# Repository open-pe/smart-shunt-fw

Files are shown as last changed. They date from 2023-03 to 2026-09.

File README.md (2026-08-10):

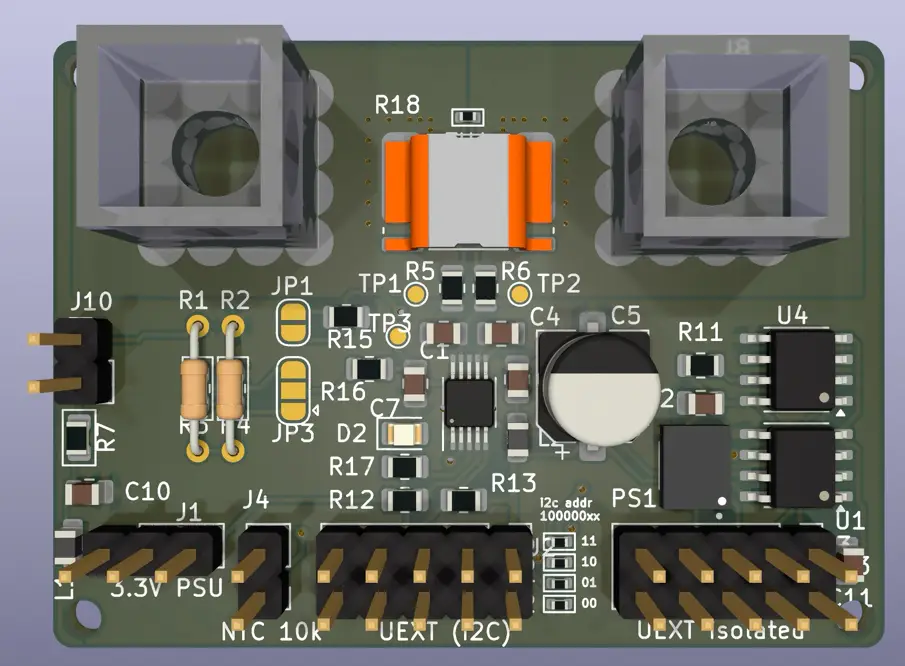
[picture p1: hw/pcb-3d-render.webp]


A versatile isolated power monitor based on INA228.
I made this for precision power metering and testing DCDC converters.

* Digital Signal isolators for i2c and alert
* Isolated power supply
* battery connector
* optional Vbus voltage divider for dc bus voltages above 85V
* programmable i2c address
* NTC for shunt temperature measurement (in addition to the INA228 internal temperature sensor)

# Building

## Platformio Setup

* [install script](https://docs.platformio.org/en/latest/core/installation/methods/installer-script.html)
* [setup shell commands](https://docs.platformio.org/en/latest/core/installation/shell-commands.html)
* [clion](https://docs.platformio.org/en/latest/integration/ide/clion.html)

select the board:

`pio run -e esp32s3`
or
`pio run -e stm32h5`

# TODO

- add ssa-100 plug?
- add ntc
- add pin header for chassis mount resistor
- jumper to disconnect on-board shunt?
- add RSN-50-50 footprint (no available)
- add external alert (for OC shutdown)
- add external IO pins?

Supported ADC:

* ADS1115 / ADS 1015 (for example with SSA-100)
* INA226 (16-bit)
* INA228 (20-bit, 85V)
* ADS1262 (32-bit)
* ADS131M0x (24-bit sim. sampling)
* TODO ADS127L11

On startup it detects the ADCs on the I2C bus using there default addresses.

I tested it on these MCUs:

* ESP8266
* ESP32
* ESP32-S3

The program reads voltage and current and computes power.
It integrates power for energy measurement using the trapezoidal rule.

# Output

* Serial (human friendly logs)
* UDP messages using InfluxDB line protocol

# Voltage Divider Resistors

Resistors with low temperature drift are favourable. Tolerance is not so important because we can simply calibrate.
Consider the ADC input impedance when designing the voltage divider.
Thin film or metal film resistors. Cheap ($.5) SMD chip resistors with 10ppm/°C.
Resistors with 5ppm/°C drift cost $2.
Choose resistors with equal drift, so drift get eliminated.

# Current Sense Resistors

https://www.researchgate.net/profile/Gunnar-Fernqvist/publication/224304168_Characteristics_of_burden_resistors_for_high-precision_DC_current_transducers/links/65ad0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
https://accelconf.web.cern.ch/p07/papers/MOPAN071.pdf
"The highest precision is offered by a proprietary Zeranin wire design from Hitec,"
=> Bulk Metal Foil or “foil”.

https://accelconf.web.cern.ch/p77/PDF/PAC1977_1810.PDF




10A <1ppm reference https://cds.cern.ch/record/643293/files/cer-002399330.pdf

https://www.datatec.eu/caenels-ct-100-c
https://www.datatec.eu/stromwandler-dcct
https://www.datatec.eu/caenels-ct-100v-p

A CT100-P with Y007810R0000B9L (10ohm, 0ppm/K) or 4-terminal Y169025R0000T9L (25ohm, 0.2ppm/K)
with 25ohms: 25mV/A (equiv burden 25mΩ, and almost no self-heat)

Low drift is important. Drift can be compensated with temperature measurement.
Consider max current and power dissipation. For resistances <=1mΩ it is hard to find low drift SMD chip resistors.
A chassis mount resistor might be a better choice for current measurement >40 A.

Riedon https://riedon.com/resistors/current-sense/
VPG

RUG-Z isabellenhuette

# Current Reference

https://doc.xdevs.com/doc/_Metrology/wang2014.pdf

# Resistor References

Tinsley 1682 https://www.ebay.com.au/itm/385633870779
J.L. William Scientific Instruments 0.1 Ohm Cal Standard DC Resistor (SN: 3127) (10 amp)
3928 (14amp)

## SMD Resistors

| MFR | MPN | mΩ  | P | Imax | tol | TCR | padW/mm | padH/mm | 4wire | px100 | |
|---|---|-----|-----|---|-----|---|---|---|---|---|---|
| isabellenhütte | BVR-Z-R0003-1.0 | .3  | 11W | | 1%  | 20ppm | 5.5 | 1.6 | y | $1.9  | |
| bourns | CSS2H-2512R-L300F | .3  | 6W  | | | 150ppm(50ppm) | 3.4 | 1.8 | n | $ | |
| Milliohm (CN)  | HoLRS5930-0.3mR-1% | .3  | 7W  | | 1%  | 50ppm | 7.6 | 4.2 | n | $.24  | |
| vishay | WSLP5931L3000FEA | .3  | 10W | | 1%  | 175ppm | 7.75 | 5.2 | n | $1.7  | |
| RESI (CN) | SEWF3951DL300P9 | .3  | 15W | | .5% | 25ppm | 13 | 2 | n | $2.2  | |
| isabellenhütte | BVR-Z-R0005-1.0 | .5  | | | 1%  | 20ppm | | | | | |
| | BVR-M-R0007-1.0 | .7  | 8W  | | 1%  | 20ppm | | | | | |
| | BVR-M-R001 | 1 | 7W  | | | 50ppm | | | | | |
| vishay | Y14880R00100D0R | 1 | 3W  | | .5% | 15ppm | | | y | | |
| | WSK12161L000FEA/B | 1 | 3W  | | .1% | 20ppm | | | | | |
| | Y14880R00200B9R | 2 | 3W  | | .1% | 15ppm | | | y | | |
| | Y14730R00300B0R | 3 | 3W  | 31A  | .1% | 5ppm | | | | | |
| | Y14750R10000B9R | 100 | | | .1% | 10ppm | | | | | |
| vpg | PCS301 | | | 15A  | | 15ppm | | | | | [pdf](https://vpgfoilresistors.com/products/current-sense-resistors/pcs301/datasheet) |
| | SHR 4-2321 0R005 S 1% M | 5 | 40W | | | 5ppm | | | | | |
| | SHR 4-2321 0R005 S 1% L | 5 | | | | 2ppm | | | | | |
| | PCS 301 0R100 S 1% | 100 | 30W | | 1%  | 3ppm | | | | | |

[Digikey Chip Mount Resistors 40ppm 1mΩ ](https://www.digikey.de/short/8dbrqrp4)

TODO TCR curve
https://docs.rs-online.com/2d4e/0900766b81142cbf.pdf

Choose Chassis Mount resistor, suchs as the 1mOhm RSN-100-100B with 15ppm/k

## THT Resistors



Riedon PCS (10ppm, 40W)
PCS-0R001D1

| MPN | mΩ | tol | P | Imax | TCR | px  |
|---|----|-----|-----|---|---|-----|
| VPG Y07340R05000G9L | 50 | 2%  | 10W | 14A  | 2ppm  | $82 |
| Riedon PCS-0R001D1  | 1  | | 40W | 200A | 10ppm | $40 |
| Riedon PCS-0R002D1  | 2  | .5% | 40W | 141A | 10ppm | $40 |
| Riedon PCS-0R005D1  | 5  | .5% | 40W | 89A  | 10ppm | $40 |
| PCS-0R01D1 | 10 | | 40W | 63A  | 10ppm | |
| | | | | | | |

Riedon USR 4- 3425 (3ppm, 30W, 0.01%)

## Chassis Mount Resistors

These commonly have lower tolerance and lower temp drift as compared to chip mount.
The larger surface of the resistive material and larger terminals decreases thermal resistance to ambient, which
reduces temperature rise.

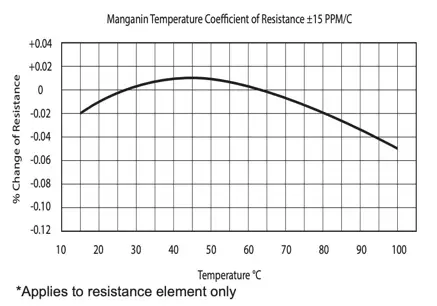
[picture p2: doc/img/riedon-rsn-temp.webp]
|  |
|:-----------------------------------:|
|  Manganin (Riedon RSN, RSW and RS)  |

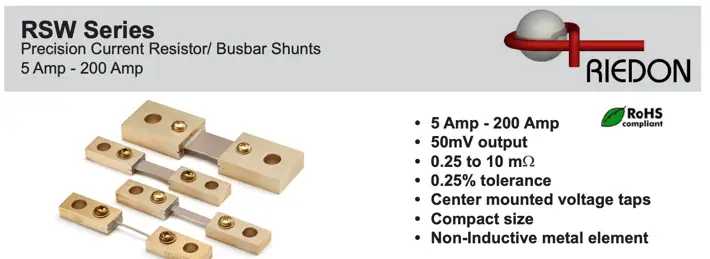
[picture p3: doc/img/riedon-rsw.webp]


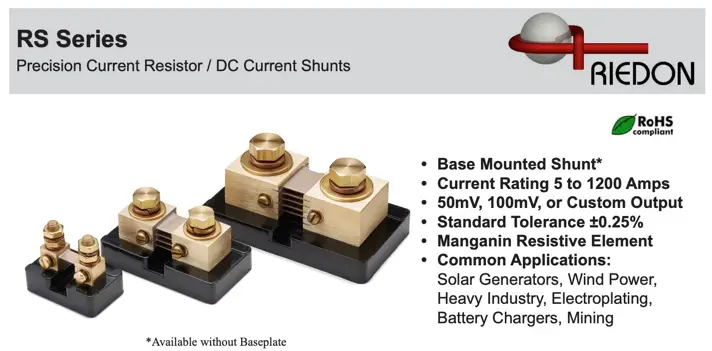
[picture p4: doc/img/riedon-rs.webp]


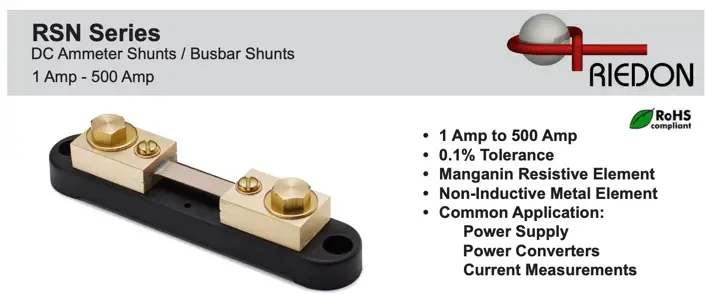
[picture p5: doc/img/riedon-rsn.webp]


| | mΩ | P | Tol | TCR/K  | px |
|---|----|---|---|---|---|
| Riedon RSW-50-50 | 1  | | 0.25% | 15ppm  | |
| Alpha FNPZR0040F | 4  | 500w | 1% | 1ppm | $1060 |
| Alpha FNPZR0010B | 1  | 500W | 0.1%  | 1ppm | $1040 |
| FNPYR0020A | 2  | | 0.05% | 2.5ppm | $540  |
| Riedon RSN-100-100B | 1  | 10W  | 0.1%  | 15ppm  | $60 |
| RSA-50-100 | 1  | 5W | 0.25% | 15ppm  | $30 |

## for battery monitoring

* SMD chip resistors are way cheaper (such as HoLRS5930-7W-0.25mR-1% )

| | mΩ | I(A) | tol | | | px |
|---|----|---|-----|---|---|----|
| Milliohm HoFL2-75A-75mV-0.5% | 1  | 75 | .5% | | | $5 |
| RESI ARCS8518JL100A9 | .1 | | .5% | | | |
| Milliohm HoFL3-8518-A-100uΩ-1% | .1 | | | | | |
| HoFL2-200A-60mV-0.5%-HS | .3 | 200  | | | | |

# 30A

ina228 has a shunt voltage range of 40.96 and 163.84 mV.
at a voltage drop of 40mV and 30A, we have 1.2 W of heat dissipation.

# applications

* bms/battery current sennsor
* smart shunt / lab shunt
* solar crowbar
* efuse
* mppt sensor

# set conversion time and averaging

* consder aliasing
* the ina22x ADC samples AND we sample the ina22x
* use conversion time to avoid aliasing during ADC
* use averaging to avoid aliasing during sampling the ina22x (i2c)
* when working with 50hz inverters, need a conversion time <=1ms.

# precision

* note that resistors change there resistance with temperature (see datasheet)
* use precision resistors
* keep temperature stable
* when measurement DCDC converter efficiency use 2x identical hardware. same chips and same resistors
* INA228 temp coefficient is 20ppm/°C, so choose resistor in that class
    * Ina228 features a temperature sensor

# AC Metrology

* Ti Design TIDU455A (MSP430AFE253, 24 Bit DeltaSigma ADC), class 0.2% accuracy
* Ti Eval Board EVM430-I2040S (MSP430I2040, 24bit, 8Khz or 80th harmonic of 50 Hz), <0.2% accuracy
    * AC, DC, 380V, 15 Amps
* Gossen Metrawatt Metrahit Energy (Starline Series) and
  Open-Source [IrDA USB](http://lemmini.de/IrDA%20USB/IrDA%20USB.html) (the Gossen USB X-Tra needs proprietary drivers,
  for windows only)
    * ESP32 has `UART_MODE_IRDA`, you only need the TFDU4101 [forum1](https://esp32.com/viewtopic.php?t=2766)

https://www.ti.com/lit/ug/tidua01/tidua01.pdf
https://www.analog.com/media/en/technical-documentation/data-sheets/ad637.pdf

* synchrounus subsampling (needs fast ADC)

* log-antilog

Thermal RMS Converters for ultimate


# EVM430

- the software "calibrator-20121120.exe" referenced in the datasheet is out-dated. I could not find a downlo
- use [MSP-EM-DESIGN-CENTER](https://www.ti.com/tool/MSP-EM-DESIGN-CENTER)
  , [intro](https://software-dl.ti.com/msp430/msp430_public_sw/mcu/msp430/EnergyMeasurementDesignCenter/1_40_00_03/release/EnergyMeasurementDesignCenter_1_40_00_03/docs/users_gu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)
  . works on Windows, Mac, Linux
- voltage sense (C14)  pin 1 and 2, A0.0+ and A0.0-
- Current Sense (C10) pin 3 and 4, A1.0+ and A1.0-
- there is a project "EVM430-i2040S_SH_1V_1C_50Hz"
- Double click the MCU and "Generate Code"
- Open generated src code project with CCSTUDIO
    - Could not get the online version to open the project (https://dev.ti.com/ide/)
    - the download IDE based on eclipse succeeded to build the generated project, but need MSP-FET programmer. not sure
      if an ordinary USB2UART addapter works?

# Isolated Current Sensor

DC-DC: MIE1W0505BGLVH-3R-Z (monolithic)
i2c: TPT72616-SO1R (3peak)

# Calibration

```

ina22x-resistor-range 0.000333333333333333 120
calibrate ESP32_INA228 U 1.00
calibrate ESP32_INA228 I 1.00

ina22x-resistor-range 0.0025 16
ina22x-resistor-range2 0.002 20  
ina22x-resistor-range3 0.002 20  

ina22x-resistor-range 0.001 40 
ina22x-resistor-range2 0.002 20 
ina22x-resistor-range3 0.002 20 

calibrate ESP32_INA228 U *1.000041
calibrate ESP32_INA228_2 U *1.000041
calibrate ESP32_INA228_3 U *1.0000233720530345

calibrate ESP32_INA228 I *1.0001119027192362
calibrate ESP32_INA228_2 I *0.9999067668612132

calibrate ESP32_INA228_3 I *1.0056727470362443

calibrate ESP32_INA228_2 U *1.00005
calibrate ESP32_INA228_3 I 1.0

calibrate ESP32_ADS1220 U *0.9985899493319389

calibrate ESP32_INA228 U *1.000032503295473
calibrate ESP32_INA228_2 U *1.000032503295473

calibrate ESP32_ADS1262 U 1.011406869687194   # an1->gnd
calibrate ESP32_ADS1262 U 1.0   # an1->gnd

calibrate ESP32_ADS1262 U 0.99882990

calibrate ESP32_ADS1262 U 1.01045

```

# Reference Designs

### LP-XDS110ET

[Design Files](https://www.ti.com/tool/LP-XDS110ET#design-files)

* ADC: ADS127L01IPBS
* Ref: REF6025IDGK (drift: 5ppm/K, noise: 5 µVRMS)
* Clock: SN74LVC2G74DCU
* Diff. Amp: THS4551IRUN
* Current Sense Amp: INA118UB

### ADS131B23



# Going Further

| error type | mitigation | effort |
|---|---|---|
| gain error | single point calibration | low |
| gain temp drift | temperature measurement | medium |
| non-linearity | multi-point calibration (LUT) | medium |
| noise | averaging | low |

Simulatnous 2ch sampling instead of multiplexing.
Alternative: use 2 ADC chips

* ADS127L01 + THS4551 + INA169? ( see LP-XDS110ET circuit )

ADS131B23:

* 2x 24bit for redundant current measurement
* 1x 16bit for voltage measurement

# Selection Criteria

* Simultaneous sampling
    * more precise AC power sampling
    * easier to program
* PGA gain of >= 64
    * enable FSR of 40mV to directly measure voltage across current sense resistor without additional
      amplifier
* Linearity
    * Linearity can be improved with a look-up-table. Creating these tables require multi-point calibration.
    * Compare linearity error from the ADC data sheet to the temp drift of current sense resistor

# Voltage References

| MPN | drift/K | noise | initial accuracy | |
|---|---|---|---|---|
| REF6025IDGK  | 5ppm | 5 µVRMS  | ±0.05% | |
| REF6225IDGKT | 3ppm | 5 µVRMS  | ±0.05% | [pdf](https://www.ti.com/lit/ds/symlink/ref6225.pdf) |
| LTC6655 | 2ppm | | ±0.025% | for use with  LTC2508-32 |
| LTC6652 | 5ppm | | 0.05% | |
| LTZ1000 | 0.05ppm/°C | 1.2µVP-P | | for calibrators |



https://youtu.be/upTgM_S5rAQ?si=JQq38q3_NsaYmSlv&t=2213

Fluke732A

https://github.com/marcoreps/ADRmu

Reference of all References
https://hackaday.com/2015/12/03/nuts-about-volts/
https://www.ptb.de/cms/service-seiten/news/forschungsnachricht.html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




# Voltage Divider

VHD200 (digikey 15 weeks )
100mW. for measuring 80V at 2V ADC min 64k r_total


# Amps

THS4521 (ref6225)

# ADC Break-outs

https://protocentral.com/product/ads1115-16-bit-adc-4-channel-with-programmable-gain-amplifier/

https://protocentral.com/product/ads1220-24-bit-4-channel-low-noise-adc-breakout-board/

https://protocentral.com/product/protocentral-ads1262-32-bit-precision-adc-breakout-board/

https://www.mikroe.com/adc-15-click

https://www.waveshare.com/18983.htm (ADS1263)

MIKROE-4743 (ADS1262) 

# Misc

# Resolution and Noise

from https://www.ti.com/lit/ds/symlink/ads1231.pdf :
The RMS and Peak-to-Peak noise are referred to the input. The effective number of bits (ENOB) is defined as:
ENOB = ln (FSR/RMS noise)/ln(2)
Noise-Free Bits = ln (FSR/Peak-to-Peak Noise)/ln(2)
FSR (Full-Scale Range) = VREF/Gain.

https://electronics.stackexchange.com/questions/274606/whats-the-highest-precision-achieved-for-an-adc

Let's consider the application of measuring conversion efficency of a DC/DC converter.

According to the data sheet, INA228 measures power with total meusurement
error of 0.5% at full scale. We need two power monitors, one at the input and one at the output, total worst case error
of two devices is around 1%.

This error is too high, considering the DC/DC has an efficiency of > 95 %.
So let's have a look at more precise alternatives.

First

| | | |
|---|---|---|
| Gain Err (max) | ±0.05 % | |
| Gain Temp Drift (max) | 20 ppm/°C | |
| ADC Resolution | 20 bit | |
| Integral Non-Linearity | 20 ppm | |
| Differential Non-Linearity | 0.2 LSB | |

For noise analysis, we need to define ADC measurement range and AC component frequency.
What is the ripple current, voltage and frequency?
Is the ripple periodic?
Is the ripple neglictable?
Can we smooth is out with a LP filter so we can assume DC only?
What digital filter does the ADC have?
Do we need an analog filter? Do we need to filter Aliasing?

TODO

* zero cross detection?
* AC metering?
* simulatnous filtering AC?

To work with some numbers, we define a working point:

- max current 40A
- current sense resistor 1mΩ
- max heat: 1.6 W (i2r)
- max voltage 40mV

* define a sampling rate
    * do we need to capture AC component or can we filter them?
    * if reactive power matters, we need simultanous ( https://www.ti.com/lit/an/slaa638a/slaa638a.pdf )

"The sample frequency is [...] 8 kHz that give us Nyquist
bandwidth of 4 kHz. This bandwidth is sufficient to cover the 66th harmonic for 60Hz AC, 80th harmonic for
50Hz AC frequency as wider bandwidth is usually needed for server power monitoring due to the nature of the
switching power supplies being monitored." -https://www.ti.com/lit/an/slaa638a/slaa638a.pdf

* :
* (max):
*

Note 7: Integral nonlinearity is defined as the deviation of a code from a
straight line passing through the actual endpoints of the transfer curve.
The deviation is measured from the center of the quantization band.

- https://www.ftcelectronics.sg/datasheets-58/LTC2508CDKD-32-TRPBF.pdf

# SPI Isolators

https://www.analog.com/media/en/technical-documentation/data-sheets/LTC6820.pdf
(needs 2 chips and 2 transformers)

https://www.mikroe.com/spi-isolator-5-click
using DCL541A01 (150Mbps, 3f/1r channels, default Low out)

https://www.electronics-lab.com/project/4-channel-spi-interface-isolator-with-three-forward-and-one-reverse-direction-channels/
based on ISO77418 (100Mbps, 5000V iso, 3f/1r ch, default High out)


# Tools

https://www.vishay.com/en/resistors/change-resistance-due-to-rtc-calculator/

# Heaters

https://www.amazon.de/Fyearfly-Temperatur-Heizplatte-Silikonkautschuk-elektrische/dp/B09MJ96BHK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
https://www.digikey.de/en/products/detail/dfrobot/FIT0845/15848056
https://www.amazon.de/sourcing-map-selbstklebende-Heizelemente-Heizstreifen/dp/B0CTT8DCNG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
https://electronics.stackexchange.com/questions/631263/using-mosfet-as-a-voltage-controlled-current-source


https://www.digikey.de/en/products/detail/innovative-sensor-technology-usa-division/HST-P11R0-1010-63A-2L-020/21407273


https://www.digikey.de/en/products/detail/riedon-products-by-bourns/PTCA-40/10271325

# Peltier

https://www.farnell.com/datasheets/4020641.pdf

# Heating Circuit

We want a precise temperature control loop to stabilize temperature of the resistive element.
The heater should be somehow coupled to the resistor for good heat transfer and it also needs
a heat-sink. We decide against PWM, since efficiency is not an issue, as we want to generate
heat anyway and it might cause unnecessary switching noise.

A linear control loop appear to make most sense. There are circuits like



the NTC is a LC471F3K, nominal 470 X at 25 °C, which acts as a sensor and heating element.

Despite the simplicity of this circuit, it not suitable in our application.
Measuring the temperature at the resistive element is important, since the resistor itself will produce heat.
Also finding an NTC with suitable power will likely be difficult.

We will measure

https://www.wellesu.com/10.1016/j.compag.2016.06.011
https://dr.lib.iastate.edu/server/api/core/bitstreams/d64d1b18-f1b3-41cd-be34-bc21360b506e/content
https://electronics.stackexchange.com/questions/690961/i-dont-understand-this-temperature-controller-circuits-behaviour
https://electronics.stackexchange.com/questions/498065/anemometer-with-opamp

https://www.circuitlab.com/circuit/63742k8e26j4/ntc-heater-control/

# Increasing Precision

The INA228 data sheet mentions a power monitoring accuracy of 0.5%. For monitoring DC/DC converters
with efficiencies of 95% or higher, INA228 accuracy is not sufficient. The integrated 0.5% precision oscillator adds
even more error for energy measurement.

# ADS1262 Journal

* ordered from protocentral
* are these genuine chips?
* review passive component circuitry of break-out board
* ads1262 needs at least 4.75V analog supply voltage !
* prefer MIKROE-4743 from digikey
* with PGA need at least 0.3V margin to rails (see Datasheet)
* linearity issue
    * sth appears to be wrong
    * absolute error seems quite high
    * maybe there is something wrong with the code?
* ads1220 appears to perform quite well
    * todo need spi isolator

# Measuring Single-Ended Signals with Diff-ADC

https://www.ti.com/lit/an/sbaa133a/sbaa133a.pdf?ts=1738999464967


THS4551







LTC2057 + LTC2508-32

# Current sense ampplifiers

MCP6C02

# Instrumentation AMps

- focus on precision (low noise, low offset, linearity)
- differential gain
- high CMRR
- high input impedance, low output impedance




https://www.ti.com/lit/ds/symlink/ina118.pdf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,0,96
https://www.ti.com/solution/battery-cell-formation-test-equipment?variantid=34913&subsystemid=292016

| | | max gain | noise | offset voltage (max) | offset drift (max) | gain drift ppm/K  G=1/G>1 | gain nonlinearity | common mode rej | |
|---|-----|---|---|---|---|---|---|---|---|
| **INA190** | | | 75 nV/√Hz | ±15 μV | 0.08 uV/°C | 7 ppm/°C | 100ppm | | |
| INA848 | | 2000 (fix)  | 1.5 nV/√Hz | 35µV | 0.45 μV/°C | 5 | 10ppm | 132dB (min) | |
| **INA851** | | 1000 | 3.2 nV/√Hz | 35 µV | 0.3 µV/°C | 5/35 | 5ppm  (typ) | 120db (min) | with fully diff outp. |
| INA849 | | 10000 | 1-nV/√Hz | 35 µV | 0.4 μV/°C | 5 | 10ppm | | for bat test |
| INA826 | | | 18 nV/√Hz (G>=100) | 150 µV | | 1/35 | 5ppm | | bat test |
| ina828 | | | 7 nV/√Hz | 50 µV | 0.5 µV/°C | 5/50 | 15ppm | | |
| INA2128 | | | 8 nV/√Hz at 1 kHz | 50µV | 0.5 µV/°C | ±10ppm | | 120db (min) | |
| INA103 | | | 1nV/√Hz | | | ? | 100ppm | | |
| **INA818** | | | 8 nV/√Hz | 35µV | | 5/35 | 15ppm (max) | | |
| INA118 | | | 10nV/√Hz | 50µV | 0.5 µV/°C | | 20ppm | | |
| INA333 | | | 50 nV/√Hz | 25 μV | 0.1 μV/°C | | 10ppm | | |
| AD624C | | | | | | | | | |
| LTC6915 | $9  | 4096 (prog) | 2.5µVP-P (0.01Hz to 10Hz) | 10µV | 0.05µV/°C | | 15ppm  (max) | | |
| INA241A | $3  | | 28nV/Hz | 10µV | | 1ppm | 10ppm | | |
| LTC1100 | $18 | 10 or 100 | ■ 0.1Hz to 10Hz Noise: 1.9µVP-P | 10uV (typ 1µV) | 0.1µV/°C | 4ppm | 8ppm (max) | | |
| **LTC2053** | $10 | 1000 | 2.5µVP-P (0.01Hz to 10Hz) | 10µV | 0.05uV/°C | 0 | 3(typ) 12 (max) | 116db (typ) | |
| LT1167 | | | 0.1Hz to 10Hz Noise: 0.28μVP-P  | G = 10, 60μV Max | 0.3μV/°C | 50ppm ? | G = 10, 10ppm Max | | |
| LTC6363 | | | 0.2µVpp, DC to 10Hz (Typ) | | 0.015μV/°C | | | 150db (typ) | |
| MCP6C02(G=20) | | | <=1Hz:0.48μVpp, 1.54 | G=20: 16µV | 0.09 µV/°C | 5ppm | 50ppm/100ppm | | current sense amp |





LNA10 (OPA4727) see https://www.youtube.com/watch?v=NoCp6cz32yo
Stanford Research SR560

https://www.thorlabs.com/thorproduct.cfm?partnumber=AMP100
https://github.com/marcoreps/low_noise_amplifier


LTC2057HV + LT1991A

# Op Amps

OPA4727
offset: 15µV (typ), 150µV (max)
drift: 0.3µV/°C (typ), 1.5µV/°C (max)
BANDWIDTH: 20MHz
LOW NOISE: 6nV/√Hz at 100kHz
AOL > 110dB

OPAx209
(higher drift, lower noise)
: 2.2 nV/√Hz at 1 kHz
Low Offset Voltage: 150 µV (Maximum)
drift: 3 µV/°C (max)

OPAx189
– Zero-drift: 0.005 μV/°C

- Ultra-low offset voltage: 3 μV maximum
  – CMRR: 168 dB
- en at 1 kHz: 5.2 nV/√Hz
- 0.1-Hz to 10-Hz noise: 0.1 µVPP

OPAx388

- offset voltage: ±0.25 µV
- drift ±0.005 µV/°C
- 140-dB CMRR
- Low noise: 7.0 nV√Hz at 1 kHz
- No 1/f noise: 0.14 uVPP (0.1 Hz to 10 Hz)
- https://www.ti.com/solution/analytical-lab-instrumentation#block-diagram
-

# Youtube

https://www.youtube.com/watch?v=upTgM_S5rAQ
https://www.youtube.com/watch?v=NoCp6cz32yo

# Literature

https://docs.ampnuts.ru/eevblog.docs/HP_Agilent_Keysight/HP%203458A%20Component-Level%20Information%20Packet.pdf
https://vtda.org/pubs/HP_Journal/HP_Journal_1989-04.pdf
https://doc.xdevs.com/doc/HP_Agilent_Keysight/3458A/ac_algo/Swerleins_Algorithm.pdf

* highest accuracy for lowest freq

# DataLogging

https://github.com/marcoreps/multiinstrumentalist

* HP3458A
* HP34420A
* W4950
* F8508A
* K2182A
* D1281

# Temp Sensors

TMP117 (i2c)

# ADC

important for dc metrology: stability and linearity (DC to 103- 104 Hz )
https://www.researchgate.net/publication/325285614_Analog-to-digital_conversion_beyond_20_bits_Applications_architectures_state_of_the_art_limitations_and_future_pro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

https://www.ti.com/lit/ug/tiduco9b/tiduco9b.pdf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

https://indico.cern.ch/event/814368/contributions/3397918/attachments/1832255/3000935/Class_0_ADC_-_Beev.pdf

https://www.welectron.com/Digilent-MCC-172-IEPE-Sensor-DAQ-HAT-for-Raspberry-Pi-2-CH-24-bit

# Thermal EMF

https://www.ab-precision.de/products/cables-accessories/

https://www.ni.com/docs/de-DE/bundle/ni-switch/page/thermal-emf-and-offset-voltage.html

https://www.youtube.com/watch?v=EW58sm8ciWk


https://www.youtube.com/watch?v=KiYhEP6m7Pc


https://dam-assets.fluke.com/s3fs-public/p18-21.pdf

https://www.eevblog.com/forum/metrology/binding-postsbanana-sockets-cleaning-on-dmmsmetrology-lab-gear/

https://www.eevblog.com/forum/chat/help-wanted-low-and-high-ohm-measuremet/?action=dlattach;attach=35289

Pomona 2305

diy Fluke 5440A-7003
https://www.eevblog.com/forum/metrology/diy-low-emf-cable-and-connectors/msg545213/#msg545213

Riedon RSN Brass Terminals:
Thermal EMF to copper wire ~2µV, at 50mV FSR this is 40ppm.

# Gold Plated Banana Plugs

CT3099


[Pomona 4897-2](https://www.digikey.de/en/products/detail/pomona-electronics/4897-2/737024)

https://mm.digikey.com/Volume0/opasdata/d220001/medias/docus/4846/DS_1768_Catalog.pdf

Multicomp 1699021

Farnell has more than digikey

# Kelvin Clips Gold Plated

CTM-78K
CTM-75K

# Linearity, INL

https://xdevs.com/article/inlperf/



# CERN HPM7177 (open soruce) DMM

https://ohwr.org/project/opt-adc-10k-32b-1cha/-/wikis/home
base on AD7177-2
effective resolution >23 bits for BW < 10 Hz
temperature drift (offset and gain) <0.1 ppm/°C from 20°C to 40°C
INL <0.6 ppm (0 to +10 V)



# Notes on Precision

High-Precision (ppm range) current sensing can be tricky due to thermal effects.
Most resistors have a positive temperature coefficient when they heat up, so current is measured too high.
A closed-loop temperature control of the current sense resistor can improve stability.
There are Vishay VPG resistors with 0ppm/K or <1ppm/K, but only in the sub-1W range, so not suitable for higher
currents.
Low burden voltage decreases resistor heating but Thermoelectric noise (thermal EMF) becomes more dominant.
Use as few material boundaries, not connectors, no gold, just copper. Use un-finished copper trace to contact resistors
with screw terminals, which are usually some sort of brass.

Offset drifts can be compensated with a chopper circuit, that frequently bypasses the load current and measures the
offset current
which is then compensated in following measurement.

If you want to measure ratio of currents, use the same sense resistors and chop both currents over it to eliminate
drift.
This way any error produced by the resistor is eliminated, offset by thermal EMF is still relevant and the ADC
performance
(offset and linearity).

For best linearity, highest thermal imunity and lowest drift, consider using DC-current transformers (DCCT).

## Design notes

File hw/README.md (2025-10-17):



This is a energy monitor based on the INA228.
It comes with a Würth PowerPlus M5 terminals and a 4026 shunt resistor slot for resistors from e.g.
Bourns, Vishay, Isabellenhütte.
Alternately you can use chassis mount resistors such as the Riedon RSN series with very low temperature drift.

The board comes with an isolated dc-dc and i2c isolator (and another isolator for the alert signal).

## Measuring voltage >85V

Although the INA228 only supports Vbus up to 85V you can measure much higher voltages (I tested up to 400V DC).
Put the shunt on the ground sound and populate the voltage divider with THT precision resistors or SMD chip resistors.

For high voltages higher than 85V the `IN-` pin must be pulled to ground. There will be a lot of noise otherwise.

# isolators

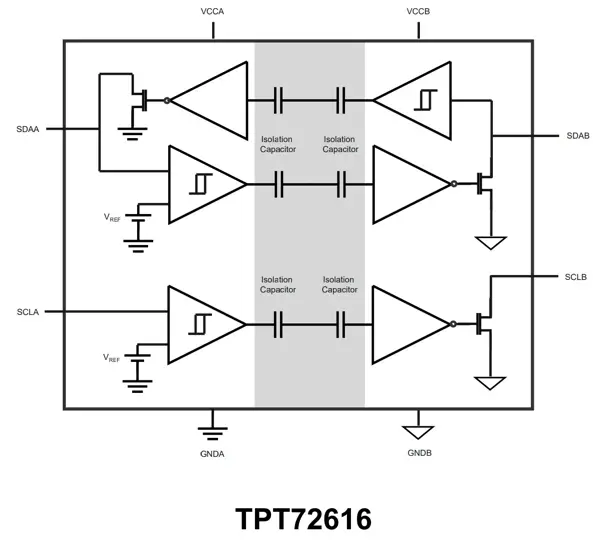
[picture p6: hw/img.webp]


TPT774x:

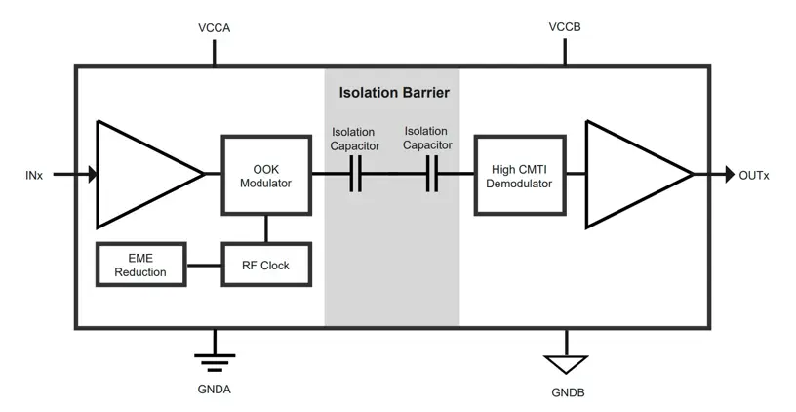
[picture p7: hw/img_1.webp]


TPT7721-SO1R:
2 ch

FXMAR2102UMX:
2ch bidirectional! $.32

INA241

* motor drives
  https://www.ti.com/de-de/video/6314459715112

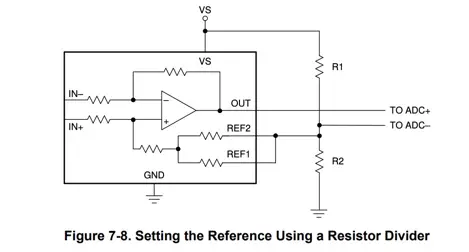
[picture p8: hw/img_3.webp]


INA296A

* Version A: ±0.01%, ±1ppm/°C drift
* app: Test & Meausrement
* https://github.com/CrabLabsLLC/OpenMD/blob/develop/docs/Schematic.pdf
*

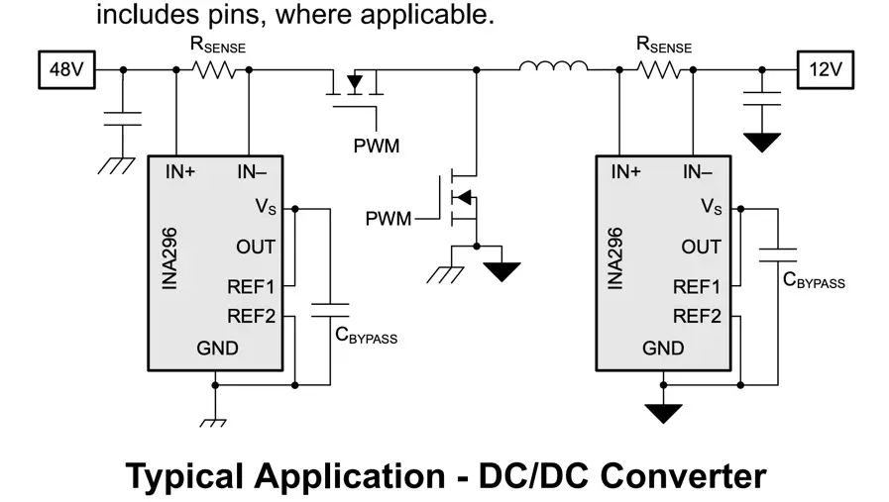
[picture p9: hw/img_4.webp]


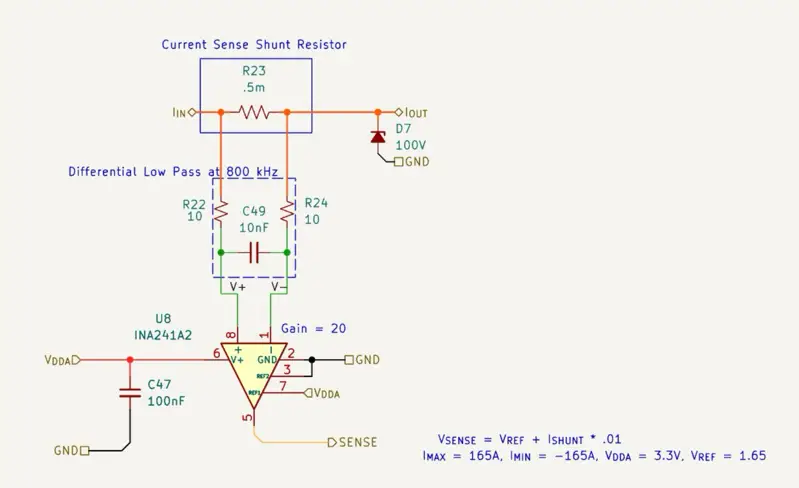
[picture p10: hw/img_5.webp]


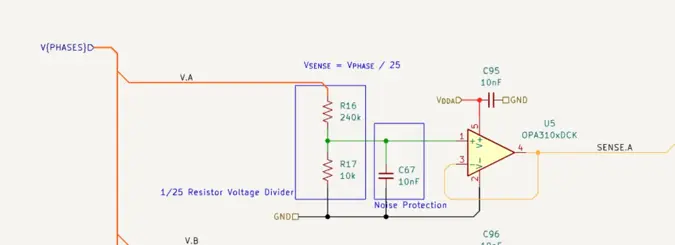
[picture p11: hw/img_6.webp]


TPA6271:
110V 16bit power monitor

| | Vbus | CMRR(min) | BW | OffsetErr | Gain Err(max) | NonLinErr | TempDrift  | BiDir? | ShuntVRange | Outp | |
|---|---|---|---|---|---|---|---|---|---|---|---|
| 3peak TPA6271  | 102.4V | 120 dB | 140µs | ±10µV | 0.15% | | 10ppm/C | y | 81.92mV | i2c, 16bit | [pdf](https://static.3peak.com/res/doc/ds/Datasheet_TPA6271.pdf) |
| TI INA226 | | | | | | | | | | | |
| TI INA228 | | 154 dB | | | ±0.05% | ±0.002% | ±20 ppm/C  | y | | | |
| TI INA229 | | | | | | | | | | | |
| TI INA241 | | | | | | | | | | | enhanced PWM-suppr. |
| TI **INA296A** | 110V | 150 dB | 1.1MHz  | ±10µV | ±0.01% | ±0.001% | ±1ppm/°C | y | | | |
| TI INA310A | 110V | 140 dB | 1.3 MHz | ±20 µV | ±0.15% | ±0.01% | 10ppm/C | | | | |
| LMV93x-N | n/a | 60 dB | 1.4 MHz | 4 mV | | | | | | | |
| THS4551 | | | 150 MHz | ±175 µV | | | | | | | |
| AMC1300 | | | | | ±0.3% | 0.03% | ±30 ppm/°C | | | | isolated amp |

We can calibrate Gain Err/ Gain Offset with 2 point calibration.
Non-linearity can be reduced by multi-point calibration (LUT).
TempDrift can be compensated with a temperature sensor and the drift curve from the datasheet.

Non linearity and temp drift are crucial since harder to compensate.

ADC

| MPN | eff resolution | gain | sps | ch | tempDrift | NonLinear | offset  | OffsetDrift | GainErr | GainDrift |
|---|---|---|-----|----|---|---|---|---|---|---|
| ADS1220 | 20bit | 1..128 | 2k  | 4  | 5 ppm/C | | | | | |
| ADS127L21B | | | | | | 0.5ppm | +-250µV | 200 nV/C | | 1ppm/C |
| ADS127L11  | | | | | | | | | | |
| ADS124S06  | | | | | | | | | | |

## Analog Version

- INA296A + ADS1220 (or ADS127L21B)
- SPI need 3 up, and 2 down ch. (or only 1 down?)
- analog level translation for oscilloscope connection. using high-side current sense circuit?
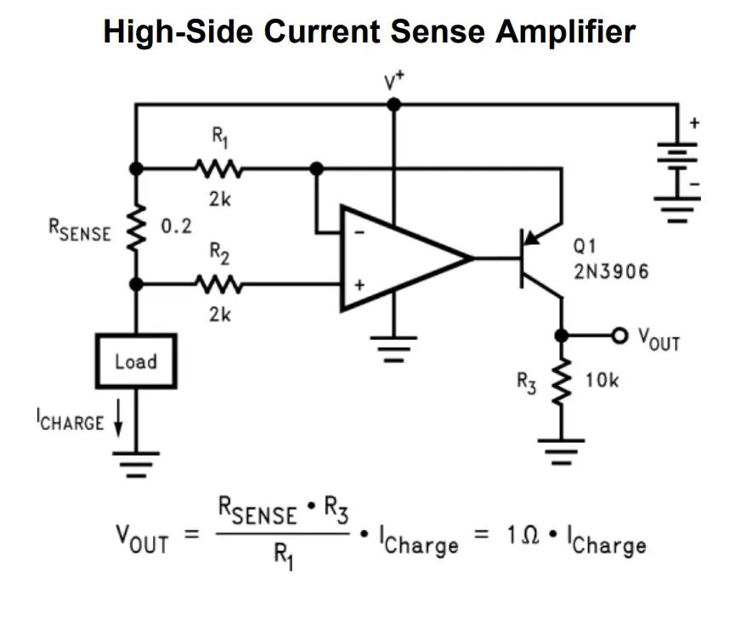
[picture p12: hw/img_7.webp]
   ( LMV93x-N datasheet)
    - unfortunately the INA296 does not give access to (-) inp of

- THS4551 (amp) +

https://www.ti.com/solution/power-analyzer?variantid=34826&subsystemid=23445

PwrTool 500

# Thermal
20A with Y14880R00200B9R 2mΩ temp-rise 18 => 38°C  ∆20°C (ina229 package: 25°C)

# 24bit
REF6225IDGKT
ads127 (
ADS131M02 (apps: power, battery) https://www.ti.com/lit/ds/symlink/ads131m02.pdf

# 32bit
ADS1288

SPI:
CS (->)
SCLK ->
MOSI ->
MISO <-
DRDY <-

ISO6721BDR, 3kv, 50mbps, 2/0ch
ISO6731DWR, 5kv, 50mbps, 2/1ch

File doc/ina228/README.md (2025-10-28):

* datasheet says INL(typ) = 20ppm
* Linearity can be improved with a second order polynom (~2ppm INL)
* polynom is the same for the three tested chips
* non-linearity does not appear to drift
* gain drifts, need to calibrate gain before each measurement
* offset didnt drift across measurements

# INL
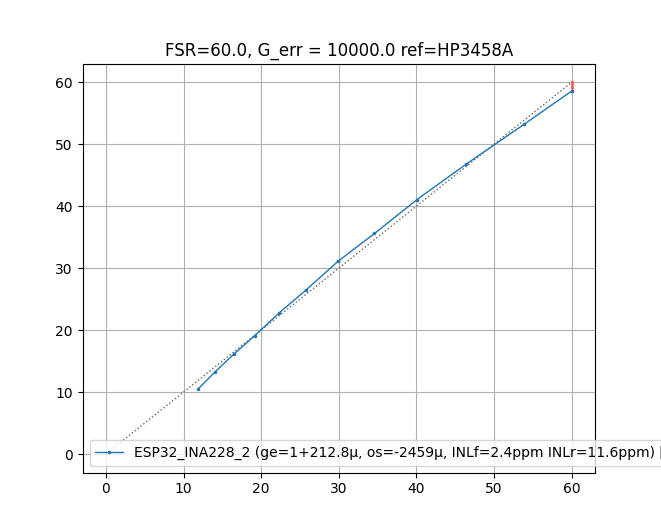
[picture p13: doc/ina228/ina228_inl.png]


- reference HP3458A (nplc=10)
- good INL
- suitable for polyfit
- only Vbus+dietemp measured (conversion time ~4000us)

across devices the curve looks pretty much the same:
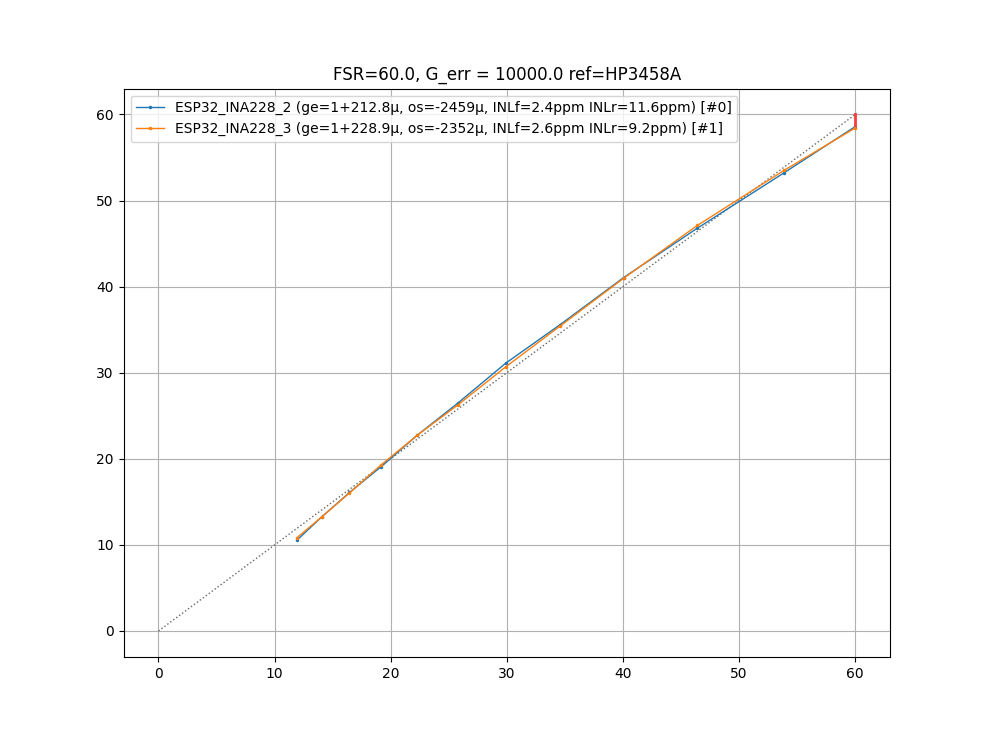
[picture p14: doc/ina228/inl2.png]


going up to 82V reveals more linear error (the DMM6500 continues to do its job very well):
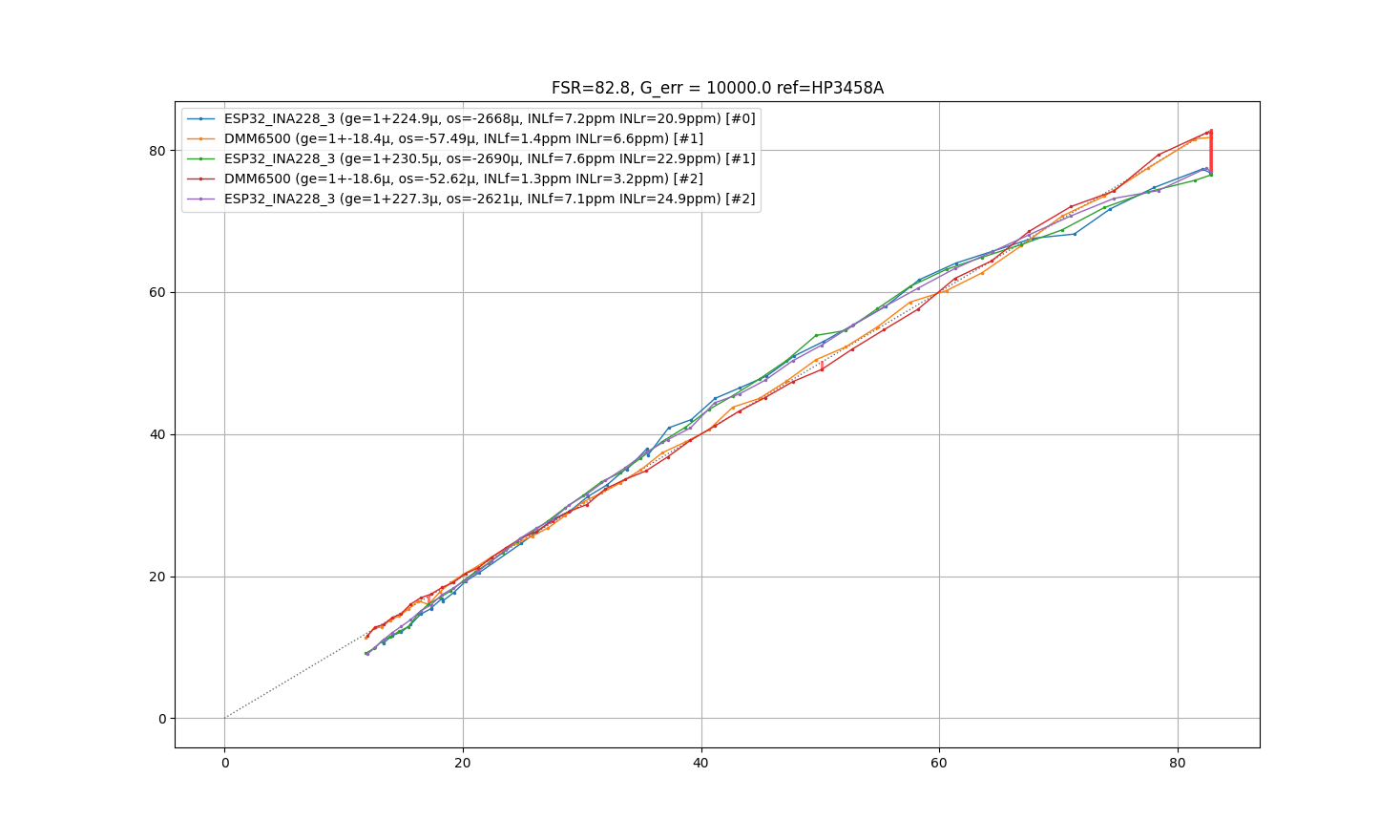
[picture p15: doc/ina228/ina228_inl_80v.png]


notice these measurements where only taken for 90s each with some noise on the power supply.

here is a measurement with another less noisy power supply and 900s (15min) measurements:
TODO 

this looks like we can do a polyfit, and indeed it helps.

# Noise




# etc

current measurements seem to suffer from crosstalk from bus voltage. it changes the offset voltage.
for better precision, use one ina228 for current only and the other for voltage only.
Vbus INL is quite good.
TODO need to measure INL for current

Ina228 with ESP32-S3, WiFi connected



The Esp32 produces significant heat.

Current sense input:
10 ohm series resistors and 100nF cap

6h drift, temperature droping at night: (Vbus open clamps)



suddenly, there was an unexplainable drop for 45 minutes:



shortings Vbus to GND:



- offset voltage of current amp falls near zero.
- ADC temperature rises (due to more conversion iterations?)
- after opening Vbus again it returns to the same offset as before
- connecting a 3.2V battery doesnt change a lot



# Offset Voltage

- best to connect shunt to circuit GND
- change Vbus from 0 to 60V -> current offset voltage changes by 1.4µV
-

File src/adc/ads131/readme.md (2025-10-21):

modes
- high-resolution (HR) mode, low-power (LP) mode, and very-lowpower (VLP) mode
- VLP: low input bias, high impedance (page 10)

https://download.mikroe.com/documents/add-on-boards/click/adc_15_click/ADC_15_click_v100_Schematic.PDF
https://github.com/MikroElektronika/mikrosdk_click_v2/tree/master/clicks

buffer:LTC2057

problem:
not Vref externally accisble!

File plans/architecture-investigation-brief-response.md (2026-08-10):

# Architecture investigation response

Scope: branch `port/stm32h5`, all `.h`/`.cpp` files under `src/` and `ble-bridge/src/`, plus the PlatformIO, board, and partition configuration. This is a findings-only review; no firmware source was changed.

Validation snapshot:

- `pio run -e stm32h5` succeeds: 74,664 bytes flash, 11,360 bytes RAM.
- `pio run -e esp32s3 -t buildprog` succeeds: 1,384,550 bytes flash, 60,772 bytes RAM.
- `pio run -e esp32 -t buildprog` fails. The non-S3 settings branch declares `settings_t_01` but instantiates `settings_t`, NimBLE is not a dependency of this environment, and both target mains are selected.
- `pio run -d ble-bridge -e esp32_ble_bridge -t buildprog` fails because `ble_protocol.h` is outside that project's include path. If the path is fixed as-is, `ble_crc16_update` is then defined both by the header and by `ble-bridge/src/main.cpp`.
- More importantly, the successful STM32 build constructs `StubBleTransport`; `BleBridge` is not included or instantiated anywhere. The current STM32 image therefore has no UART telemetry/aux link despite the intended architecture.

## 1. File inventory

There are 44 `.h`/`.cpp` files totaling 10,005 physical lines (`wc -l`). “Active” means reachable from a successful current build, not merely selected by a source filter.

### Application, services, and support

| File | Lines | Status | Responsibility |
|---|---:|---|---|
| `src/atomicops.h` | 777 | Both, vendored | Moodycamel low-level atomics/semaphore support used by `ReaderWriterQueue`. |
| `src/aux_switch.h` | 123 | Both | Aux GPIO state, EEPROM persistence, command parsing, logging, and ESP deep-sleep pad hold. |
| `src/ble.h` | 695 | ESP32-S3 | NimBLE GATT server, telemetry indication buffering/ack handling, OTA transport, connection tuning, aux characteristic, and callbacks. Also contains a dead alternate BLE implementation. |
| `src/ble_bridge.h` | 171 | Intended STM32; currently unused | `BleTransport` over framed UART, inbound aux/link-status dispatch, and frame parser/writer. |
| `src/ble_protocol.h` | 53 | Intended shared; currently unused by successful builds | UART message IDs, an unused frame header, and Modbus CRC helpers. |
| `src/ble_transport.h` | 25 | Both | Telemetry transport interface and no-op stub. |
| `src/console.h` | 104 | Both | Parses reset, calibration, INA range, aux, and help commands; directly reaches driver globals. |
| `src/energy_counter.h` | 377 | Both | Sample queue, calibration, power/charge integration, stall recovery, windows, logging, wire summary, Influx conversion, and CRC. |
| `src/esp_compat.h` | 85 | STM32 | ESP-style errors/logging/time shims over Arduino STM32, FreeRTOS, and STM32 HAL. |
| `src/i2c.h` | 113 | Both | Global recursive bus lock and register read/write/probe helpers over `Wire`. |
| `src/lcd.h` | 45 | Dormant ESP32 | SSD1306 wrapper; the `WITH_LCD` path is not configured and no code calls `init()` or `updateValues()`. |
| `src/main_esp32.cpp` | 238 | ESP32-S3 | Object graph, setup/tasks, OTA boot validation/watchdog, Wi-Fi/Influx setup, deep sleep, and raw UART setup. |
| `src/main_stm32.cpp` | 86 | STM32 | Object graph, setup, and two tasks; currently selects the stub transport. |
| `src/mean_window.h` | 36 | Both | Running mean/max accumulator. |
| `src/platform.h` | 111 | Both | Time, restart, GPIO hold, sleep, EEPROM, and task-creation wrappers; only time and task creation are used. |
| `src/readerwriterqueue.h` | 982 | Both, vendored | Moodycamel single-producer/single-consumer queue; includes a large commented-out blocking queue. |
| `src/sampler_registry.h` | 68 | Both | Registers samplers, creates counters, and fans out lifecycle/update/reset operations. |
| `src/secrets.h` | 1 | Local ESP32 input | Generated/ignored Wi-Fi AP-list macro. |
| `src/settings.h` | 167 | Both | Board pins, calibration validation, and target-specific EEPROM storage. |
| `src/sui.h` | 2 | Unused | Empty “Serial User Interface” placeholder. |
| `src/telemetry.h` | 115 | Both | Periodic summary publication, console polling, aux publication, activity voting, and idle-sleep dispatch. |
| `src/util.cpp` | 227 | Both | Time formatting, timestamping, I2C scan, logging, Wi-Fi, UDP Influx batching, and dead Point helpers. |
| `src/util.h` | 78 | Both | Declarations for those utilities plus the unrelated `TaskNotification` synchronization class. |
| `ble-bridge/src/main.cpp` | 238 | Relay, build broken | Standalone ESP32 NimBLE relay, UART frame parser/writer, GATT setup, and aux/link callbacks. |

### ADC and sampler code

| File | Lines | Status | Responsibility |
|---|---:|---|---|
| `src/adc/sampling.h` | 80 | Both | Packed `Sample`, `PowerSampler` interface, timestamp declaration, and an obsolete commented timestamp implementation. |
| `src/adc/ina228.h` | 656 | Both | Direct INA228 register I/O, configuration/calibration, ISR routing, polling, conversion, diagnostics, and `PowerSampler` adapter. |
| `src/adc/ina228_mux.h` | 393 | Both | A second INA228 implementation specialized for mux sequencing, zero calibration, diagnostics, plus per-channel sampler adapters. |
| `src/adc/tmp117.h` | 154 | Both | TMP117 sampler interface and the unrelated dummy sampler. |
| `src/adc/tmp117.cpp` | 131 | Both | TMP117 initialization, DRDY polling, checked reads, and error throttling. |
| `src/adc/adc_ads.h` | 199 | Dormant but linked on ESP32-S3 | ADS1115 voltage/current sampler. A global instance exists but is never registered. |
| `src/adc/adc_esp.h` | 55 | Dormant | Legacy ESP ADC one-shot sampler; included by the ESP main but never instantiated. |
| `src/adc/adc_esp_dma.h` | 70 | Unused | Incomplete continuous/DMA experiment that still performs one-shot reads. |
| `src/adc/ads1220.h` | 100 | Dormant | ADS1220 sampler experiment; included but never instantiated. |
| `src/adc/ads1262.h` | 119 | Dormant | ADS1262 `PowerSampler` wrapper; included but never instantiated. |
| `src/adc/ads1262/ads1262.h` | 98 | Dormant third-party-derived code | ProtoCentral-style ADS1262 register driver declaration. |
| `src/adc/ads1262/ads1262.cpp` | 207 | Compiled on ESP32-S3, linker-GC candidate | ProtoCentral-style ADS1262 SPI register implementation. |
| `src/adc/ads131.h` | 188 | Dormant but linked on ESP32-S3 | ADS131 sampler and external clock programming. A global instance exists but is never registered. |
| `src/adc/ads131/ADS131M02.h` | 270 | Unused legacy variant | Two-channel ADS131 register map and driver declaration. |
| `src/adc/ads131/ADS131M02.cpp` | 414 | Compiled on ESP32-S3, linker-GC candidate | Two-channel ADS131 implementation. |
| `src/adc/ads131/ADS131M04.h` | 270 | Unused legacy variant | Four-channel ADS131 register map and driver declaration. |
| `src/adc/ads131/ADS131M04.cpp` | 507 | Compiled on ESP32-S3, linker-GC candidate | Four-channel ADS131 implementation. |
| `src/adc/ads131/ADS131M0x.h` | 302 | Dormant but linked on ESP32-S3 | Combined ADS131M02/M04 register map and driver declaration. |
| `src/adc/ads131/ADS131M0x.cpp` | 721 | Dormant but linked on ESP32-S3 | Combined ADS131 implementation used by the unregistered global ADS131 sampler. |
| `src/adc/ina226.h` | 154 | Dormant but linked on ESP32-S3 | INA226 sampler. A global instance exists but is never registered. |

### Build configuration

| File | Lines | Responsibility and finding |
|---|---:|---|
| `platformio.ini` | 138 | Defines legacy ESP32, ESP32-S3, and STM32H5 environments. Filters are long, header-oriented, and contain stale entries such as absent `main.cpp`; the legacy ESP32 environment is broken. |
| `ble-bridge/platformio.ini` | 24 | Relay environment. It has no `lib_extra_dirs`/include path for the shared protocol and emits repeated core-macro redefinition warnings. |
| `boards/nucleo_h503rb.json` | 38 | Local STM32H503 board definition. |
| `parts.csv` | 17 | ESP32-S3 OTA/NVS/SPIFFS/coredump partition map; SPIFFS is intentionally reserve space and is not mounted. |

### Files over 200 lines

| File(s) | Why large | Recommendation |
|---|---|---|
| `src/ble.h` (695) | GATT server, reliable telemetry stream, OTA, aux, link tuning, and callbacks | Split by service/characteristic and transport concern. |
| `src/energy_counter.h` (377) | Integration, recovery, queues, windows, serialization, CRC, persistence, and printing | Split domain state from transport encoding and presentation. |
| `src/adc/ina228.h` (656), `ina228_mux.h` (393) | Duplicate register codec/device logic plus two scheduling strategies | Extract an INA228 device/codec, then keep direct and mux sampler policies small. |
| `src/main_esp32.cpp` (238) | Shared boot plus ESP-only OTA/Wi-Fi/UART/deep-sleep concerns | Introduce a common `FirmwareApp`; retain thin platform composition roots. |
| `src/util.cpp` (227) | Five unrelated utility families | Split clock, log, I2C diagnostics, Wi-Fi, and Influx modules. |
| `ble-bridge/src/main.cpp` (238) | Protocol, UART, BLE service, and Arduino entry points | Reuse shared protocol classes and extract a relay GATT object. |
| `src/adc/ads1262/ads1262.cpp` (207) | Legacy third-party-derived driver | Archive/delete if unsupported; otherwise place in its own library, not production `src`. |
| Six `src/adc/ads131/*` files (270–721) | Three overlapping driver variants with copied register maps/implementations | Keep one supported variant or archive the family; consolidation matters more than mechanically splitting it. |
| `src/atomicops.h` (777), `readerwriterqueue.h` (982) | Vendored library, including unused platform support/commented code | Do not refactor locally; move to `lib/` or a pinned dependency with license/version metadata. |

## 2. Abstraction opportunities

### High impact

| Rank | Opportunity | Evidence | Concrete direction |
|---:|---|---|---|
| 1 | Make the UART protocol a real shared module | The two 8-state parsers and frame writers are nearly line-for-line copies. The relay cannot include the current header, and the STM image uses a stub. | Create a small platform-free library containing `MessageType`, `Crc16Modbus`, `FrameWriter`, and incremental `FrameParser`. Give it callbacks/spans, explicit big-endian length encoding, and tests for resync, zero-length, oversize, CRC failure, and fragmented input. Reference it from both PlatformIO projects. |
| 2 | Introduce a common firmware composition root | Both mains instantiate the same INA228, mux channels, TMP117s, registry, telemetry, and task loops. Most differences are boot services and platform policies. | Add `FirmwareApp`/`AppContext` that owns the registry, sensors, transport, and telemetry and implements common setup/task bodies. Inject `Board`, `Transport`, `IdlePolicy`, and optional OTA hooks; leave each `main_*.cpp` as wiring. |
| 3 | Separate measurement domain state from wire/presentation code | `EnergyCounter` owns integration, calibration, queueing, stall recovery, windows, printing, `Point`, packed wire layout, and CRC. `summary()` currently forgets to put `Energy` into `ws.data.e`. | Split into `SampleProcessor`/`EnergyIntegrator`, `SamplerMonitor`, `SummaryWindow`, and a versioned `TelemetryEncoder`. Put Influx conversion in an ESP-only adapter. This also gives reset and summary semantics one owner each. |
| 4 | Extract an INA228 device abstraction on top of a portable I2C bus | Direct and mux drivers duplicate registers, reset/ID checks, shunt calibration, temperature/voltage conversion, diagnostics, and alert handling. `ina228_mux.h` explicitly duplicates constants to avoid ODR problems in `ina228.h`. | Build `I2cBus` plus `Ina228Device` (`probe`, `reset`, `configure`, `readStatus`, `readVbus`, `readTemp`, `setShunt`). Keep `ContinuousIna228Sampler` and `MuxedIna228Sampler` as scheduling policies. |
| 5 | Replace address arithmetic with a persistence schema | Pins, EEPROM access, validation, energy calibration, resistor/range data, and aux state share raw offsets. Comments already document slot collisions and reserved bytes. | Create `BoardPins` as `inline constexpr` data and a `SettingsStore`/`CalibrationStore` with typed keys, schema version/magic, bounds checking, and target-specific backend. One backend should own `EEPROM.begin/commit/end`. |

### Medium impact

| Rank | Opportunity | Evidence | Concrete direction |
|---:|---|---|---|
| 6 | Make aux switch state cohesive | File-level `static auxState` plus free persistence, GPIO, sleep-hold, and parser functions. Header-local state can produce a separate instance per translation unit. | `AuxSwitch` should own state and receive `DigitalOutput`, `ByteStore`, and `SleepHold` collaborators. Keep a platform-free `parseAuxCommand` beside the shared protocol so the relay and firmware use identical semantics. |
| 7 | Decompose the ESP BLE server | `BleSrv` handles GATT construction, acked telemetry buffering, session state, OTA, aux requests, security, connection parameters, and all callbacks. | Compose `SmartShuntGatt`, `IndicationQueue`, `OtaGattService`, and `AuxGattService`. The direct ESP firmware and relay can share the base GATT/UUID layer while retaining different telemetry sources. |
| 8 | Replace the “utility drawer” with focused services | `util.*` mixes clocks, logs, I2C scan, task notification, Wi-Fi, UDP Influx, and Point adapters. | Move to `clock`, `log`, `i2c_scanner`, `rtos_notification`, and ESP-only `wifi`/`influx` modules. Keep platform code out of domain headers. |
| 9 | Make console commands operate on interfaces | `console.h` includes both full INA228 headers and reaches `ina228_instance[]`/`ina228_mux_instance` globals. | Register commands against `CalibrationService`, `AuxSwitch`, and a typed device-control registry. This removes concrete drivers from the console parser. |
| 10 | Treat active sensor selection as configuration | ESP constructs three unused legacy samplers while only five current devices are registered; filters try to select code by exclusion. | Declare the supported sensor set once in the composition root or generated board config. Compile experimental drivers as separate libraries/environments. |

### Low impact

- Keep `Sample::p()` as a pure derived accessor if convenient, but move `setTimeNow()` out. A packed transport-facing value should not pull `gettimeofday`, ESP compatibility, and HAL headers into every sampler.
- Replace generic `UIP<T>` with a domain-named `MeasurementWindows`/`ChannelStats`; `UIP` is used only twice, both inside `EnergyCounter`.
- Move implementation-heavy headers (`console`, `telemetry`, `energy_counter`, INA drivers) into `.cpp` files. This reduces transitive includes, ODR risk, and rebuild time without changing runtime architecture.
- Rename `BleTransport` to `TelemetryTransport` if UART remains an implementation; the current name describes one backend rather than the interface.

## 3. Duplicated logic

### ESP32-S3 versus STM32 main

| Area | Shared/duplicated | Genuinely platform-specific | Recommended home |
|---|---|---|---|
| Sensor object graph | Same INA228 at `0x40`, same mux backend at `0x41`, same two mux channels, same two TMP117s | ESP prefixes published names with `ESP32_`; pin data differs through settings | `FirmwareApp` + `BoardConfig` |
| Startup sequence | Serial, aux restore, I2C, transport begin, ABI size assertions, add/init/start samplers, create telemetry, start two tasks | ESP boot watchdog, Wi-Fi/time sync, OTA setup; different `Wire.begin` overload | Common `FirmwareApp::start`, platform hooks around it |
| Registry population | Same five `add()` calls and mux `init()` | None apart from names | Static sensor descriptor table or common method |
| Real-time task | Infinite `samplers.updateAll()` loop | STM adds `vTaskDelay(1)`; ESP honors OTA `g_samplingHalted` and pins a core | Common loop with injected yield/quiesce policy |
| App task | Infinite `telemetry->update()` plus 10-tick delay | ESP runs OTA tick/liveness confirmation | Common loop with optional app hooks |
| Idle behavior | Same activity detection in `Telemetry` | ESP deep-sleeps and holds aux; STM only logs | Injected `IdlePolicy` |
| Task creation | Same two logical tasks/priorities | ESP core affinity and larger stacks; STM generic FreeRTOS tasks | `TaskSpawner`/platform adapter |
| Transport | Both satisfy `BleTransport` in type | ESP uses NimBLE; STM currently uses no-op stub, not the intended UART bridge | Platform composition root; fix STM selection first |

### BLE and UART transport

| Concern | `BleSrv` | `BleBridge` | Factor? |
|---|---|---|---|
| Telemetry delivery | Buffered NimBLE indications with acknowledgements/backpressure | Encodes one UART frame | Keep backend-specific behind `TelemetryTransport`. |
| Flush/tick | Retires indications, handles timeout, OTA, aux, link tuning | UART flush and byte parser | Backend-specific. |
| Connection state | NimBLE server/subscription state | Link-status frame from relay | Shared interface semantic, different implementation. |
| Aux state | Creates characteristic, parses requests, defers NVS write | Parses AUX_SET and publishes AUX_STATE frames | Share pure command/value types and parser; keep I/O separate. |
| GATT identifiers/setup | Defines service/telemetry/aux UUIDs and callbacks | Relay duplicates those identifiers and much of basic server setup | Extract `GattIds` and possibly a reusable `SmartShuntGatt` component. |
| OTA | Full OTA service and link tuning | None | ESP-direct only unless the relay protocol later tunnels OTA. |

### UART frame protocol duplication

`BleBridge::tick()` and `processUartRx()` in the relay have the same state enum, fields, byte transitions, oversize handling, CRC calculation, and resynchronization. `BleBridge::sendFrame()` and `sendFrameToSTM32()` likewise duplicate framing. Both use fixed 255-byte payloads and a big-endian length/CRC, while the unused `BleFrameHeader` exposes a native-endian `uint16_t` and should not be treated as an on-wire struct.

The shared API should look conceptually like:

- `FrameParser<MaxPayload>::push(byte)` returning either “need more”, a validated frame view, or an error;
- `encodeFrame(type, payload, outputSpan)` returning encoded length/error;
- one CRC implementation shared with `WireSample` if the protocol intentionally continues using the same Modbus polynomial;
- application callbacks mapping frames to aux/link/telemetry behavior.

This is the strongest duplication removal because it also fixes two independently evolving protocol implementations.

## 4. Dead code

### Safe to remove now (no call sites in this repository)

| Item | Evidence/notes |
|---|---|
| `PowerSampler_Dummy` in `tmp117.h` | No instantiation or reference outside its declaration. Put a dummy in tests if still useful. |
| `readBuf2()` and `PowerSampler_INA228::read_voltage_current()` | The helper unconditionally returns `false`; its remaining body is unreachable. The only caller is the otherwise-unused combined read method. |
| `PointDefaultConstructor` and `pointFromSample()` in `util.cpp` | No callers. |
| `influxWritePointsUDP()` / `influxWritePointUDP()` / their buffer helpers | No production caller. The plural function also mistakenly sends `p[0]` on every iteration. |
| `BleFrameHeader` and `ble_crc16()` | Neither is referenced. Keep only the incremental CRC used by an actual codec. |
| `platform::{restart,gpioHoldEn,gpioHoldDis,deepSleep,eepromGet,eepromPut,eepromRead,eepromWrite}` | No call sites; ESP code bypasses them with direct APIs and persistence code bypasses the EEPROM wrappers. Either adopt them through focused interfaces or delete them. |
| `esp_compat.h` EEPROM macros, OTA placeholder structs, and `ESP_restart` macro | No call sites. |
| `EnergyCounter::maxDtReported`, `startTime`, and `numTimeouts` | Written but only read in commented-out code. `TotalCharge`/`LastI` are computed but never published or queried; remove them unless charge is about to become a first-class output. |
| `EnergyCounter::summary(dt_us, ..., outNewSamples)` extra plumbing | `dt_us` is unused. The caller invokes `summary` only after `newSamplesSinceLastSummary`, so the output flag is redundant. |
| Duplicate `getTimeStamp` declaration and commented implementation in `sampling.h` | One declaration in a clock header is sufficient. |
| `adc_ads.h::chooseGain`, legacy ADC `readADC_Cal` helpers, unused pin constants and buffer counters | No live call sites; several have only commented references. |
| `sui.h` | Empty, unreferenced, and explicitly filtered from STM32. |

### Remove from active builds immediately

`main_esp32.cpp` constructs `PowerSampler_ADS ads`, `PowerSampler_ADS131 ads131`, and `PowerSampler_INA226 ina226`, but never adds them to `SamplerRegistry`. This is not cost-free dead code: the final ESP32-S3 ELF contains all three objects/vtables and substantial ADS131/ADS/INA226 methods. The objects reserve 120, 148, and 92 bytes respectively, plus a 4-byte instance pointer for each, and the linked methods include multi-hundred-byte initialization paths.

Remove those globals and their includes from the production composition root. Then remove the unused Adafruit ADS1X15, INA226_WE, and ADS1220 dependencies from the active ESP32-S3 environment if nothing else needs them.

The following driver families have no registered sampler in either current image:

- `adc_esp.h`, `adc_esp_dma.h`;
- `adc_ads.h`;
- `ads1220.h`;
- `ads1262.h` and `ads1262/`;
- `ads131.h` and all three `ads131/ADS131M*` variants;
- `ina226.h`.

Deleting them is safe for the two currently registered hardware sets, but this is a product-support decision: if they are retained as bench references, move them to `experimental/` or separate PlatformIO library/environments so they do not compile/link in production. Git history is a better archive than commented production code.

### Dormant feature branches to decide explicitly

- `USE_ARDUINO_BLE` is never defined. Its old BLE branch is dead and already causes LDF trouble documented in `platformio.ini`; remove it.
- `WITH_LCD` is never defined in any environment. Even when defined, the global `LCD` is not initialized or updated. Delete the file/dependencies or create a tested LCD environment.
- The ESP8266 branch in `util.cpp` has no PlatformIO environment.
- `XIAO_ESP32S3` is hard-coded true while WaveShare/green-board branches are false; `FMETAL` is not configured. Move real board variants to build configuration or delete them.
- `APPLY_U_GAIN_CAL` is hard-coded zero, making its application branch dead. Replace the macro with one deliberate behavior or a real build option.
- Wi-Fi/Influx is runtime-disabled by globals initialized to `true`, and no current path changes `disableWifi` to false. It still adds dependencies and a global client. Decide whether it is supported; do not leave it as source-edit configuration.
- UART message IDs `CALIB_SET`, `RESET_CMD`, `RESISTOR_RANGE`, `BOOTINFO`, and `CONSOLE_LOG` are declared but have no sender/handler. Mark them reserved with protocol documentation or remove them until implemented.

`ble_bridge.h` is also unreachable, but it is not a removal candidate: it represents required STM32 functionality. The right action is to instantiate it and make the relay build, not to classify it as harmless dead code.

### Commented-out blocks to delete during cleanup

- The alternate timestamp implementation in `sampling.h`.
- The old `setVal` implementation and advertising experiments in `ble.h`; remove the entire alternate BLE branch as above.
- Disabled fields/Influx metrics and serial-print block in `energy_counter.h`.
- `readBuf2`'s unreachable body and the large unreachable old combined-read implementation in `ina228.h`; remove scattered commented individual reads and bus-power comparison too.
- Driver experiments throughout `adc_ads.h`, `ads1220.h`, `ads1262.h/.cpp`, `ads131.h`, `ADS131M02.*`, and `ADS131M04.*`. If the drivers remain supported, preserve rationale in documentation/tests rather than commented executable code.
- Commented boards, ports, obsolete platform packages, and upload fragments in `platformio.ini` once supported environments are settled.
- The commented `BlockingReaderWriterQueue` inside the vendored queue. Prefer updating/re-vendoring an unmodified upstream copy rather than editing it piecemeal.

### Build/configuration cruft

- The legacy `esp32` environment does not build for several independent reasons and selects both mains. Remove it or restore it as a tested target with an explicit source filter and dependencies.
- The relay has no route to the shared header. Add a shared library path, not a relative include copied between projects.
- `build_src_filter` excludes many headers, but filters should primarily select translation units/directories. It also excludes absent `main.cpp` and generated/example secrets files. A directory layout per target makes filters short and auditable.
- A plain `pio run -e esp32s3` attempted upload because of project target configuration; use build-only defaults for repeatable CI and explicit upload commands for hardware workflows.

## 5. Include hygiene

### Unnecessary or leaking includes

| File | Problem | Recommendation |
|---|---|---|
| `settings.h` | Includes `EEPROM.h` even for pin consumers and mixes target storage implementation into every include. It also relies on indirect math/assert declarations on ESP. | Split `board_pins.h`, `calibration.h`, and a `.cpp` persistence backend; include `<cmath>`/`<cassert>` where actually used. |
| `adc/sampling.h` | Includes `esp_compat.h` on STM, which brings Arduino, FreeRTOS, and `stm32h5xx_hal.h`, solely to timestamp a sample. | Use standard integer types in the interface and obtain time from an injected/platform clock in `.cpp`. |
| `i2c.h` | Exposes `esp_err_t` to both targets and includes ESP compatibility/RTOS details. The `port` argument is ignored. | Return a portable `I2cResult`/`bool`, own `TwoWire&` in `I2cBus`, and hide mutex implementation in `.cpp`. |
| `aux_switch.h` | Pulls Arduino, EEPROM, ESP GPIO/logging, parsing, and persistence into all consumers. | Split pure parser, `AuxSwitch` interface, persistence backend, and platform GPIO/hold implementation. |
| `util.h` | Pulls FreeRTOS and ESP-only `Point.h` into every utility consumer because it also defines `TaskNotification`. | Give notification and Influx their own headers; forward-declare where possible. |
| `energy_counter.h` | Includes Arduino, settings/EEPROM, util/FreeRTOS/Point, and the full queue implementation in a public domain header. | Move implementation to `.cpp`; depend on narrow sampler, store, clock, queue, and logger interfaces. |
| `ina228.h` | On ESP includes `SPI.h` and `INA226_WE.h` although neither is used. It also uses direct `Wire` alongside `i2c.h`. | Remove both unused includes and route all register access through `I2cBus`. |
| `ina226.h` | Includes unused `SPI.h` and all of `ina228.h` merely for register constants/I2C helpers, thereby importing globals and definitions. | Include a small INA register/constants/device header. |
| `ina228_mux.h` | Includes `settings.h` and `util.h` mainly for persistence/notification; duplicates INA constants to avoid including `ina228.h`. | The proposed device, store, and notification interfaces remove this workaround. |
| `tmp117.h/.cpp` | Header includes all Arduino for basic declarations; `.cpp` includes `esp32-hal.h` even though no ESP-only symbol requires it. | Use `<cstdint>`/sampler interface in the header and a platform logger/clock in `.cpp`. |
| `platform.h` / `esp_compat.h` | Public headers expose EEPROM, ESP logging/timer/GPIO or STM32 HAL/FreeRTOS. Most wrappers are unused. | Define narrow platform interfaces; put ESP/STM includes and implementations in target `.cpp` files. |
| `ble.h` | Includes a dead ESP BLE stack branch, direct ESP APIs, OTA, aux persistence, and all callbacks in one header. | Keep NimBLE/OTA in ESP-only `.cpp` files and expose only the transport class declaration. |
| `ble_protocol.h` | Includes `string.h` only to obtain transitive basic declarations; defines an unused native-layout header. | Use `<cstdint>`, `<cstddef>`, spans/views, and explicit encoding functions. |
| `main_esp32.cpp` | Unused `<map>`, `USB.h`, and numerous unused legacy ADC headers; dormant Influx/Wi-Fi objects retain dependencies. | Include only selected devices/services. |
| `main_stm32.cpp` | Includes console, settings, I2C, aux, util, and energy headers already reached through higher-level headers; more importantly omits `ble_bridge.h`. | Let a composition-root header expose only construction types and instantiate the real bridge. |
| `sampler_registry.h` | Includes `util.h` for scan/log side effects and exposes public vectors. | Move implementation to `.cpp` and inject diagnostics/logger. |
| `lcd.h` | Relies on transitive declarations of `Wire` and `Sample`; it is not self-contained. | If retained, include its direct dependencies and compile only in an LCD library/target. |
| `atomicops.h`, `readerwriterqueue.h` | Duplicate `<cerrno>`/`<new>` includes and carry broad upstream platform support. | Keep an unmodified, versioned upstream dependency rather than locally grooming it. |

### Missing guards and self-containment

These headers have neither `#pragma once` nor a conventional include guard:

- `adc/adc_ads.h`
- `adc/adc_esp.h`
- `adc/adc_esp_dma.h`
- `adc/ads1220.h`
- `adc/ads1262.h`
- `adc/ads131.h`
- `adc/ina226.h`
- generated `secrets.h`

This is especially risky because several define non-inline globals and free functions (`*_instance`, ISR functions) in the header. `ina228.h`, `ina228_mux.h`, and `ble_bridge.h` do have guards but still define external-linkage globals/functions in headers; including them from another translation unit would cause multiple definitions. Use `.cpp` definitions or C++17 `inline` variables only where a global is truly appropriate.

Several legacy headers also fail standalone compilation by relying on include order: `adc_esp*.h` do not include `sampling.h`; `ads1220.h`, `ads1262.h`, and `ads131.h` use `settings` without including its declaration; `lcd.h` uses `Wire` and `Sample` indirectly.

### Inclusion graph risks

No literal include cycle was found, but there are strong transitive-coupling chains that behave like one during maintenance:

- `energy_counter.h -> settings.h -> EEPROM.h` makes the core integrator depend on persistence and Arduino.
- `sampling.h -> esp_compat.h -> stm32h5xx_hal.h` makes the sampler interface depend on a concrete MCU HAL.
- `ina226.h -> ina228.h` imports a different complete driver, global ISR registry, settings, I2C, and utility layer for a few constants/helpers.
- `console.h -> sampler_registry.h -> energy_counter.h` and `console.h -> ina228*.h` make a parser rebuild/import nearly the whole firmware.
- `util.h -> Point.h` makes even task notifications and logging depend on the ESP Influx library.

The current `static settings_t settings` and `static bool auxState` in headers create translation-unit-local state. That avoids linker errors but does not create one coherent application object; mutations can be observed through a different copy depending on which inline function is emitted. Explicit instances passed by reference are safer and clearer.

## 6. Class design recommendations

| Type/decision | Recommendation | Rationale |
|---|---|---|
| `PowerSampler` lifecycle | Separate `start()` (initial activation) from `recover()` (stall action). Add `stop()`/`shutdown()` only when OTA, reconfiguration, or low-power code has a real caller; a default no-op is sufficient initially. | `startReading()` currently means “begin next conversion” for ADS, “re-arm configuration” for INA228, reset mux state, and no-op for TMP117. A symmetric pure virtual now would add boilerplate without defined semantics. |
| `PowerSampler` base | Add a virtual destructor if objects may ever be owned/deleted polymorphically; otherwise document non-owning/static lifetime and use references. Add `override` consistently. | The base is polymorphic but has no virtual destructor. Current global lifetime happens to avoid deletion. |
| `EnergyCounter::sampler` | Use `PowerSampler&` or `std::reference_wrapper<PowerSampler>`, not an owning smart pointer and not a nullable raw pointer. | Samplers have static/application lifetime, and two mux channel samplers share one backend. Ownership belongs in `FirmwareApp`/registry; the counter only borrows. |
| Counter name | Use `std::string_view` for static names, or a fixed validated device-name type used directly by the encoder. | Every current name is a string literal. Dynamic `std::string` allocation/copy is unnecessary; a fixed type also handles the 16-byte wire field and termination/truncation deliberately. |
| `EnergyCounter` state | Define and test invariants for reset, summary, and recovery. | `reset()` currently leaves charge/`LastI`, stall timers/streak/backoff, queued samples, last diagnostic, print counters, and wire index partly intact. It is unclear whether “reset” means energy only or full session reset. |
| Wire summary | Encode explicitly and set every semantic field, especially `data.e`. Do not serialize a packed native C++ object as the protocol definition. | Current summary captures `Energy` for printing but omits it from `WireSample`; native floats/endian/layout and an unaligned packed `uint64_t` bind the protocol to compiler/MCU ABI. `Sample::diag` and `WireSample::diag` are also redundant on wire. |
| `SamplerRegistry` | Do not make it a singleton. Make it an owned member of `FirmwareApp`, keep vectors private, and expose iteration/find/control methods. | Passing a reference is explicit and testable. A singleton would increase hidden coupling; the current global instance already supplies the required lifetime without making global access desirable. |
| Registry construction | Let registry/app own sampler objects or receive a static descriptor span, then construct counters once after successful initialization. | The separate public `entries` and `counters` vectors duplicate associations and allow invalid mutation. |
| `Telemetry::onIdleSleep` | Inject an `IdlePolicy&` or a small function pointer/context pair. Avoid `std::function` if heap/code size matters. | There is one platform variation, so inheritance and a vtable are more machinery than needed. A policy also makes STM “log only” and ESP deep sleep explicit. If inheritance stays, add a virtual destructor. |
| `Telemetry` ownership | Construct telemetry as an application member/static object, not `new` a never-deleted pointer after setup. | Lifetime is deterministic and dependencies already exist before tasks start. |
| `Sample` | Keep it a plain measurement value with pure helpers such as `power()`. Move clock acquisition to samplers/a `SampleFactory`. Consider separate `MeasurementSample` and `WireSampleV1` types. | Domain measurement, acquisition time source, and protocol packing are separate concerns. |
| `I2cBus` | Own `TwoWire&` and one mutex; expose `probe`, `write`, `read`, `readU16BE`, and a portable result. A nested RAII transaction can hold the lock across a repeated-start sequence. | This removes the ignored port parameter, ESP error leak, duplicated direct-Wire helpers, and ambiguity about lock ownership. |
| `AuxSwitch` | Own state and coordinate GPIO/persistence/hold through injected adapters; keep parsing pure. | Bundles the exact data and methods currently scattered around one header-local boolean. |
| `TaskNotification` | Rename to a domain-neutral RTOS primitive or `DataReadySignal` and isolate its platform implementation. | It is synchronization, not a general utility, and currently forces FreeRTOS into unrelated headers. |
| `BleTransport` | Keep backend polymorphism, but consider `TelemetryTransport`; add typed aux/link methods only if they truly belong to every backend. | Direct BLE and UART framing share an interface contract, not implementation. Factoring them into one class would blur responsibilities. |
| BLE UART parser | Prefer one reusable stateful class over free/static file state. | The relay parser currently uses many file-level globals; the STM parser embeds the same state in `BleBridge`. One tested class serves both. |

`UIP<T>` is not a generally reused abstraction: it appears only as `UIP<MeanWindow>` for `winPoint` and `winPrint`. Replace it with a named `MeasurementWindows` struct containing `voltage`, `current`, `power`, and `temperature`; that communicates the invariant and avoids template indirection with no reuse.

## 7. Suggested file reorganization

One reasonable end state is:

```text
lib/
  shunt-protocol/
    include/shunt_protocol/
      aux_command.h
      crc16.h
      frame.h
      frame_parser.h
      gatt_ids.h
      telemetry_v1.h
    src/
      frame.cpp
      frame_parser.cpp
  readerwriterqueue/             # pinned, unmodified upstream + license/version

src/
  app/
    firmware_app.h
    firmware_app.cpp
    app_context.h
  config/
    board_pins.h
    settings_store.h
    calibration_store.h
  domain/
    measurement_sample.h
    energy_integrator.h
    energy_integrator.cpp
    measurement_windows.h
    telemetry_summary.h
  sampling/
    power_sampler.h
    sampler_monitor.h
    sampler_registry.h
    sampler_registry.cpp
  drivers/
    i2c/
      i2c_bus.h
      i2c_bus.cpp
    ina228/
      ina228_device.h
      ina228_device.cpp
      continuous_sampler.h
      muxed_sampler.h
    tmp117/
      tmp117_sampler.h
      tmp117_sampler.cpp
    aux/
      aux_switch.h
      aux_switch.cpp
  services/
    console.h
    console.cpp
    telemetry.h
    telemetry.cpp
    log.h
    clock.h
  transport/
    telemetry_transport.h
    esp32_nimble/
      nimble_transport.h
      nimble_transport.cpp
      indication_queue.h
      ota_gatt_service.h
    stm32_uart/
      uart_bridge_transport.h
      uart_bridge_transport.cpp
  platform/
    esp32/
      board.cpp
      clock.cpp
      settings_backend.cpp
      wifi.cpp
      influx.cpp
    stm32h5/
      board.cpp
      clock.cpp
      settings_backend.cpp
  main_esp32.cpp
  main_stm32.cpp

ble-bridge/
  src/
    main.cpp
    relay_app.h
    relay_app.cpp
    relay_gatt.h
    relay_gatt.cpp

experimental/                    # only if legacy hardware must remain buildable
  ads1115/
  ads1220/
  ads1262/
  ads131/
  esp_adc/
  ina226/
  lcd/
```

Both root firmware and `ble-bridge` should consume `lib/shunt-protocol` through an explicit shared library path (or be environments in one PlatformIO project). Target directories make `build_src_filter` small: common sources plus one platform directory and one main, instead of a growing blacklist of headers and abandoned drivers.

Recommended implementation order:

1. Fix the functional architecture: make the relay build, share/test the frame codec/parser, and instantiate `BleBridge` in the STM32 composition root.
2. Remove unregistered legacy globals/includes and either delete or isolate legacy drivers; make all declared environments build-only by default and CI-tested.
3. Introduce `FirmwareApp` to remove duplicated setup/task code without touching driver behavior.
4. Extract `I2cBus`/`Ina228Device`, typed persistence, and `AuxSwitch`; these eliminate the most damaging platform/global coupling.
5. Split `EnergyCounter` and `BleSrv`, with explicit telemetry serialization and tests for energy, reset, queue, CRC, and reconnect behavior.

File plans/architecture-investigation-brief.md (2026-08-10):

# Architecture Investigation Brief

## Objective

Investigate the smart-shunt-fw codebase (worktree: `/Users/fab/dev/pv/smart-shunt-fw-stm32h5`, branch `port/stm32h5`) for opportunities to improve readability, reduce file sizes, and bundle semantically connected data and methods into cohesive classes. This is an organically grown project — expect accumulated cruft, duplicated logic, and missed abstraction boundaries.

## Context

The firmware measures DC power/energy via TI INA228 I2C ADCs, integrates it over time, and publishes it over BLE (ESP32) or UART-to-BLE-bridge (STM32H5). It was originally written for ESP8266, ported to ESP32, then ESP32-S3, and now STM32H5. A recent refactor introduced `platform.h`, `ble_transport.h`, `sampler_registry.h`, `console.h`, and `telemetry.h` abstractions, and split `main.cpp` into `main_esp32.cpp` + `main_stm32.cpp`.

## Scope

Investigate ALL source files under `src/`, `ble-bridge/src/`, and the build configs. Do NOT make changes — produce findings only.

## What to look for

### 1. Abstraction candidates — data/methods that belong together but are scattered

- **`settings.h`**: Pin mappings, EEPROM calibration storage, and `checkCalibrationFactorBounds` are all in one file but serve three different concerns. Should pin config, calibration storage, and validation be separate types?
- **`i2c.h`**: The `I2cLock` class and the free functions `i2c_write_buf`, `i2c_read_buf`, etc. — could these be a class with the lock as a member? The `esp_err_t` return type is an ESP-IDF concept that leaks into MCU-independent code.
- **`aux_switch.h`**: State, persistence, drive, parse, and deep-sleep hold are all free functions sharing a file-level `static bool auxState`. Should this be a class?
- **`util.h` / `util.cpp`**: Contains `timeStr()`, `scan_i2c()`, `UART_LOG()`, `getTimeStamp()`, WiFi/InfluxDB functions, and the `TaskNotification` class — five unrelated concerns in one file. What should be split out?
- **`energy_counter.h`**: The `WireSample` struct (with `getInfluxDbPoint()` and `compute_crc16`) and the `EnergyCounter` class are coupled. Should `WireSample` be its own type? The `UIP<T>` template — is it used anywhere else?
- **`sampling.h`**: `Sample` struct, `PowerSampler` ABC, `getTimeStamp()` declaration, and the dead `getTimeStamp` implementation comment. Should `Sample` have methods (e.g. `p()`, `setTimeNow()`) moved out of the struct into a class?

### 2. File size — files that are too large or do too much

- List every `.h`/`.cpp` file with its line count
- Identify files > 200 lines that could be split
- Identify headers that define multiple unrelated classes/structs

### 3. Duplicated logic across the two targets

- Compare `main_esp32.cpp` and `main_stm32.cpp` — what's genuinely platform-specific vs what was duplicated because it was easier?
- Compare `ble.h` (ESP32 NimBLE) and `ble_bridge.h` (STM32 UART) — both implement `BleTransport`, but do they share any logic that could be factored out?
- The `ble-bridge/src/main.cpp` (ESP32 relay) reimplements the UART frame parser from `ble_bridge.h` — should `ble_protocol.h` provide a shared `FrameParser` class?

### 4. Dead code and accumulated cruft

- Commented-out code blocks (there are many — `readBuf2`, old ADS131 pin configs, `PointDefaultConstructor`, etc.)
- `#ifdef` guards that are always-true or always-false on current targets
- Unused includes (e.g. `#include <SPI.h>` in `ina228.h` on ESP32)
- Files excluded by `build_src_filter` but still present (`adc_esp.h`, `adc_esp_dma.h`, `ads1220.h`, etc.) — are they kept for reference or safe to remove?
- The `PowerSampler_Dummy` class — is it used?
- The `sui.h` empty stub
- The `lcd.h` / `WITH_LCD` code path

### 5. Header inclusion hygiene

- Which headers include `<Arduino.h>` when they only need specific types?
- Which headers pull in platform-specific includes (`esp_log.h`, `driver/gpio.h`, `stm32h5xx_hal.h`) that should be behind `platform.h` instead?
- Circular include risks — `energy_counter.h` includes `settings.h` includes `EEPROM.h`; `sampling.h` includes `esp_compat.h` on STM32 but `sys/time.h` on ESP32
- Missing `#pragma once` guards (the `energy_counter.h` bug that was just fixed — are there others?)

### 6. Class design opportunities

- Should `PowerSampler` have a `stopReading()` or `deinit()` method? The `startReading()` is used for stall recovery but there's no symmetric cleanup.
- Should `EnergyCounter` own its `PowerSampler*` instead of holding a raw pointer? Should it be constructed with the sampler name as `std::string_view` instead of copying a `std::string`?
- Should `SamplerRegistry` be a stack-allocated singleton rather than passed by reference everywhere?
- `Telemetry` has a `virtual onIdleSleep()` overridden by `EspTelemetry` — is there a cleaner way to express this (strategy pattern, function pointer, callback)?

## Output format

Produce a markdown report with these sections:

1. **File inventory** — table of every source file, line count, and what it does
2. **Abstraction opportunities** — ranked by impact (high/medium/low)
3. **Duplicated logic** — table comparing the two targets, what's shared vs duplicated
4. **Dead code** — list of files, functions, and code blocks safe to remove
5. **Include hygiene** — list of files with unnecessary or platform-leaking includes
6. **Class design recommendations** — concrete proposals with rationale
7. **Suggested file reorganization** — proposed directory structure if things were cleaned up

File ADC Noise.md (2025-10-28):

```
ENOB = ln (Full-Scale Range / VRMS-Noise) / ln(2) 
Noise-Free Bits = ln (Full-Scale Range / VPP-Noise) / ln(2) 
Full-Scale Range = 2 · Vref / Gain
```

## INA228




## ADS1220

µV, normal, PGA
bits, turbo, PGA
bits, turbo, no PGA





* use AVDD = 5V
* use external 2.5V reference
* stabilize temperature with peltier?

## ADS131M
[pdf](https://www.ti.com/lit/ds/symlink/ads131m02.pdf)



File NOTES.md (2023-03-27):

* TODO:
- linearity test
- 160 mhz
- handle integer flip over
- auto-gain
- AC RMS
- Min-Max
- Peak-to-Peak
- Auto-correlation, max Frequency, DC+AC
- Linear Calibration (atomated)
- trapezoidal integration

- Telemetry https://github.com/Overdrivr/Telemetry
- MQTT ?

- do i need to pull one current sense input to V_DD/2 ?
If VOUT is connected to the ADC positive input (AINP) and VCM is connected to the ADC negative input (AINN),
VCM appears as a common-mode voltage to the ADC. This configuration allows pseudo-differential
measurements and uses the maximum dynamic range of the ADC if VCM is set at midsupply (VDD / 2). A resistor
divider from VDD to GND followed by a buffer amplifier can be used to generate VCM.

- Therefore, use a first-order RC filter with a cutoff frequency set at the output data rate or
10x higher as a generally good starting point for a system design. . Limit the filter resistor values to below 1 kΩ.
  fC = 1 / [2π · (R5 + R6) · CDIFF] 
Two common-mode filter capacitors (CCM1 and CCM2) are also added to offer attenuation of high-frequency,
common-mode noise components. Select a differential capacitor, CDIFF, that is at least an order of magnitude
(10x) larger than these common-mode capacitors because mismatches in these common-mode capacitors can
convert common-mode noise into differential noise. The best ceramic chip capacitors are C0G
(NPO), which have stable properties and low-noise characteristics.
- Analog inputs with differential connections must have a capacitor placed differentially across the inputs. Best
input combinations for differential measurements use adjacent analog input lines such as AIN0, AIN1 and
AIN2, AIN3. The differential capacitors must be of high quality. The best ceramic chip capacitors are C0G
(NPO), which have stable properties and low-noise characteristics.

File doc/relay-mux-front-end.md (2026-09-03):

# The relay-mux ratio front end: what it measures, and two defects that cost 141 µV

Bench campaign of 2026-09-02/03 on the **nest** — a XIAO ESP32-S3 driving the
three-board riser from `pwr-metering`: Coto relay mux → 51:1 divider → shunt-adc
(ADS1262), env `xiao_nest`.

Everything below is measured on that rig, through BLE into InfluxDB. The board's
USB-CDC is dead in both directions, so *no* number here came from the console.

## The headline

One 1.2 V source into the mux's left input, right input open, published as raw ADC
volts (`dividerRatio` deliberately unset).

| build | VMUX_A spread | VMUX_A sd | VMUX_B mean (should be 0) |
|---|---|---|---|
| G=1, PGA bypassed, temp read on | **141 µV** | — | **+3327 µV** |
| …averaging 2 conversions | 65 µV | — | |
| …averaging 4 conversions | 34.4 µV | 7.1 µV | |
| …averaging 4, temp read **off** | 3.9 µV | 0.9 µV | |
| **G=1, PGA enabled, temp read back on** | **4.5 µV** | **0.9 µV** | **−13.9 µV** |

207 consecutive samples in the last row landed in a single 5 µV bin.

## Defect 1 — the die-temperature read injects a settling transient

`ads1262.h`'s `TEMP_EVERY_N_SCANS = 64` drops chop, retunes gain and INPMUX, then
restores production config and toggles `START`. The comment there already said it:
*"every one of those restarts is a fresh settling transient in the middle of a
precision measurement."* Nobody had measured what it cost.

64 × 52.22 ms = **3.34 s**. Against the ~836 ms round trip in force when this was
measured, that is **one dwell in four** — the period-4 pattern that started this.
It is a fact about that measurement, not a standing property: at the ~1.15 s round
trip that 4-conversion averaging produces, the ratio is ~2.9. Affected samples also
arrived ~60 ms late, the restart's own latency.

**How it was proved.** `ADS1262_TEMP_EVERY_N_SCANS=0` disables the read outright.
The artefact vanished (141 µV → 3.9 µV), rather than merely becoming rarer. That is
causal, not correlational.

**A wrong turn worth recording.** The first fix averaged consecutive conversions,
justified as "averaging N conversions cancels any disturbance whose period divides
N". That predicted ~0 µV at N=4. The bench returned 34.4 µV, and the residual
halved with each doubling of N — 1/N dilution of *one* bad conversion, not
cancellation of a periodic term. The reasoning was wrong even though the numbers
improved, which is the trap: a change that helps is not thereby explained.

**Does `SHUNT_ADC` have it too?** Unverified, and probably not in the same form.
It runs the same driver and gets the same restart, but at **G=32 with the PGA
already enabled** — so the bias-current-through-source-impedance mechanism that
made this so large does not apply to it, and its source is Kelvin-sensed at near
zero ohms besides. Only the relay-mux path was measured. Worth checking, not worth
asserting.

## Defect 2 — PGA bypass cost 3.3 mV of offset

The relay-mux pair inherited **G=1 with the PGA bypassed** from the DCCT burden
channel. The stated reason: at G=1 the PGA's output swing leaves each input pin
roughly −2.2…+2.2 V on ±2.5 V rails, which a ground-referenced divider output could
exceed.

That worst case is not this source. Ground-referenced means AINN sits at AGND, so
V_cm = V_diff/2 and the pins land at **V_diff and 0**, not ±V_diff:

| input | divider out | PGA pins | margin to ±2.2 V |
|---|---|---|---|
| 80 V (qualified) | 1.569 V | 1.569 / 0 V | 0.586 V |
| 100 V (engineering) | 1.961 V | 1.961 / 0 V | 0.194 V |

Those margins are the **tolerated** ones. AVDD comes from an ADP7118 specified
±1.8%, so worst-case AVDD is 2.455 V and the limit is 2.155 V rather than the
nominal 2.2 V — putting the guaranteed clip point at **~109.9 V**, not ~112 V. The
board's 100 V engineering limit still sits inside it.

**That margin is the divider's, not the ADC's** — re-range the divider and this
must be re-derived.

What bypass cost was input current. Both channels carried the *same* additive
offset: A read 22.79 mV where 51:1 predicts 19.61 mV, and B (open) read 3.33 mV
where 0 is predicted. ~3.3 mV across the divider's 1 MΩ ∥ 20 kΩ = **19.6 kΩ**
implies **~165 nA** of input bias current — 17% of a 1 V reading, and the reason
`A − B` was needed to recover 1 V instead of reading A directly.

Enabling the PGA collapsed it to **−13.9 µV**, a factor of 230, and A became
directly usable: 23.431 mV against 23.529 mV nominal for 1.2 V ÷ 51, i.e. an
implied ratio of 51.21.

**It also removed defect 1's mechanism.** With the input buffered, bias current is
picoamps and the 19.6 kΩ source impedance stops converting configuration changes
into offset. The temperature read still restarts the converter — it just no longer
has a lever. Hence the last table row: temp read on, artefact absent.

The 165 nA is **inferred from the offset, not read from SBAS661C**. It has not been
checked against the bypass-mode input-current spec.

## Defect 3 — the step guard silenced a healthy channel on every input change

Raising the source 1.0 → 1.2 V made VMUX_A publish NaN forever. Raising it again,
1.2 → 1.5 V, did it a second time. Both times the channel was working perfectly.

The mechanism: the new reading matched neither `lastAccepted[A]` (the stale old
value) nor B, so the "matches neither channel" branch fired — and `take()` refreshes
`lastAccepted[]` only from *finite* samples, so the first NaN froze the baseline the
test compares against and every later sample failed identically.

**Two fixes were tried and both were wrong.**

*Withholding on the mismatch* assumes the input is static between visits. That is
false by construction for an instrument whose job is to track a changing voltage —
which is why it fired on both deliberate source changes and on nothing else.

*Adopting after N agreeing readings* rests on "a real source repeats, an open
contact floats". Also false: with the mux open the tap is tied to the Kelvin return
through the 20 kΩ low leg, so an open contact reads a **perfectly stable** value.
The agreeing readings adopt it and publish it forever — permanent silence traded for
a permanent plausible wrong number, the worse failure.

**The shipped behaviour publishes the value and flags the doubt.** One channel's
readings cannot separate "the input moved" from "the contact opened"; the
information is not there, and neither NaN nor adoption can manufacture it. So the
number goes out — it exists, and it is far more often a changed input than a failed
relay — carrying `DIAG_RELAY_UNMATCHED` in the diagnostic field, where a consumer
can see it, query it, and decide. The console reports a running count.

That does not leave the open-contact fault unguarded. An open contact reads the
network termination, and whenever the other channel is not sitting on that same
termination, `expectMove && !moved` fires on it and still publishes NaN. On this rig
that is measured, not assumed: B's input is open and reads −14 µV, exactly where an
open A would land. What is genuinely lost is the case where both the fault *and* the
other channel sit near the termination — and that case was never separable here.

`moveEpsV` came down 1 mV → **100 µV** at the same time. With the PGA enabled the
noise floor is ~1 µV sd, so 1 mV was ~1000 σ: it disarmed the guard across a band far
wider than any real ambiguity. 100 µV is still ~100 σ.

Verified after the fix, source at 1.5 V: **29190.1 µV, spread 4.4 µV, sd 1.14 µV**,
no diagnostics set. The `DIAG_RELAY_UNMATCHED` path itself has not yet been observed
on hardware — it only fires at the moment of a change, and the next source step will
exercise it.

## The settle campaign: 250 ms buys two time constants of something unidentified

Measured 2026-09-03 on the nest with A on the 26.225 V bench bus (raw 0.5147 V,
implied divider ratio 50.95) and B open. `env:xiao_nest_sweep` steps settleMs and
publishes the value in force as `P`.

**The method had to be fixed once before it measured anything.** The first sweep
walked the settle list repeatedly, on the stated grounds that repetition averaged
thermal drift out. It does not: the walk is always in the same order, so a monotonic
drift maps onto the settle axis identically on every pass, and repeating it averages
the noise while preserving the correlation exactly. Split in half, that run carried
~8 uV more apparent bias in its second half at EVERY settle value including ones
certainly long enough -- a clock, not a relay. The reported "sharp break at 50 ms"
was drift.

The fix is to alternate ref, test, ref and compare each test block against the mean
of the two references either side, which cancels drift to first order, with the
reference value left in the test list as a NULL CONTROL. That control is what makes
the rest of the table readable: it comes out at **+0.17 +- 0.62 uV**, i.e. zero.

| sample instant | A bias | B bias |
|---|---|---|
| 366 ms (null control) | **+0.17 +- 0.62 uV** | -1.30 +- 0.50 |
| 313 ms | -1.48 +- 0.61 | +1.65 +- 0.39 |
| 261 ms | -3.60 +- 0.25 | +4.25 +- 3.56 |
| 209 ms | -6.35 +- 0.44 | +5.42 +- 0.52 |
| 157 ms | **-13.07 +- 0.32** | +5.82 +- 0.32 |

A is an exponential in the time from ARM with **tau ~ 75 ms**. B is opposite in sign,
2.25x smaller, and flattens rather than continuing to grow.

**The settle axis is quantised, and nine values are five experiments.** The sample
instant is `ceil(S / 52.22) * 52.22 + 104.44`, so S=150 and S=120 return *identical*
biases -- they are the same experiment run twice. The measured dwells confirm it:
50/35/20 ms all give 365.5 ms, 90/70 give 418, 150/120 give 470.

## 157 ms is a hardware floor, and DISCARD_SCANS = 2 is exactly right

It is tempting to read the quantisation as an invitation to cut the discards. It is
not, and doing so would return a *better* number for the worst reason.

The ARM path is an RC delay-on (1 MOhm x 100 nF into an HCT14) whose slow corner puts
contact close at **65 ms**. The first conversion boundary strictly after that is
2 x 52.22 = 104.4 ms, and that conversion runs to **156.7 ms**. So the earliest
entirely-post-close conversion ends at 157 ms, which is exactly where DISCARD_SCANS=2
puts it. At DISCARD_SCANS=1 the used conversion would span 52->104 ms, straddling
contact close: contaminated, and biased in the direction that looks like success.

Predicted minimum dwell 50 + 157 + 3 x 52.2 = 364 ms against 365.5 measured.

Going below 157 ms needs the ARM RC shortened or a faster data rate. It is not a
firmware lever.

## Duty cycle

`dwell = 125 + settle + 50 x AVG`, integration is `50 x AVG`, so at the floor settle
`duty = 52.2A / (154.8 + 52.2A)`:

| AVG | dwell | duty | alternation |
|---|---|---|---|
| 4, settle 250 (until 2026-09-03) | 575 ms | **34.8%** | 1.15 s |
| 4 (floor settle) | 364 ms | 57% | 0.73 s |
| 8 (floor settle) | 572 ms | **73%** | 1.14 s |
| 16 (floor settle) | 990 ms | 84% | 1.98 s |

Averaging MORE raises duty, because averaging is the ADC doing useful work; only dead
time, settle and discards are waste. Cutting AVG_CONVERSIONS to 1 now that the PGA has
removed the transient it was a palliative for would take duty to 12%.

**But the floor settle is the -13 uV condition.** Duty and the uV tail trade directly,
and having both requires removing the tail at its source.

## What the tail is: RESOLVED -- dielectric absorption in the 100 nF X7R

Measured 2026-09-03 by a six-plateau sweep at 20/12/8/4/2/20 V on the E3633A
(`pwr-metering` `plans/relay-mux-settle-tail.md`, raw data archived alongside it).
The discriminator was whether the bias scales with the input step: dielectric
absorption does, thermal EMF does not.

| plateau | step at ADC | t=157 ms | t=209 ms | t=261 ms | null control |
|---|---|---|---|---|---|
| 20 V #1 | 0.3989 V | -9.64 +- 0.73 | -5.70 +- 0.46 | -3.17 +- 0.42 | +0.20 +- 0.62 |
| 12 V | 0.2393 V | -6.60 +- 0.24 | -3.36 +- 0.31 | -1.58 +- 0.45 | +0.18 +- 0.19 |
| 8 V | 0.1596 V | -3.91 +- 0.17 | -2.30 +- 1.15 | -1.11 +- 0.35 | +0.00 +- 0.13 |
| 4 V | 0.0799 V | -2.17 +- 0.16 | -0.84 +- 0.30 | -0.86 +- 0.22 | -0.13 +- 0.36 |
| 2 V | 0.0401 V | -1.26 +- 0.41 | -0.25 +- 0.26 | -0.32 +- 0.23 | +0.42 +- 0.40 |
| 20 V #6 | 0.3992 V | -11.22 +- 2.58 | -- | -4.45 +- 0.38 | +2.63 +- 0.83 |

Regressing bias on step size at the earliest reachable instant:

    t=157 ms   slope -25.73 +- 0.86 uV/V (29.9 sigma)
               intercept -0.06 +- 0.09 uV (0.7 sigma)

DA predicted a significant slope and a zero intercept. Thermal EMF predicted a
zero slope and a **-13.07 uV** intercept, which this excludes at **33.7 sigma** via the
intercept -- and at **145 sigma** via the zero-step plateau below, which does not
depend on the -13.07 anchor or its +-0.32 at all.
The 2 V plateau decides it on its own: thermal EMF predicted -13.07 uV there, DA
predicted -1.03, and the measurement is **-1.26 +- 0.41 uV**. This is why the LOW
plateaus are the sharp test and not the high ones -- the noise floor is ADC noise
and stays at ~0.6 uV, while the gap between the predictions grows as the input
falls.

Three independent checks agree. The null control is zero on every plateau. The
drift control (first and last plateau, both at 20 V) agrees to 0.6 sigma. And the
fitted slope reproduces the earlier 26 V bench-bus anchor of -13.07 uV / 0.5147 V
= -25.4 uV/V, from a completely different source.

At 366 ms the slope falls to ~1 sigma -- the tail is simply gone by then, which
is the same statement the original null control made, arrived at independently.

**The decisive point came for free.** After the sweep switched the supply off the
board kept alternating, giving a plateau at step ~ 0:

| plateau | step | t=157 ms | t=209 ms | t=261 ms |
|---|---|---|---|---|
| 0 V | 0.0001 V | **-0.06 +- 0.09** | +0.18 +- 0.13 | +0.20 +- 0.16 |

The relay is switching exactly as before -- same contacts, same ~71 mW coil, same
cadence -- so thermal EMF is fully present there and still predicts -13.07 uV.
Measured -0.06 +- 0.09 uV: excluded at **145 sigma at the point**, not by
extrapolating a fitted intercept to a step nothing was measured at.

**And the exponent identifies the mechanism, where the slope only discriminated
it.** Several mechanisms scale with the step; they differ in the power.
chi2/dof at t=157 ms over seven plateaus:

| model | mechanism | chi2/dof |
|---|---|---|
| **y = a*step** | **dielectric absorption** | **1.10** |
| y = b*step^2 | resistor self-heating (V^2/R) | 42.2 |
| y = const | thermal EMF, or any fixed offset | 181.2 |

The exponent is 1, which rules out self-heating in the divider's 1 MOhm
resistors -- the most plausible remaining step-correlated alternative. Together
with tau ~ 75 ms, which no lumped RC here can produce (the filter's own is
2.16 ms; 75 ms across 19.6 kOhm would need 3.8 uF), what survives is dielectric
relaxation.

**So the asymmetry that pointed at two relays warming differently was a red
herring.** A and B do bias toward each other, but B's input is open: it has no
step to absorb, so nothing about B's magnitude constrains a step-proportional
mechanism on A.

### What this does and does not establish

It establishes a **slow relaxation, linear in the input step, tau ~ 102 +- 7 ms**,
and it excludes both a fixed series offset (thermal EMF) and any V^2-driven
mechanism such as resistor self-heating.

It does **not** on its own localise that relaxation to the shunt-adc board's
`CD1`-`CD4`. Dielectric effects in the common-mode caps, the relay package or the
wiring, and slow memory in the ADC front end, all remain consistent with a linear
step-proportional relaxation. `CD1`-`CD4` is the prime suspect because it is the
largest dielectric in the loop by two orders of magnitude and sits directly
across the measured pair -- and the cap swap is itself the experiment that
closes the question.

(An earlier revision of this section quoted tau = 75 ms, an effective DA of
0.097%, and a 59 sigma exclusion. The 75 ms was carried over from the earlier
bench-bus run rather than fitted to this one; the DA loop resistance omitted the
filter's own series pair; and the 59 sigma omitted the uncertainty on the value
being excluded. Corrected after an independent review.)

### What to do about it

**Done and CONFIRMED 2026-09-03.** `CD1`-`CD4` on the shunt-adc board moved to
`GRM3195C1H104JA05D`, 100 nF C0G 50 V 1206 (`pwr-metering` `hw/shunt-adc`
finding F23), the board regenerated and re-verified (ERC 0/0, DRC 0/0,
`audit_pcb.py` all PASS with every guard calibrated, 0 unrouted, input-pair
mismatch still 0.0 um), then the identical sweep re-run:

| | slope at t=157 ms |
|---|---|
| X7R 0603 | -25.73 +- 0.86 uV/V (29.9 sigma) |
| **C0G 1206** | **-0.24 +- 2.04 uV/V (0.1 sigma -- consistent with zero)** |
| difference | 25.49 +- 2.21 = **11.5 sigma** |

Per plateau at t=157 ms: 20 V -9.64 -> **-0.81 +- 0.91**, 12 V -6.60 ->
**-1.13 +- 0.52**, 8 V -3.91 -> **+0.08 +- 0.15**, 2 V -1.26 -> **-0.24 +- 0.14**.
At the 20 V plateau the bias goes from 3.9x the 2.5 uV target to inside it.

**This also closes the localisation gap above.** Only `CD1`-`CD4` changed --
same relays, divider, wiring, ADC and firmware -- and the tail vanished, so the
mechanism was in those capacitors and not in the CM caps, the relay package, the
wiring or the ADC front end.

**So the 250 ms settle is no longer buying anything**, and settle can fall
toward the 157 ms hardware floor: ADC duty 35 % -> ~73 % at AVG 8. Residual to
watch: t=209 ms reads -4.06 +- 1.09 uV/V (3.7 sigma) on n=4, which cannot be a
real tail while t=157 ms reads 0.1 sigma, but should be re-checked.

`hw/shunt-adc/sch_design.py:727` chose X7R over C0G and justified it partly as
"with the PGA enabled the input is 1 GOhm so there is no charge-transfer path for
dielectric absorption". That is true of the ADC side, and it is why this defect
was not anticipated -- **DA's error develops across the SOURCE**, which this
fixture changed from the Kelvin-sensed ~0 Ohm burden shunt the filter was designed
for to the divider's 19.6 kOhm. Correct that comment wherever the part is
respecified. The implied DA branch follows from tau = 102 +- 7 ms across the 21.6 kOhm loop
(19.6 kOhm source plus the filter's own 2 kOhm series pair),
an effective DA of ~0.123% -- entirely ordinary for X7R, and harmless in the
application the filter was drawn for.

The fix is passive: C0G or film in place of the 100 nF X7R, a smaller value, or a
lower source impedance. Then settle can fall toward the 157 ms hardware floor and
ADC duty rises from 35% to ~73%. Re-run the plateau sweep afterwards to confirm
the tail is gone rather than merely smaller.

**No relay change is needed.** That branch was also the expensive one: the fitted
part is `3502-05-511`, already Coto's best thermal-EMF grade (<0.5 uV
differential), with stock 0 and 0 on order.

The filter's own RC was never a candidate: 21.6 kOhm x 100 nF = 2.16 ms, i.e.
e^-73 by 157 ms.

## The production retune: least dead time, half the switching frequency

With the tail gone the settle margin no longer buys anything, so the timing was
re-derived from what the parts actually specify. Requested outcome: the smallest
defensible dead time, and half the switching rate.

| | before | after |
|---|---|---|
| `DEAD_TIME_MS` | 50 | **5** |
| `SETTLE_MS_DEFAULT` | 250 | **30** |
| `AVG_CONVERSIONS` | 4 | **20** |
| round trip, **measured** | **1.149 s** (22 conv, no spread) | **2.298 / 2.356 s** (44 / 45 conv), mean 2.338 |
| switching frequency | 0.870 Hz | **0.428 Hz — down 50.8%** |
| duty (integration / dwell) | 36.4% | **89.3%** |
| sample instant after ARM | 157 ms | 157 ms (unchanged) |

Both round-trip figures are measured from the published sample timestamps, not
derived: 3109 points/hour for eight hours before the change, all at 1.149 s with
median equal to mode, and 179 points over seven minutes after it.

Two things make this free rather than a trade.

**The sample instant does not move.** The converter free-runs, so `settleMs` does not
decide *when* the sample is taken -- only which free-running conversion the discards
land on. Every settle from 1 to 52.22 ms yields the same 157 ms instant. Dropping 250
to 30 therefore costs nothing in settling, and there is no point going below it either.
A's spread over the seven minutes was 6.1 uV.

**The dead time is still a margin over an unmeasured quantity -- the datasheet does not
close it.** `DEAD_TIME_MS` exists to guarantee the outgoing contact has released before
the incoming one closes. The Coto 3500-series datasheet gives the 3502 **release 0.1 ms
typical**, and it is tempting to call 5 ms "50x that". It is not, for two reasons: the
0.1 ms is measured "At Nominal Coil Voltage, 30 Hz Square Wave" with **no coil
suppression specified**, while this board fits D3/D4, plain 1N4148W flyback diodes that
hold coil current circulating at ~0.7 V of forcing and stretch the flux decay -- and
DESIGN.md says so itself, *"change to a diode/Zener clamp only if the plain diode cannot
meet dead-time requirements"*. Second, 0.1 ms is typical and Coto publishes no maximum.

What makes 5 ms comfortable is that the dead window is **not** the primary non-overlap
margin. On an A<->B alternation the incoming channel's delay-on capacitor has been
discharged for a whole dwell, so after ARM rises that coil still needs the fastest-corner
15.95 ms before it can pull in. The dead window is a second, independent margin -- the
one that survives a failed delay-on network -- and 5 ms of it costs nothing at the
current rate. Spending it down to `DEAD_MIN_MS = 1` would buy 4 ms of headroom nobody
has shown is needed.

That number was *not* measurable on this rig, and the attempt is worth recording. A
dead-time sweep was written to read the ADC at the end of the dead window and look for
the moment the reading stops being the channel just left. It was flashed before the
flaw was noticed: **B's node discharges through the divider's 19.6 kOhm into 100 nF,
tau ~ 2 ms, while the sample is 157-366 ms later.** Whatever the contacts were doing
had decayed by e^-75 before anything looked. The firmware comment that justified the
sweep claimed tau ~ 100 ms through the 1 MOhm leg and had simply ignored the 20 kOhm
low leg. **An ADC behind a divider cannot measure contact overlap** -- that needs a
scope on the node, and DESIGN.md's qualification item stays open. 0.1 ms is *typical*;
Coto publishes no maximum.

### The rate cliff is real, and 45 ms was on the wrong side of it

The dwell is a whole number of conversions,
`ceil((dead + settle) / 52.22) + 1 + AVG_CONVERSIONS`, so keeping `dead + settle`
inside one conversion is worth a whole conversion *per dwell*, i.e. two per round trip.
The first production build set settle to 45 ms -- `dead + settle = 50`, satisfying the
inequality with 2.2 ms to spare -- and the bench returned round trips of **45 / 46 / 47
conversions (2.350 / 2.402 / 2.461 s), with 47 the mode**, against the 44 predicted.

Settle went to **30 ms**, and the whole distribution moved down by exactly one
conversion per dwell: **44 / 45 conversions, 31% / 68%**. A 15 ms change cannot move a
`ceil` whose argument is 35-50 ms against a 52.22 ms period -- unless the argument is
larger than `dead + settle`. It is: the timer is evaluated by `realTimeTask`, which
also runs `relayMux.tick()` and `samplers.updateAll()` on every pass, so the quantity
being rounded up is `dead + settle + latency`.

The `static_assert` bound therefore went from 52 to **40**, so the build fails while
there is still headroom for that latency rather than only once the inequality itself
breaks. At 45 ms the inequality held and the cliff was fallen off anyway.

### What is still not deterministic, and why 50.8% rather than 50.0%

The old configuration was perfectly repeatable -- 1.149 s, no second mode, over
thousands of samples. The new one is not: two thirds of round trips take one conversion
more than the other third. Since `dead + settle = 35 ms` now sits 17.2 ms below the
boundary and the loop's own yield is `vTaskDelay(1)`, a simple 1 ms poll granularity
does not account for it, and **the mechanism is not established.**

What can be said is the size of it: 0.4 conversions per dwell on average, 2.3% of the
round trip, which is why the switching frequency fell by 50.8% rather than 50.0%.
`AVG_CONVERSIONS` is the only coarse knob and it must stay even, so 20 is the closest
reachable value -- 18 would undershoot to ~1.85x. Do not read the 2x in this section as
exact; the measured ratio is **2.035**.

### The auto-widener had to be fixed to survive this

The widener compared `tStableMs` against `settleMs`. That was a category error hidden
by the old 250 ms value: `stable` needs `STABLE_N = 3` agreeing conversions, so
`tStableMs` cannot report earlier than ~157 ms, and against a 30 ms settle the test
would be true on **every** switch -- ratcheting the settle straight back up and undoing
the configuration permanently on the first dwell.

It now compares against `sampleInstantMs(settleMs) + CONVERSION_MS`, i.e. against when
the published conversion actually ends, plus one conversion of headroom. The headroom
is required, not padding: `tStableMs` is quantised to the conversion grid and its floor
ranges over a whole conversion (~104-157 ms) depending on phase, so without it the
widener fires on the unlucky phase alone. Rarely is worse than never here, because one
spurious widen is permanent -- the widener only ever increases.

Confirmed on the bench: over seven minutes the first half and second half of the run
both median 2.356 s. A firing widener would show as a monotonically growing round trip.

## VMUX_B's oscillation is not a fault

B (open input) shows ~50 µV peak-to-peak of slow sine. That is mains reaching the
ADC node *through* the 1 MΩ high leg from the open pigtail — attenuated 51:1, then
hit by the FIR's 50/60 Hz notch — beating at the grid's own drift against the
notch. The ADC node itself is ~20 kΩ either way; what differs is that A's divider
top is driven by a low-impedance source that shorts the pickup out, while B's
floats. Expect it to collapse when B is connected to anything real.

**Its visibility is set by the settle time, which is why it arrives in bursts
during a settle sweep.** Median block sd on B against A, over the 2026-09-03
runs:

| settle | B (open) | A (driven) |
|---|---|---|
| 250 ms | 2.6 uV | 1.1 uV |
| 120 ms | 16.3 uV | 1.2 uV |
| 35 ms | 17.2 uV | 1.0 uV |

A is flat at ~1 uV at every settle; only B varies, monotonically. After the
contact closes, B's node -- 1 MOhm into an unterminated pigtail -- settles
through picoamp currents, and the residual at the sample instant depends on the
mains phase *at the moment of closure*, which is random from switch to switch.
The tell that it is a random-phase transient and not an offset: B's MEAN stays
at -14 uV across every tag while its spread changes 6x. On a Grafana trace this
looks like bursts of noise every ~20 s, which is simply the firmware stepping to
the next settle value. It does not enter the A measurement.

Its *character* changed when the temperature read was disabled: the restart had
been jittering the sample interval (1008–1208 ms), smearing the alias. Without it
the interval is 1147–1149 ms and the alias goes coherent. The same defect was
corrupting timing as well as amplitude.

## Not verified

- **Contact release time.** `DEAD_TIME_MS = 5` rests on Coto's *typical* 0.1 ms; no
  maximum is published, and the datasheet is the only source. It cannot be measured
  from the ADC (see the retune section: the node's own tau is ~2 ms against a 157 ms
  sample), so this stays a scope job.
- **High-voltage headroom.** The PGA margin table above is arithmetic. Nothing has
  been measured above 1.2 V in, so the 80 V and 100 V rows are unconfirmed.
- **The 165 nA** figure, as noted.
- **The post-restart discard** — the direct fix for defect 1 — is not implemented.
  Enabling the PGA removed the symptom on this path by removing the *mechanism*
  (bias current into a 19.6 kΩ source); the restart itself is untouched.
- **The BLE `download` trigger** is on the board but has never been fired.
- **`DIAG_RELAY_UNMATCHED` has never been seen set.** The code path is reached only
  on a source change; the fix was verified by the channel *recovering*, not by the
  flag appearing.
- **`moveEpsV = 100 µV` is a reasoned choice, not a measured one.** It is ~100× the
  noise floor, which bounds false "moved" verdicts, but the value that matters is
  how far apart the two channels must be before a stuck contact is worth catching,
  and that is a bench fact about the contacts.
- **The implied divider ratio moved with the source**: 51.21 at 1.2 V, 51.39 at
  1.5 V (0.35%). That is within a bench supply's dial accuracy and is not evidence
  of divider nonlinearity — but it has not been checked against a DMM.
- **The BLE OTA/control surface is unauthenticated.** Any nearby client can write
  `download` and force the board into the ROM downloader; secure boot is disabled,
  so an attacker could already push a chosen image. Recoverable (power cycle), but
  it is a denial-of-service on an open characteristic.
- **`download` recovery was mis-documented.** "Reset twice" does not work: in the
  ROM downloader the app never runs, so `setup()`'s disarm never executes. Only a
  flash or a **power cycle** clears the bit.

## Reflashing this board

USB is dead. Use OTA over BLE — it works and needs nobody at the bench. The recipe
and its three separate gotchas (venv, Bumble backend rather than BlueZ, root for
the HCI socket) are in `doc/ota-over-ble.md` and the session memory.

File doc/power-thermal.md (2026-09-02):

# Power and thermals on the ESP32-S3 shunt boards

Measured 2026-09-02 on the live two-INA228 XIAO (`esp32s3_2ina228`), firmware `29514e8` +
`8122fb6`. Die temperatures come from the ESP32-S3 on-die sensor: coarse, self-heated, a
trend indicator and not a calibrated figure. Rates are points/s/device from the collector's
journal on `rpi.local`.

## The short version

**Only the CPU clock moves the temperature.** Everything else tested is flat.

| Lever | Effect on die temp | Verdict |
|---|---|---|
| CPU 240 → 80 MHz | **−6.5 K** | keep |
| BLE TX power, +9 → −12 dBm | 0.16 K, below the 0.9 K error bar | dropped, reverted to stack default |
| BLE conn interval, 30 ms → 195 ms + latency 3 | ~0 K | keep for airtime, **not** for heat |
| PSRAM power-down | — | **no lever exists**, never initialised |
| BT controller / CPU sleep | not measurable | **out of reach** in the Arduino libs |

Best configuration: **80 MHz, stack-default TX power, 195 ms / lat 3, 400 ms publish
period.** Full data rate (2.48/s/device), 780 ms central→device window inside the 1 s
budget, and one step back from the 400 ms interval that loses 19% of samples.

It is not the *coolest* configuration — no BLE setting changes the temperature at all. It
is the coolest one the CPU clock can give, with the link set where it costs nothing.

## What the numbers were

CPU clock, one reset, port held open across the switch, so the halves differ only in the
variable under test:

| Config | Die °C | Rate /s |
|---|---|---|
| 80 MHz | **63.7** | 2.43 |
| 240 MHz | **70.2** | 2.49 |

BLE sweep, 240 s per point, only the last 100 s averaged so the thermal transient after
each change is excluded. **Read the rate column, not the temperature column** — see the
drift caveat below.

| # | Point | Die °C | Link | Rate /s |
|---|---|---|---|---|
| 1 | TX −3 dBm | 64.62 | 195 ms / lat 3 | 2.48 |
| 2 | TX +9 dBm | 64.50 | 195 ms / lat 3 | 2.46 |
| 3 | TX −12 dBm | 64.66 | 195 ms / lat 3 | 2.48 |
| 4 | TX −3 dBm *(repeat)* | 64.00 | 195 ms / lat 3 | 2.48 |
| 5 | conn 30 ms / lat 0 | 64.22 | 30 ms / lat 0 | 2.49 |
| 6 | conn 195 ms / lat 0 | 63.78 | 195 ms / lat 0 | 2.48 |
| 7 | conn 195 ms / lat 3 *(repeat)* | 63.72 | 195 ms / lat 3 | 2.49 |
| 8 | conn 400 ms / lat 3 | 63.78 | 397.5 ms / lat 3 | **2.01** |

### The error bar is bigger than every BLE effect

The same configuration, `195 ms / lat 3`, was measured three times across the run:
**64.62 → 64.00 → 63.72 °C**. And the whole column drifts downward monotonically with
elapsed time, regardless of what is being tested — ambient falling through the evening.

**Sweep order is therefore confounded with the effect**, and every BLE difference in the
table is smaller than that 0.9 K. The flaw was sweeping sequentially instead of
interleaving. The CPU A/B is unaffected: it ran 80 → 240 → 80 inside one 11-minute window,
and the return leg confirmed the drop (70.7 → 68.7 → 66.7).

### The only BLE settings that do anything, break things

Point 8 (397.5 ms interval) lost **19% of samples**; a 200 ms publish period at a 195 ms
interval lost **36%**. Both were thermally flat. `flush()` ships one indication per round
trip and a round trip costs ~1.6 connection intervals, so a period near the interval has no
headroom and the queue sheds. Point 8's skip window is also 1590 ms, past the 1 s budget.

A sweep judged on temperature alone would have called both free wins. **The throughput
cross-check is the only thing that saw them** — and it is why `blerate`'s floor is now
computed from the live interval instead of the fixed 200 ms that measurement disproved.

### Why BLE cannot show up

Cutting RX windows 26× (30 ms → 780 ms effective) changed nothing thermally, and a 3.5×
change in publish rate moved it 0.2 K. The radio's *event* work is a rounding error next to
a CPU and a BLE controller that never sleep. Which is the real finding:

> The residual ~64 °C is baseline, not workload.

`CONFIG_PM_ENABLE` and tickless idle are absent from the prebuilt Arduino sdkconfig, so the
obvious next move looks like an ESP-IDF port to switch them on.

**Do not make that port for thermal reasons — it has already been tried and it does not
work.** `~/dev/ha/nimble-ble-proxy` is a native ESP-IDF build that already sets
`CONFIG_PM_ENABLE=y`, `CONFIG_FREERTOS_USE_TICKLESS_IDLE=y` and
`CONFIG_PM_POWER_DOWN_CPU_IN_LIGHT_SLEEP=y`. Its `docs/thermal-notes.md` records the
result: **0 °C change, temperature flat at 57.6 °C across the soak.** Light sleep never
engages, because the SoC refuses it while Bluetooth is enabled — boot log, verbatim:

> light sleep mode will not be able to apply when bluetooth is enabled

This board holds a BLE connection permanently, so the same applies. The always-on radio
baseline is not a configuration mistake that a port would fix; it is what an ESP32-S3 costs
while its controller is up. See "Prior art" below.

## Configuration notes

### 80 MHz is a floor, not a preference

Below 80 MHz arduino-esp32 switches the CPU to the XTAL and powers the PLL down — taking
the 48 MHz USB-Serial-JTAG clock with it (console gone, physical BOOT+RESET to recover) and
dropping APB below 80 MHz, re-deriving every UART/I2C/SPI divider configured against it. At
80 MHz the PLL stays up and **APB stays at 80 MHz**, so peripheral clocks are bit-for-bit
unchanged; the ADS1262 is on hardware SPI, not bit-banged, so its timing does not move
either. NimBLE also requires ≥ 80 MHz. Override with `-D CPU_FREQ_MHZ=160`.

### Slave latency: keep it, for airtime not for heat

Points 6 and 7 isolate it at equal interval: latency 0 and latency 3 both deliver
**2.48 points/s**, so a peripheral with data queued does transmit at the next connection
event regardless of latency. Measured, not inferred. What is delayed is central→device
delivery (aux commands, OTA start), by at most
`latency × interval` = 780 ms. OTA takes the link back to latency 0 via the existing
`Fast` path. Supervision timeout must outlast the skipping —
`(1 + latency) × interval_max × 2` = 1.6 s against the 4 s requested — and `bleconn`
refuses anything that violates it.

It does not cool the board. Keep it because it cuts airtime on an rpi sharing one radio
between three links, a continuous scan and a 20 s initiating window — the contention that
has previously killed OTA transfers with an LL timeout.

### Console knobs (none persist)

    cpufreq [80|160|240]        clock + APB + die temp
    bletx [dBm]                 TX power; radio rounds to its own ladder
    blerate [ms]                publish period; floor = 2x negotiated interval, max 700 ms
    bleconn <min> <max> <lat>   LL units (1.25 ms), refuses unsafe latency

None persist, deliberately: a value that starves the link should be one power-cycle away
from gone. Make one permanent with a build flag. The `blerate` floor is computed live
rather than fixed, because the central owns the interval — see the ratio table in
`telemetry.h`.

## Measurement traps found the hard way

Three claims were asserted in writing before they were measured, and all three were wrong.
They are recorded because each one is a trap this bench will set again.

**1. Reading the serial port RESETS this board.** Native USB-CDC. Every
connect-ask-disconnect reading is taken ~0.5 s after a reset and describes the reset, not
the running board. Two were once compared as a before/after; they differed only in how long
the chip had been idle in the bootloader, so the *improved* config read hotter. The same
transient flatters a touch test: the board takes ~5 minutes to climb from 50 °C to 63.7 °C,
and anything felt inside that window feels like an improvement.

> To watch a running board: pay one reset, hold the port open, and let the board talk.
> That is why the firmware prints a periodic `pwr:` line rather than answering a query.

Note this contradicts the general rule in `CLAUDE.md` that serial reads are free on the
ESP32-S3. It holds for the boards in that note; it does **not** hold here.

**2. The collector's RSSI is useless for this.** It reports `self.advertisement.rssi`, and
`smart-shunt-ble-client.py` line 2 carries its own `todo use bluetoothctl to get real-time
rssi`. A connected peripheral does not advertise, so the value is frozen at the last
advertisement before the connection. A −38 → −48 shift was briefly read as a TX change
taking effect; it was a reconnect picking up a different advertisement. Device-side RSSI
does not fix it either — at the peripheral, `ble_gap_conn_rssi` reports what the *central*
transmits. Only the rpi can measure our TX power, and bumble owns that adapter exclusively.
**TX power is unmeasurable on this bench.**

**3. PSRAM was never running.** The boot banner reads `psram 0 B`.
`CONFIG_SPIRAM_BOOT_INIT` is set in the `qio_opi` sdkconfig, but
`CONFIG_SPIRAM_IGNORE_NOTFOUND` silently tolerates a part that does not answer, and
`ESP.getPsramSize()` would report 8 MB had it initialised (`SPIRAM_USE_MALLOC` is set). The
"8 MB clocked for nothing" lever never existed, and the bootloader-level `memory_type`
change it needed — failure mode: physical BOOT+RESET — was correctly not made.

## Prior art: the same investigation, on a different board

`~/dev/ha/nimble-ble-proxy/docs/thermal-notes.md` ran this exercise first, on an ESP32-S3
running WiFi STA + a NimBLE scanner. Read it before re-deriving anything here. It found the
same shape of answer, independently:

| Lever | Their result | Ours |
|---|---|---|
| CPU clock | −3.0 °C (160 → 80 MHz) | −6.5 K (240 → 80 MHz) |
| Radio TX power | −1.7 °C (WiFi, 20 → 13 dBm) | 0.16 K (BLE, 21 dB span) |
| Light sleep / CPU power-down | **0 °C** — never engages with BT on | not reachable, and moot |
| Sensor noise | ±1.5 °C, wandered 3 steps at fixed settings | 0.9 K drift over one sweep |

Two things follow. First, **we already hold both of their working levers**: this board runs
at 80 MHz, and its WiFi radio is off entirely (`disableWifi` is the boot default), which is
strictly better than turning its TX power down. Second, their sensor-noise caveat matches
ours almost exactly — two independent investigations both found the per-lever deltas
comparable to the measurement noise.

Their board settles at **51.6 °C (80 MHz) to 58 °C**, against our 63.7 °C, despite *also*
running WiFi. Since the firmware levers are already equal, the difference is not firmware:
it is board thermal design — the XIAO is a very small PCB with little copper to spread into
— plus ambient, airflow, and the fact that two different dies' on-die sensors are not
cross-calibrated. **Die temperature is not comparable between boards.**

## Method — and how this sweep got it wrong

- Change one variable, hold 240 s, average only the last 100 s. The board takes ~3 minutes
  to settle; anything shorter measures the transient.
- **Always cross-check throughput** from the collector journal. A "saving" that quietly
  drops data is not a saving, and the sample rate is the only thing that catches it. This
  caught the 400 ms knee, which was thermally invisible.
- **Repeat a point, at both ends.** Without the repeats there would have been no error bar,
  and a 0.16 K non-monotonic wobble would have been written up as a trend.
- **Restore state between points.** The first sweep applied each point's commands
  *cumulatively*, so the three publish-rate points inherited the broken 400 ms connection
  interval from point 8 and measured a rate × degraded-link interaction instead of rate.
  All three were discarded and re-run with the connection parameters re-pinned before every
  point. The same bug also left the board sitting on the lossy 397.5 ms interval when the
  run ended — a sweep must end by restoring the shipping config explicitly, not by assuming
  its last point did.
- **Interleave or randomise.** Sequential sweeping confounded every sub-1 K result with
  ambient drift.

## Open

- **Board prefix is unset.** This unit publishes `ESP32_INA228_2` / `_4` with nothing
  identifying the board; they will collide with any other board using those names. One
  console command: `board-prefix <name>`, reset to apply.
- Publish-period sweep (200 / 400 / 700 ms at a pinned 195 ms / lat 3) is re-running after
  the cumulative-state bug above. Expect it to be thermally flat and to matter only at the
  throughput and latency bounds.
- **No further firmware lever is known.** The ESP-IDF/light-sleep route is closed (above).
  Getting meaningfully below ~64 °C means either disabling BLE — which is the product — or
  changing the thermal path: airflow, or copper for the package to spread into.

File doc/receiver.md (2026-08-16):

# Receiver

The host side of the BLE telemetry link is **not in this repo**. It lives in
[`pwr-metering`](git@github.com:fl4p/pwr-metering.git), next to the bench tooling that shares its
`util.py` and shells out to its aux CLI:

| File | |
|---|---|
| `smart-shunt-ble-client.py` | the collector — connects, decodes, publishes, drives the aux switch |
| `smart-shunt-aux.py` | CLI that edits `aux-state.json`; the collector applies it over the live link |
| `smart_shunt_clock_selftest.py` | regression test for the clock handling below — no BLE, no network |
| `aux_control_selftest.py` | the aux control-file reader |

It stays there rather than here because that is where its dependencies point: `ate/fan.py` invokes
the aux CLI (locally and over ssh), `ate/fan_selftest.py` reads the collector's source to get its
real constants, and the rig, the venv and the deploy target all sit in that tree. This firmware repo
has no code dependency on it in the other direction — only the wire contract below.

## Deploying

`rpi.local:~/pwr-metering` is a **git clone** (since 2026-08-16; it was a one-way PyCharm rsync
before, which let the box drift ~118 lines behind and stranded nine measurement runs that existed
nowhere else). So the box can be asked what it is running, and deployment is a pull:

```sh
ssh rpi.local 'cd pwr-metering && git status --porcelain && git log --oneline -1'   # what's running
ssh rpi.local 'cd pwr-metering && git pull' && ssh rpi.local 'sudo systemctl restart smart-shunt-ble'
```

The service is `smart-shunt-ble.service`. PyCharm autoUpload is deliberately **off** — an automatic
push into a checkout leaves `git status` permanently dirty, and a checkout that is always dirty
cannot answer the question it exists to answer.

Only one BLE central may hold the link, which is why aux control and OTA both go *through* the
collector rather than connecting alongside it.

## Wire contract

Defined by this firmware (`src/adc/sampling.h`, `src/energy_counter.h`) and decoded there, so a
change on either side has to be made with the other in mind.

- **`dev[16]`** — filled by `std::string::copy()`, which **appends no terminator**. A name of
  exactly 16 characters arrives with no NUL, so a decoder must not assume one; `dev[:dev.find(0)]`
  silently drops the last character when `find()` returns −1. Names longer than 16 bytes are
  truncated on the wire, and two names differing only past character 16 become one InfluxDB series —
  see `src/board_prefix.h`, which checks for exactly that.
- **Frame size** — 56 or 64 bytes; the 64-byte variant added the `diag` field, shifting everything
  after it. The collector auto-detects from the first CRC-valid frame.
- **CRC** — CRC-16 MODBUS over everything preceding it.
- **`idx`** — `uint8`, and it **wraps**; a gap check must mask.
- **`t`** — `gettimeofday()` **milliseconds on the device**, in one of two shapes, with nothing in
  the frame saying which:
  - **Unix ms**, if the board reached `timeSync()`.
  - **ms since boot**, on a BLE-only board — no WiFi, so SNTP never runs. The collector recovers
    wall-clock time as `min(host_now - t)` over frames: each observation is the true offset plus a
    non-negative transport delay, so the smallest is the least contaminated.

  Both shapes must be handled, and so must the **switch between them on a live link** — it happens
  the moment a device gets WiFi. A frame that cannot be placed on the host timeline is dropped
  rather than stamped with its arrival time; reception time is a different quantity from
  measurement time, and nothing downstream could separate them afterwards.

## In InfluxDB

The collector tags points `BLE_` + the name in `dev[16]`, so the series key is the sampler name this
firmware chose. That name only has to be unique within one board, but the **database is shared** by
every board reporting into it — hence the NVS board prefix (`board-prefix` on the console,
`src/board_prefix.h`). Two boards running this firmware both published `BLE_TMP117` before it
existed.

Transport is UDP to a relay on the rpi (`influxdb-udp-relay.service`), which batches and forwards
over HTTP. UDP means a gap reads as "not delivered", never as "unchanged" — which is why the aux
series has a heartbeat rather than being change-only.

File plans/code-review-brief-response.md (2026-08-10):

# Code Review Response — Refactored Abstraction Layer

The refactor is not behaviorally equivalent. I found one introduced OTA safety bug, three clear ESP32 regressions, and a pre-existing STM32 runtime blocker. Both intended environments compile and link successfully; no source files were changed during the review.

## Findings

### 1. BUG — OTA can reach the sleep decision before the active-OTA guard

The new app loop calls `telemetry->update()` before recording that OTA is active (`src/main_esp32.cpp:206`). But `Telemetry::update()` performs `checkIdleSleep()` internally, which may call `ESP.deepSleep()` before control returns (`src/telemetry.h:77`).
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

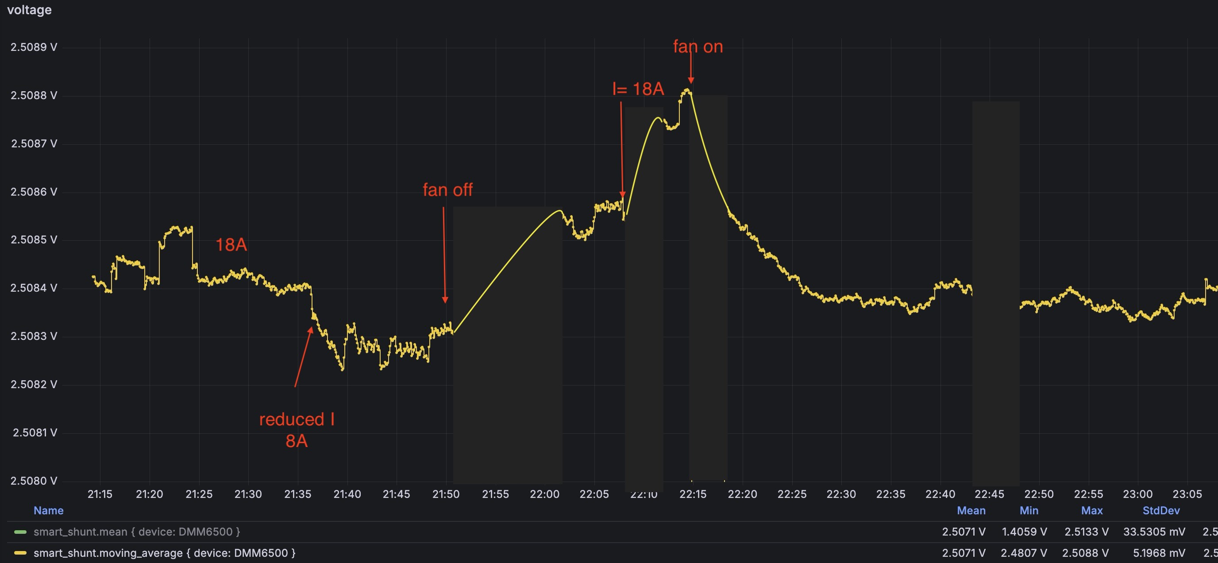
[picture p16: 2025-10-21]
doc/ratio-rsn-20-50-and-50-50-fan.jpg

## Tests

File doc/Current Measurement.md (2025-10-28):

* higher burden voltage, lower offset error, less noise, better precision
* keep the burden resistor heated at stable temperature, to avoid temp drift
* place first gain amp close to the resistor (on the same PCB). connectors might add offset voltage due to
  thermoelectric effect between different metals. and long cables add noise. temperature of the PCB will be regulated
  anyways so temp drift of the gain amp will not matter.

# adc

* low drift

from ina228:
"The ADC architecture enables
lower drift measurement across temperature and consistent offset measurements across the common-mode
voltage, temperature, and power supply variations. A low-offset ADC is preferred in current sensing applications
to provide a near 0-V offset voltage that maximizes the useful dynamic range of the system."

# Avoid Jumper Cables

When measuring voltages in the mV range, avoid jumper cables. Instead use soldered connections with tinned copper
cables.

Here's an experiment:
This 2.54mm pitch connector is placed between a DM6500 and a 40mV voltage source.
(The 40mV come from a 2mΩ current sense resistor).
A heat gun set to 100°C is pointed at the connector, with T_Ambient = 20°C.


The orange line is the voltage measured by an INA228 chip on the same board with the resistor.
The green line is the voltage from the DM6500. Heat was added where the green line abruptly falls (17:49:07).
At 17:49:45 the hot air was removed.


* A temp rise by 80°C adds 0.15% error
* the connector in the test has a temperature drift ~20ppm/°C at 40mV
* that's 0.8µV/°C
* connectors have a temp drift (compare to Seebeck effect, [thermocouples](https://en.wikipedia.org/wiki/Thermocouple

Here's another example:


Two smart-shunt boards with ina228, supply and i2c isolated, the left board has a current sense resistor populated (
2mΩ).
The board on the right is left without CSR and the current sense inputs are connected in parallel to the one on the left
with a
standard
jumper cable. The connector pins (PRPC040SACN-RC) are made of brass with flash gold plating (thin gold and nickel
layer). The jumper wire terminals have a tin plating (similar to
JST [eXH](https://www.jst-mfg.com/product/pdf/eng/eXH.pdf), see below).


The yellow curve ist what the board on the right (ESP32_INA228) measured over time and is drifting from the jumper
cables. Peak-to-peak: 4mA which is 8µV here.
* Orange: what the board on the left measured.
* Blue: a third board for reference with same CSR.
* Green: DM6500 measuring voltage across a Riedon RSN-20-50B (20A/50mV). All devices measure the same current, which was ~300µA here.

I then replaced the jumper cable with wires soldered to the PCBs:


Tada, the drift is gone!

Notice that this time the current was actually 0, which only offset all curves.

This also tells us that the offset voltage of all 3 INA228 chips is 2µV (1mA).
The INA228 Datasheet says 1µV max.

A smoothin filter:


Reveals the `ESP32_INA228` and the `ESP32_INA228_3` both have a AC component with a period of 6 seconds.
TODO

# Jumper Wire

JST [eXH](https://www.jst-mfg.com/product/pdf/eng/eXH.pdf)).

[molex SL connectors](https://www.molex.com/en-us/products/connectors/wire-to-wire-connectors/sl-connectors) (
0016020103, 0016020087) have a gold coating.

See digikey for
more [contacts](https://www.digikey.de/en/products/filter/rectangular-connectors/rectangular-connector-contacts/331)
and [housings](https://www.digikey.de/en/products/filter/rectangular-connectors/rectangular-connector-housings/319).

Extra-long 2.5 pitch pin header with flash gold plating: PRPC040SACN-RC .

# Low Thermal EMF connectors
https://www.eevblog.com/forum/metrology/source-for-unplated-copper-fork-lugs/msg5804671/#msg5804671

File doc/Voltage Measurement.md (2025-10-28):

* precision resistors for voltage divider
  * low temp drift (even if temp drift would cancel out)
  * time drift
* consider input cap as buffer to reduce noise
* single ended
  * using a differential ADC with negative input tied to ground halves the dynamic range
    * use offset voltage
    * use instrumentation amp (THS4551 from XDS110ET)
* consider ADC input common mode contraints
  * usually ADC with pga need some voltage margin
  * however, for voltage measurements above the 1V range PGA can usually be bypassed
  * measurement ground might go below AGND. there are ADCs that support common modes <-1V below AGND
* generally no noise issue


* INA228 devices appear to have similar distortion
* ADS1220 has a lower INL
  * 5k/200k voltage divider
  * until 1.22V error is <20ppm
  * TODO
    * try PGA gain = 1, 2

monolythic resistor network
monolythic thin film array


https://youtu.be/D28uSzCs7-k?si=xbc2kDCH82Io2PJb&t=880
vhp101

vishay vsp 1442,1445,1446

Y0115V0720VV9L 500/69.5k, ±0.1ppm/°C
Y0115V0549AA0L 1k/100k
Y0115V0635VV9L 1.4k, 60.2k

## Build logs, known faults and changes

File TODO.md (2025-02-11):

* deskew sensors (at least what the delay is and set a max threshol)
* fix wirings ina226_3 <--> ina226
* build 1mOhm board and run test

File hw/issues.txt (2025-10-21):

- fuse voltage sense ground
- add jumper connect IN(-) with ground (using 50ohm resistor or 0?)
	- or capacitor as in ADS1013 dat sheet?
- add 3pin voltage divider/filter pin
- add jumper for ground bypass for HV measurements (common mode >80V)

TODO
- use THT voltage divider resistors (precision)
- isolated I2c bus?
	- or: stackable ina228 (isolated)
- high-speed ADC via spi for ssa-100?
	- 16bit - 20bi

ADS124S08

	- not well documented?
	https://github.com/jenschr/ADS124S08

ADS1220
	2ksps

ADS1252
	40khz?

ADS9212

gain drift
gain error

- EMF issues with solder jumpers and input resistors
- SPI version for speed

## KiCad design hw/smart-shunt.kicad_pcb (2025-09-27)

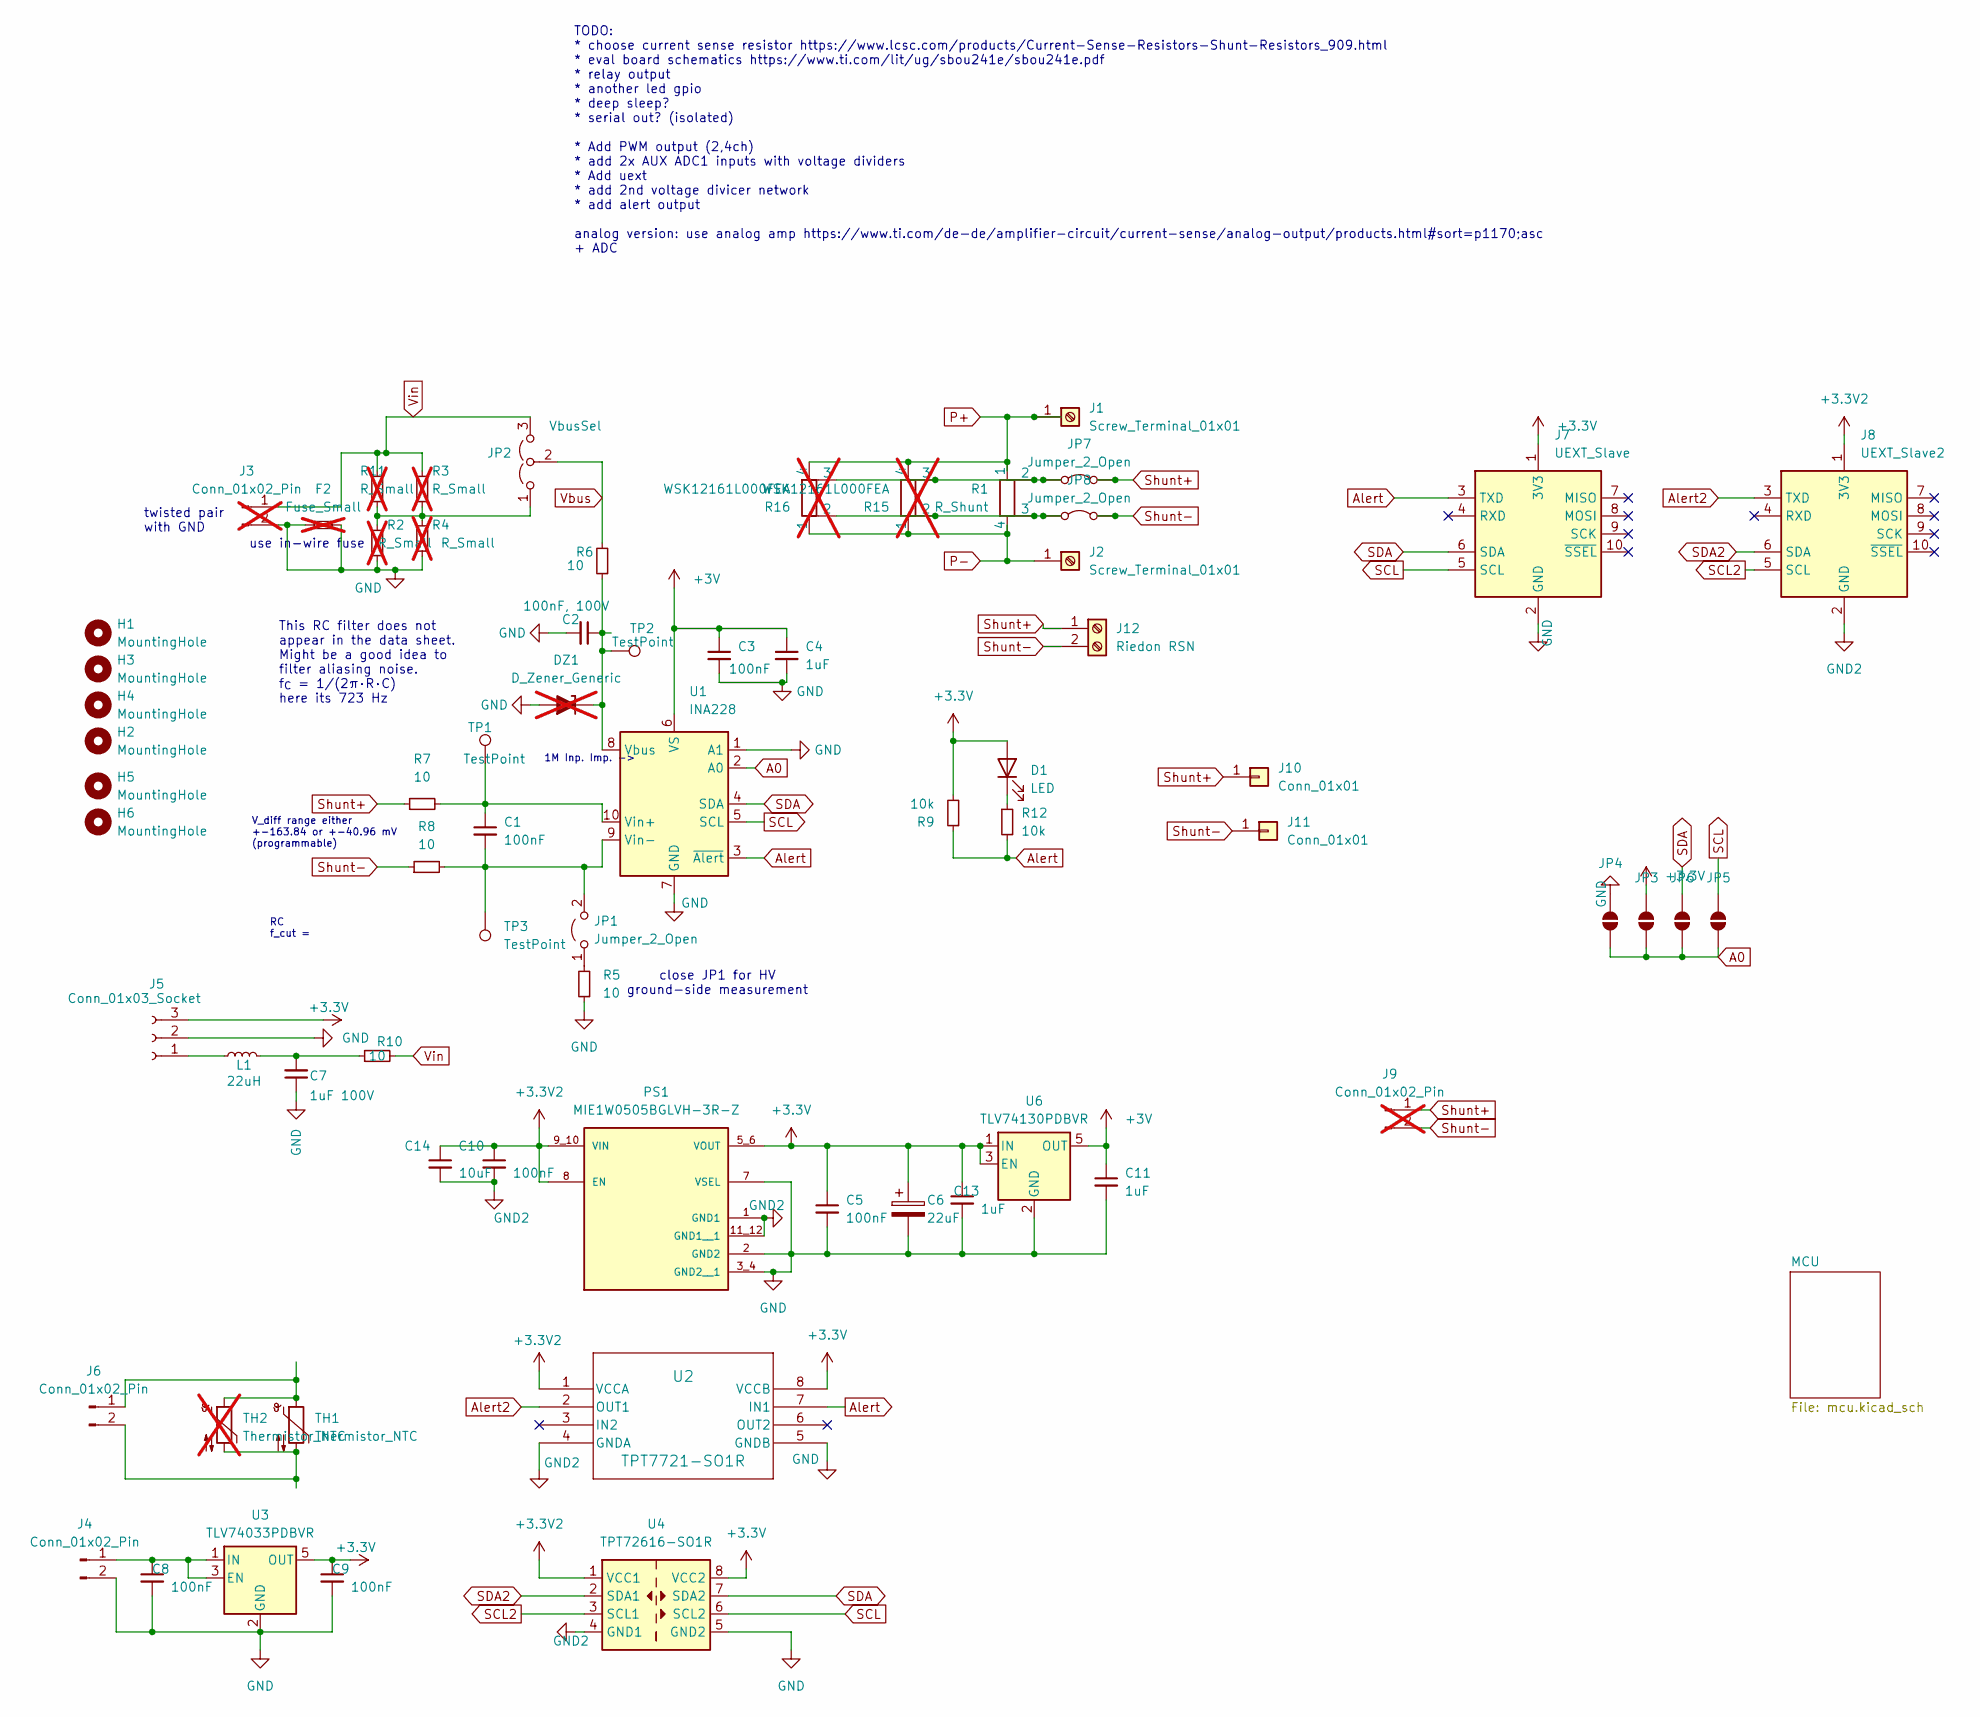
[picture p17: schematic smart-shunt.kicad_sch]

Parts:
C1, C3, C5, C8, C9, C10: 100nF; C_0805_2012Metric
C2: 100nF, 100V; C_0805_2012Metric
C4, C11, C13: 1uF; C_0805_2012Metric
C6: 22uF; CP_Elec_6.3x5.9; MPN A766EB226M1DLAE060
C7: 1uF 100V; C_0805_2012Metric
C14: 10uF; C_0805_2012Metric
D1: LED; LED_0805_2012Metric
DZ1: D_Zener_Generic; not fitted
F2: Fuse_Small; Fuseholder_Clip-5x20mm_Littelfuse_100_Inline_P20.50x4.60mm_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; not fitted
H1, H2, H3, H4, H5, H6: MountingHole; MountingHole_2.2mm_M2
J1, J2: Screw_Terminal_01x01; Wuerth_PowerPlus_M5_Nut
J3, J9: Conn_01x02_Pin; PinHeader_1x02_P2.54mm_Vertical; not fitted
J4, J6: Conn_01x02_Pin; PinHeader_1x02_P2.54mm_Vertical
J5: Conn_01x03_Socket; PinHeader_1x03_P2.54mm_Vertical
J7: UEXT_Slave; PinHeader_2x05_P2.54mm_Vertical
J8: UEXT_Slave2; PinHeader_2x05_P2.54mm_Vertical
J10, J11: Conn_01x01; PinHeader_1x01_P2.54mm_Vertical
J12: Riedon RSN; RiedonRSN
JP1: Jumper_2_Open; SolderJumper-2_P1.3mm_Open_RoundedPad1.0x1.5mm
JP2: VbusSel; SolderJumper-3_P1.3mm_Open_RoundedPad1.0x1.5mm
JP3, JP4, JP5, JP6: SolderJumper_2_Open; SolderJumper_0402_1005Metric
JP7, JP8: Jumper_2_Open; SolderJumper_0402_1005Metric_Bridged
L1: 22uH; L_0805_2012Metric; MPN MLZ2012N220LT000
PS1: MIE1W0505BGLVH-3R-Z; CONV_MIE1W0505BGLVH-3R-Z; PARTREV 0.8
R1: R_Shunt; R_Shunt_Isabellenhuette_BVR4026
R2, R11: R_Small; R_Axial_DIN0204_L3.6mm_D1.6mm_P7.62mm_Horizontal; not fitted
R3, R4: R_Small; R_0805_2012Metric; not fitted
R5, R6, R10: 10; R_0805_2012Metric
R7, R8: 10; R_0805_2012Metric_Bridged
R9, R12: 10k; R_0805_2012Metric
R15: WSK12161L000FEA; SMT_61L000FEA_VIS; not fitted
R16: WSK12161L000FEA; CSM3637_1-2mOHM_VIS; not fitted
TH1: Thermistor_NTC; R_0402_1005Metric
TH2: Thermistor_NTC; R_0402_1005Metric; not fitted
TP1, TP2, TP3: TestPoint; TestPoint_Pad_D1.0mm
U1: INA228; VSSOP-10_3x3mm_P0.5mm
U2: TPT7721-SO1R; SOP-8_3.9x4.9mm_P1.27mm
U3: TLV74033PDBVR; SOT-23-5
U4: TPT72616-SO1R; SOIC-8_3.9x4.9mm_P1.27mm
U6: TLV74130PDBVR; SOT-23-5

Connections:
+3.3V: C5.1, C6.1, C9.1, C13.1, D1.2 (A), J5.3, J7.1 (3V3), JP3.2 (B), PS1.5_6 (VOUT), R9.2, U2.8 (VCCB), U3.5 (OUT), U4.8 (VCC2), U6.1 (IN), U6.3 (EN); also elsewhere on the board
+3.3V2: C10.1, C14.1, J8.1 (3V3), PS1.8 (EN), PS1.9_10 (VIN), U2.1 (VCCA), U4.1 (VCC1)
+3V: C3.1, C4.1, C11.1, U1.6 (VS), U6.5 (OUT)
A0: JP3.1 (A), JP4.1 (A), JP5.1 (A), JP6.1 (A), U1.2 (A0)
Alert: J7.3 (TXD), R9.1, R12.2, U1.3 (~Alert), U2.7 (IN1)
Alert2: J8.3 (TXD), U2.2 (OUT1)
GND: C2.2, C3.2, C4.2, C5.2, C6.2, C7.1, C8.2, C9.2, C11.2, C13.2, DZ1.2 (A), F2.1, F2.2, J3.2, J4.2, J5.2, J7.2 (GND), JP4.2 (B), PS1.2 (GND2), PS1.3_4 (GND2__1), PS1.7 (VSEL), R2.1, R4.1, R5.1, U1.1 (A1), U1.7 (GND), U2.5 (GNDB), U3.2 (GND), U4.5 (GND2), U6.2 (GND)
GND2: C10.2, C14.2, J8.2 (GND), PS1.1 (GND1), PS1.11_12 (GND1__1), U2.4 (GNDA), U4.4 (GND1)
unnamed: C7.2, L1.2, R10.1
unnamed: D1.1 (K), R12.1
unnamed: C8.1, J4.1, U3.1 (IN), U3.3 (EN)
unnamed: J5.1, L1.1
unnamed: J6.1, TH1.1, TH2.1
unnamed: J6.2, TH1.2, TH2.2
unnamed: JP1.1 (A), R5.2
unnamed: C1.2, JP1.2 (B), R8.2, TP3.1, U1.9 (Vin-)
unnamed: JP2.1 (A), R2.2, R3.1, R4.2, R11.1
unnamed: JP7.1 (A), R1.2, R15.3, R16.3
unnamed: JP8.1 (A), R1.3, R15.2, R16.2
unnamed: C2.1, DZ1.1 (K), R6.1, TP2.1, U1.8 (Vbus)
unnamed: C1.1, R7.2, TP1.1, U1.10 (Vin+)
P+: J1.1, R1.1, R15.4, R16.4
P-: J2.1, R1.4, R15.1, R16.1
SCL: J7.5 (SCL), JP5.2 (B), U1.5 (SCL), U4.6 (SCL2); also elsewhere on the board
SCL2: J8.5 (SCL), U4.3 (SCL1)
SDA: J7.6 (SDA), JP6.2 (B), U1.4 (SDA), U4.7 (SDA2); also elsewhere on the board
SDA2: J8.6 (SDA), U4.2 (SDA1)
Shunt+: J9.1, J10.1, J12.1, JP7.2 (B), R7.1
Shunt-: J9.2, J11.1, J12.2, JP8.2 (B), R8.1
Vbus: JP2.2 (C), R6.2
Vin: J3.1, JP2.3 (B), R3.2, R10.2, R11.2

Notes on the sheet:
1M Inp. Imp. ->
RC f_cut =
This RC filter does not appear in the data sheet. Might be a good idea to filter aliasing noise. f_{C} = 1/(2π·R·C) here its 723 Hz
close JP1 for HV ground-side measurement
use in-wire fuse
TODO: * choose current sense resistor https://www.lcsc.com/products/Current-Sense-Resistors-Shunt-Resistors_909.html * eval board schematics https://www.ti.com/lit/ug/sbou241e/sbou241e.pdf * relay output * another led gpio * deep sleep? * serial out? (isolated) * Add PWM output (2,4ch) * add 2x AUX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
V_diff range either +-163.84 or +-40.96 mV (programmable)
twisted pair with GND

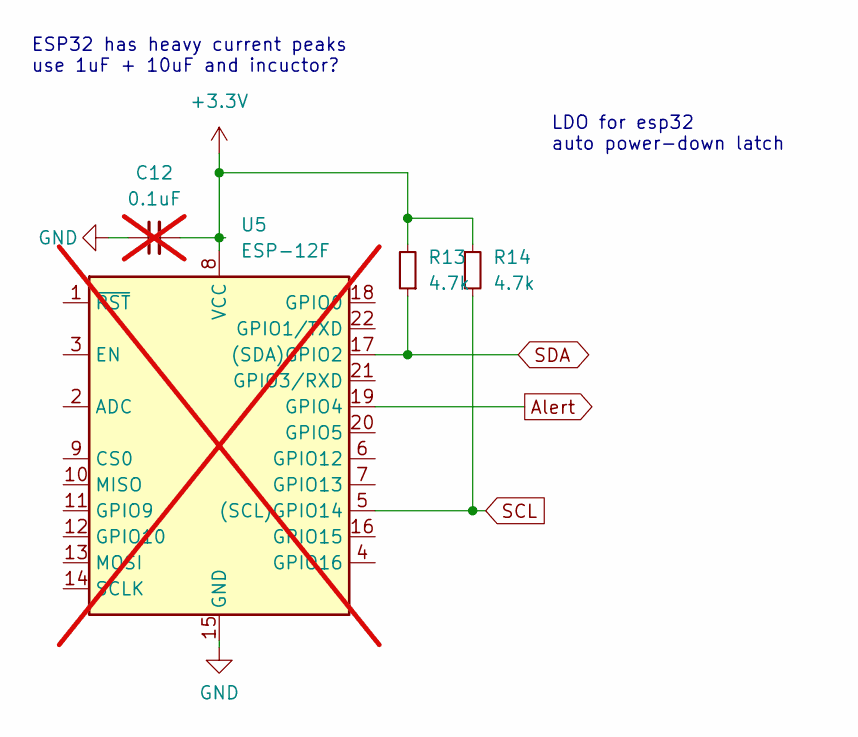
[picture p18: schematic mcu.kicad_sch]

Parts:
C12: 0.1uF; C_0805_2012Metric; not fitted
R13, R14: 4.7k; R_0805_2012Metric
U5: ESP-12F; ESP-12E; not fitted

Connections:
+3.3V: C12.2, R13.2, R14.1, U5.8 (VCC); also elsewhere on the board
unnamed: C12.1, U5.15 (GND)
SCL: R14.2, U5.5 ((SCL)GPIO14); also elsewhere on the board
SDA: R13.1, U5.17 ((SDA)GPIO2); also elsewhere on the board

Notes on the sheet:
ESP32 has heavy current peaks use 1uF + 10uF and incuctor?
LDO for esp32 auto power-down latch

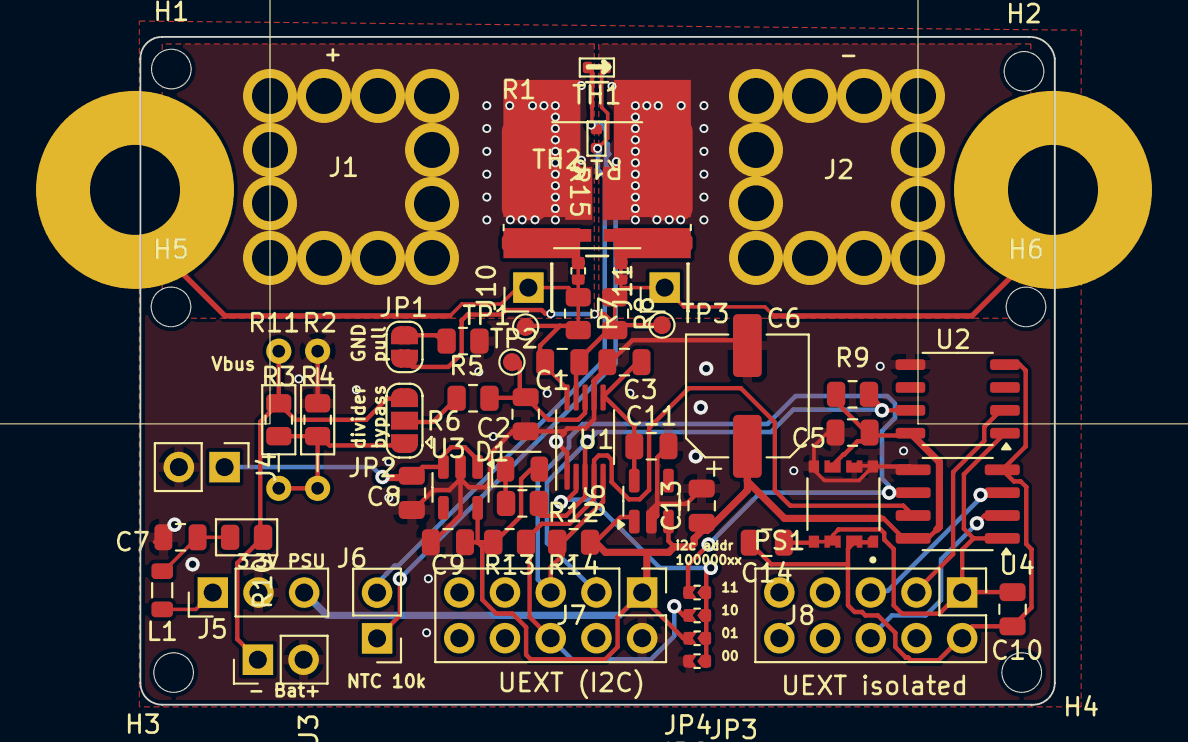
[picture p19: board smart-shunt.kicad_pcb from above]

Board: 2 copper layers, 50.8 x 37.1 mm, 66 parts (1 on the bottom side), 31 nets.

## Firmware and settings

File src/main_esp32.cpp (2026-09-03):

#include <Arduino.h>
#include <Wire.h>

#include <InfluxDbClient.h>
#include <map>
#include <vector>

#include "adc/adc_ads.h"
#include "adc/adc_esp.h"
#include "adc/ina226.h"
#include "adc/ina228.h"
#include "adc/ina228_mux.h"
#include "adc/ads1220.h"
#include "adc/ads1262.h"
#include "adc/ads131.h"

#ifdef WITH_LCD
#include "lcd.h"
#endif

#include "driver/uart.h"
#include "esp_timer.h"
#include "esp_ota_ops.h"
#include <WiFi.h>
#include "USB.h"

#include "ble.h"
#include "platform.h"
#include "sampler_registry.h"
#include "console.h"
#include "telemetry.h"
#include "energy_counter.h"
#include "util.h"
#include "adc/tmp117.h"
#ifdef WITH_RELAY_MUX
#include "relay_mux.h"
#include "adc/relay_mux_adc.h"
#endif

InfluxDBClient client;

PowerSampler_ADS ads;
PowerSampler_ADS131 ads131;
PowerSampler_INA226 ina226;
PowerSampler_INA228 ina228_40{0x40};

/* Second INA228 on the XIAO harness, strapped to 0x43 (ADD0 -> SCL). The
 * derived storage slots do not work at this address -- 2 + 3 = 5 is TMP117
 * 0x48 and 8 + 3 = 11 is mux channel B -- so both are passed explicitly from
 * the free high range (see CALIB_SLOT_FIRST_HIGH in settings.h). It has no
 * ALERT pin (Pin_INA22x_ALERT4 = 255) and samples on the 50 ms register-read
 * fallback in hasData(). */
PowerSampler_INA228 ina228_43{0x43, /*calibSlot=*/19, /*resistorSlot=*/20};

#ifdef DUAL_INA228
/* The 0x41 part on the two-INA228 variant is a PLAIN INA228, not a mux backend --
 * there is no TMUX8612 on that board. Its derived slots (3 and 9) are exactly the
 * ones INA228MuxBackend would have used for channel A and its resistor/range, so
 * the two builds never both need them; a board reflashed between variants simply
 * re-reads its own calibration into the same slots. */
PowerSampler_INA228 ina228_41{0x41};
#endif

INA228MuxBackend muxBackend{0x41, settings.Pin_INA22x_ALERT2,
                            settings.Pin_Mux_S1, settings.Pin_Mux_S2, settings.Pin_Mux_Zero};
PowerSampler_MuxChannel mux_chA{muxBackend, INA228MuxBackend::Target::CH_A, 3};
PowerSampler_MuxChannel mux_chB{muxBackend, INA228MuxBackend::Target::CH_B, 11};

/* One per ADD0 strap (GND/V+/SDA/SCL).  All four are registered unconditionally
 * and SamplerRegistry::initAll() drops whichever do not answer -- init() reads
 * DEVICE_ID first and returns false on no response, so an absent part costs one
 * failed transaction at boot and logs "init failed".  That beats hardcoding the
 * populated addresses: rebuilding the firmware is not the right response to
 * moving a strap. */
PowerSampler_TMP117 tmp117{0x48};
PowerSampler_TMP117 tmp117_49{0x49};
PowerSampler_TMP117 tmp117_4a{0x4A};
PowerSampler_TMP117 tmp117_4b{0x4B};

#if defined(SHUNT_ADC_ONLY) && !defined(XIAO_NEST)
/* A separate controller lets another default-address part coexist with bus 0;
 * storage slot 9 is unused by every sampler registered in this build. */
/* NOT on the XIAO: GPIO8 is D9 = J2.4/DIN there, so Wire1 would drive the
 * ADS1262's MOSI, and GPIO3 is D2 = the relay mux REQ_B line. */
static constexpr uint8_t TMP117_I2C2_SDA = 3;
static constexpr uint8_t TMP117_I2C2_SCL = 8;
static constexpr uint8_t TMP117_I2C2_STORAGE_ID = 9;
PowerSampler_TMP117 tmp117_i2c2{0x48, 1, TMP117_I2C2_STORAGE_ID};
#endif

/* pwr-metering shunt-adc board (ADS1262) on J2. Pins are the wiring, not
 * settings.h, because settings.h has no SPI entries for this board.
 *
 * J2 is revB: 1:3V3-IN 2:GND 3:SCLK 4:DIN 5:DOUT/DRDY 6:nCS 7:NC 8:START.
 * There is no dedicated /DRDY -- it rides DOUT (J2.5), which is why the driver
 * holds nCS low forever (SBAS661C 9.4.5). J2.7 MUST be left unconnected: on a
 * revA harness that pin is the isolator's /DRDY OUTPUT, so driving it is
 * output-into-output contention. Check the board silk for the revB marker.
 */
#ifdef XIAO_NEST
/* XIAO ESP32-S3, J2.3..J2.8 wired straight to D10..D5 (2026-09-02).
 *      J2.3 SCLK -> D10 = GPIO9    J2.6 nCS   -> D7 = GPIO44
 *      J2.4 DIN  -> D9  = GPIO8    J2.7 NC    -> not connected
 *      J2.5 DOUT -> D8  = GPIO7    J2.8 START -> D5 = GPIO6
 *
 * GPIO9 is AUX_PIN (aux_switch.h). This board has no aux load switch, so the
 * env builds with -D AUX_PIN_PRESENT=0; without it auxBegin() would pinMode()
 * the SCLK pad to OUTPUT and auxArmDeepSleepHold() would gpio_hold_en() it,
 * putting a held pad in contention with the SPI peripheral's clock.
 *
 * GPIO44 (nCS) is U0RXD and GPIO43 (D6, unused) is U0TXD. Neither is a
 * strapping pin, and the console is USB-CDC, so UART0 is free -- but the ROM
 * boot log still bursts out of GPIO43 at 115200 on every reset. Do not put a
 * signal that must stay quiet at boot on D6. */
static constexpr int8_t SHUNTADC_SCLK = 9, SHUNTADC_DIN = 8, SHUNTADC_DOUT = 7,
                        SHUNTADC_NCS = 44, SHUNTADC_START = 6;
#else
/* WARNING: on the XIAO these five collide with the INA228 alerts and the mux
 * (GPIO4=ALERT2, 5=ALERT3, 6=Mux_S1, 7=Mux_S2). This wiring is the N16R8 clone
 * bring-up map; pick one or the other per board before enabling both. */
static constexpr int8_t SHUNTADC_SCLK = 4, SHUNTADC_DIN = 5, SHUNTADC_DOUT = 6,
                        SHUNTADC_NCS = 7, SHUNTADC_START = 16;
#endif

Ads1262ShuntAdc shuntAdc;
/* Shunt current on J3 (IIN, PAIR_CH0). uPair = PAIR_NONE means no voltage
 * channel: u carries the raw shunt volts and p is pinned to 0. Give it a uPair
 * (J5 = PAIR_CH2, the old wiring) once a divider is actually fitted there, and
 * set dividerRatio at the same time.
 *
 * NO LONGER PARKED: with shuntAdcDcct below also registered, the device scans
 * CH0 <-> CH1. Every pair switch restarts the conversion cycle (td(STDR)
 * doubled to ~104 ms by chop), so EACH channel updates at ~4.8 SPS -- not the
 * 19.15 SPS the mux-parked configuration delivered. Still well above the
 * ~2.5 SPS on-air target.
 *
 * Each published sample is no noisier: it is still ONE conversion at the same
 * gain and filter. What degrades is the uncertainty of any FIXED-DURATION
 * average, by ~2x -- four times fewer CH0 conversions arrive per second, and
 * averaging error falls as sqrt(N). Comment out the DCCT registration below and
 * this channel parks again automatically (the device parks whenever exactly one
 * pair is registered).
 *
 * shuntOhm 2 mOhm: sized for 14 A => 28 mV, 80% of the 35 mV input window note N8
 * derives from G=32, leaving headroom for transients. Nominal, NOT calibrated --
 * gain error is whatever the resistor's tolerance is until it is measured against
 * a reference.
 *
 * storageId 12 continues past the existing samplers. */
PowerSampler_ShuntAdc shuntAdcIn{shuntAdc,
                                 Ads1262ShuntAdc::PAIR_NONE, Ads1262ShuntAdc::PAIR_CH0,
                                 /* shuntOhm = 2 mOhm nominal; dividerRatio 0 = no voltage
                                  * channel, so u stays raw ADC volts. */
                                 0.002f, 0.0f,
                                 /* storageId is a namespace shared by EVERY registered
                                  * sampler -- it indexes the EEPROM calibration slot
                                  * (settings.h: 16 + id*8). Taken: 0 (ADS/ADS131),
                                  * 2 (INA228 0x40), 3/11 (mux A/B), 5/6 (TMP117 0x48/0x49,
                                  * see STORAGE_ID_BASE in tmp117.h), 15 (Dummy). 5 aliased
                                  * TMP117 and would have silently shared its calibration. */
                                 12,
                                 SHUNTADC_SCLK, SHUNTADC_DIN, SHUNTADC_DOUT,
                                 SHUNTADC_NCS, SHUNTADC_START,
                                 /* reportDieTemp: DCCT below shares this ADS1262 but
                                  * deliberately opts out, so this remains the one
                                  * channel carrying the single die sensor -- and it is the
                                  * x-axis for the offset drift the shunt sizing
                                  * depends on. T read nan before this was set. */
                                 true};

/* Offset-drift characterisation: the ADC's INTERNAL short with chop OFF,
 * streamed through the normal sampler path. MUTUALLY EXCLUSIVE with shuntAdcIn
 * -- it parks the ADC in a different configuration -- so exactly one of the two
 * samplers.add() lines below may be active. 16 conversions per point at sinc4
 * 10 SPS, so ~1.6 s per point plus a one-time 400 ms settle (was ~0.8 s on the
 * production FIR @ 20 SPS; see ZERO_MODE1_VALUE in adc/ads1262.h). */
/* storageId 13: the ID indexes the shared EEPROM calibration slot
 * (settings.h: 16 + id*8). 6 aliased tmp117_49 -- tmp117.h computes
 * STORAGE_ID_BASE(5) + (0x49 - ADDR_MIN(0x48)) = 6 -- so both samplers would have
 * silently overwritten each other's calibration. Taken: 0, 2, 3, 5, 6, 11, 12, 15. */
/* avgN = 4: at ZERO_DATA_RATE_CODE (10 SPS) this is 400 ms per published
 * sample, i.e. the 2.5 SPS target. avgN = 16 was 1.6 s -> 0.625 SPS, which is
 * exactly the rate measured on the bench. Averaging deeper here also duplicates
 * work EnergyCounter/MeanWindow already does downstream; what the device-level
 * average buys is a sigma estimate over conversions taken in ONE undisturbed
 * configuration, and 4 is enough for that. The mean's uncertainty goes from
 * sd/4 to sd/2 -- about 3 nV to 7 nV at the measured 13 nV per-conversion
 * sigma, against a budget of 350 nV (10 ppm of 35 mV). */
/* DCCT primary current on J4 (PAIR_CH1): a 500:N current transformer into a
 * 5 Ohm burden resistor across AIN2(+)/AIN3(-). V_burden = I_primary * N/100,
 * so the envelope (2..40 A primary, N = 1..6 turns) spans 20 mV .. 2.4 V. At
 * G=1 the PGA's own output swing (Equation 12) still limits each input pin to
 * roughly -2.2..+2.2 V on these +-2.5 V rails, which a ground-referenced 2.4 V
 * peak clears by ~0.2 V, so this pair runs GAIN 1 with the PGA BYPASSED:
 * rail-to-rail input, +-VREF = +-2.5 V digital full scale. 2.4 V is 96% of FS;
 * prefer a turns
 * count with I*N <= ~200 A-turns when the setup allows headroom. Over-range is
 * ALSO policed digitally (DIAG_PGA_RANGE): the PGA monitors watch the PGA
 * output, which a bypassed signal never passes through, so they cannot be relied
 * on here -- though they are demonstrably not dead in bypass either, a floating
 * J4 having raised PGAH continuously on 2026-08-25.
 * G=1 noise (~1 uV/conversion) is ~50 ppm of the worst-case 20 mV
 * signal -- the DCCT ratio error and the burden's tolerance/tempco dominate.
 * Burden dissipation reaches (40*6/500)^2 * 5 = 1.15 W: fit a >= 3 W low-tempco
 * part, it is the metrology element.
 *
 * TIE THE BURDEN COLD END TO BOARD GND -- not optional. Without a DC path to the
 * board's reference the pair floats out of the +-2.6 V absolute input window,
 * and a CH1 driven HARD out of range corrupts its NEIGHBOUR: on 2026-08-25 it
 * put a 7.2 mV offset on CH0 (3.6 A of phantom shunt current) and made the
 * internal die-temperature read return 1503 degC, because the mux now visits
 * both pairs and the front end had not recovered by the next conversion. A
 * merely FLOATING CH1 does not do this -- only a driven one.
 *
 * FIELD MAPPING (same convention as the other overloaded channels): u is the
 * raw burden voltage in VOLTS at the ADC input (dividerRatio 0 = unscaled,
 * doubles as a range readout), i is the PRIMARY current in AMPERES, p = 0.
 *
 * shuntOhm 0.01 is the N=1 effective transresistance (5 Ohm * 1/500). The
 * turns ratio is applied at runtime through the EXISTING per-sampler
 * calibration: after re-rigging, `calibrate DCCT I <1/N>` on the console
 * (0.5 for N=2 ... 0.1667 for N=6; EEPROM-persisted). i is only correct for
 * the rigged N -- and note a trim calibration lives in the SAME factor, so
 * changing N overwrites trim.
 *
 * storageId 10: taken are 0 (ADS/ADS131), 1 (INA226), 2 (INA228 0x40),
 * 3/11 (mux A/B), 5/6/7 (TMP117 0x48-0x4A), 16 (TMP117 0x4B), 9 (SHUNT_ADC_ONLY
 * TMP117), 12/13/14 (shunt/zero/health), 15 (Dummy), 19/20 (INA228 0x43
 * calib + resistor/range, assigned explicitly -- see ina228_43).
 *
 * Slot 8 is NOT free despite no getStorageId() returning it: PowerSampler_INA228
 * is a SECOND consumer of this same EEPROM namespace, storing resistor/range at
 * 8 + (addr - I2C_A0) (ina228.h:186) independently of its own storageId of 2.
 * Grepping getStorageId() alone therefore understates what is taken -- 10 was
 * checked against both. */
PowerSampler_ShuntAdc shuntAdcDcct{shuntAdc,
                                   Ads1262ShuntAdc::PAIR_NONE, Ads1262ShuntAdc::PAIR_CH1,
                                   0.01f, 0.0f,
                                   10,
                                   SHUNTADC_SCLK, SHUNTADC_DIN, SHUNTADC_DOUT,
                                   SHUNTADC_NCS, SHUNTADC_START,
                                   /* reportDieTemp: CH0 already carries it */ false,
                                   /* pgaGainCode */ 0, /* pgaBypass */ true};

PowerSampler_ShuntAdcZero shuntAdcZero{shuntAdc, 4, 13,
                                       SHUNTADC_SCLK, SHUNTADC_DIN, SHUNTADC_DOUT,
                                       SHUNTADC_NCS, SHUNTADC_START};

/* Front-end health as a recorded series: u = fCLK (Hz), i = AVDD-AVSS (V).
 * Publishes cached values only -- it drives no conversions of its own, so it is
 * free to register alongside whichever measurement channel is active. 30 s is
 * far faster than either quantity can meaningfully move, and the failure this
 * exists to catch ran for 35 minutes before the board died.
 * storageId 14: taken are 0, 2, 3, 5, 6, 11, 12, 13, 15. */
PowerSampler_ShuntAdcHealth shuntAdcHealth{shuntAdc, 30000, 14,
                                           SHUNTADC_SCLK, SHUNTADC_DIN, SHUNTADC_DOUT,
                                           SHUNTADC_NCS, SHUNTADC_START};

#ifdef WITH_RELAY_MUX
/* Coto 3502 relay mux (~/dev/ee/hw/dmm-mux-TMUX862/relay-mux) feeding the
 * ads1262-divider board into ONE ADS1262 pair. Off by default -- build with
 * -D WITH_RELAY_MUX to enable -- because turning it on costs the running rig
 * measurably and depends on wiring that is not on the board yet:
 *
 *   - registering a third pair slows EVERY channel. Two registered pairs already
 *     took SHUNT_ADC and DCCT from 19.15 to ~4.8 SPS each, because a pair switch
 *     restarts the conversion; a third divides the scan again.
 *   - the three control lines and the JST-XH control cable to J4 do not exist yet.
 *
 * PINS ARE THE WIRING, NOT A PREFERENCE. Chosen clear of every pin settings.h
 * declares for this board -- ADS1262 SPI (4/5/6/7/16), both I2C buses (3/8 and
 * 11/12), AUX (9), and the declared-but-unregistered ADS131 map (5/6/7/9/11/12/13)
 * -- but they are still a guess about a harness nobody has built. Confirm against
 * the actual cable before trusting a reading, and change them here, not in
 * settings.h, exactly as the ADS1262 SPI pins above are handled.
 *
 * Which pair the divider lands on is a WIRING FACT, so it is per-board. */
#if defined(RELAY_MUX_ONLY) || defined(XIAO_NEST)
/* XIAO ESP32-S3: relay mux control on D0/D1/D2. The XIAO breaks out just 11
 * GPIOs -- D0..D10 = 1,2,3,4,5,6,43,44,7,8,9 -- and GPIO2/3 are the I2C pins in
 * the XIAO settings branch, which is why these builds skip the I2C bring-up
 * entirely: there is nothing on the bus to find.
 *
 * Clear of this board's ADS1262 SPI (9/8/7/44/6) -- see SHUNTADC_* above. */
static constexpr uint8_t RELAYMUX_ARM = 1, RELAYMUX_REQ_A = 2, RELAYMUX_REQ_B = 3;
#else
static constexpr uint8_t RELAYMUX_ARM = 17, RELAYMUX_REQ_A = 18, RELAYMUX_REQ_B = 21;
#endif

#ifdef XIAO_NEST
/* MEASURED ON THE RISER, not assumed: 1 V into the mux's left input (IN_B open),
 * mux output through the voltage divider, divider into the ADS1262's CH0 = J3.
 * Confirmed by Fab at the bench 2026-09-03. */
#  define RELAYMUX_ADC_PAIR Ads1262ShuntAdc::PAIR_CH0
#else
/* PAIR_CH2 = J5 was the divider's ASSUMED landing point on the N16R8 rig and has
 * never been confirmed against a cable. If the divider is on J6, use PAIR_CH3. */
#  define RELAYMUX_ADC_PAIR Ads1262ShuntAdc::PAIR_CH2
#endif

RelayMux2 relayMux{RELAYMUX_ARM, RELAYMUX_REQ_A, RELAYMUX_REQ_B};
RelayMuxAdcBackend relayMuxAdc{relayMux, shuntAdc, RELAYMUX_ADC_PAIR};

/* storageId 21/22: the EEPROM calibration namespace is shared by every registered
 * sampler AND by INA228's separate resistor/range store. Taken across all builds:
 * 0, 2, 3, 5, 6, 9, 10, 11, 12, 13, 14, 15, 19, 20, plus 8+ for INA228 ranges;
 * 17/18 are permanently unusable (they overlap the aux state and board prefix
 * bytes). 21/22 are the next two free slots above CALIB_SLOT_FIRST_HIGH.
 *
 * dividerRatio 0: the ads1262-divider board's ratio is a bench fact measured
 * against a reference, not a nameplate number, so both channels publish RAW ADC
 * VOLTS until it is set. That is the same contract SHUNT_ADC uses, and it fails
 * visibly (millivolts where volts belong) rather than plausibly. */
PowerSampler_RelayMuxChannel relayMuxChA{relayMuxAdc, RelayMux2::Target::CH_A, 21, 0.0f,
                                         SHUNTADC_SCLK, SHUNTADC_DIN, SHUNTADC_DOUT,
                                         SHUNTADC_NCS, SHUNTADC_START,
                                         /* reportDieTemp: SHUNT_ADC is not registered in
                                          * this build, so without this the ADS1262 die
                                          * sensor goes unrecorded entirely. Exactly one
                                          * channel opts in -- there is one sensor. */
                                         true};
PowerSampler_RelayMuxChannel relayMuxChB{relayMuxAdc, RelayMux2::Target::CH_B, 22, 0.0f,
                                         SHUNTADC_SCLK, SHUNTADC_DIN, SHUNTADC_DOUT,
                                         SHUNTADC_NCS, SHUNTADC_START};
#endif

SamplerRegistry samplers;
BleSrv bleSrv;

volatile bool g_samplingHalted = false;
bool disableWifi = true;
bool wifiTimeSyncOnly = true;

class EspTelemetry : public Telemetry {
public:
    using Telemetry::Telemetry;

private:
    std::vector<WireSample> wireSampleBuf;
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
void loop() { vTaskDelay(1000); }

[[noreturn]] void appTask(void *arg) {
    (void)arg;
    while (1) {
        wifi_tick();
        otaBleTick(millis());
        telemetry->update(false);
        if (otaBleActive()) {
            telemetry->noteWakeEvent();
        } else {
            telemetry->checkIdleSleep();
        }
        markOtaValidIfHealthy();
        vTaskDelay(10);
    }
}

const int BUF_SIZE = 1024;
QueueHandle_t uart_queue;

void uartInit(int port_num) {
    uart_config_t uart_config = {
        .baud_rate = 115200,
        .data_bits = UART_DATA_8_BITS,
        .parity = UART_PARITY_DISABLE,
        .stop_bits = UART_STOP_BITS_1,
        .flow_ctrl = UART_HW_FLOWCTRL_DISABLE,
        .source_clk = UART_SCLK_APB,
    };
#if CONFIG_IDF_TARGET_ESP32S3
    const int PIN_TX = 43, PIN_RX = 44;
#else
    const int PIN_TX = 1, PIN_RX = 3;
#endif
    const auto port = (uart_port_t) port_num;
    ESP_ERROR_CHECK(uart_set_pin(port, PIN_TX, PIN_RX, UART_PIN_NO_CHANGE, UART_PIN_NO_CHANGE));
    ESP_ERROR_CHECK(uart_param_config(port, &uart_config));
    ESP_ERROR_CHECK(uart_driver_install(port, BUF_SIZE * 2, BUF_SIZE * 2, 10, &uart_queue, 0));
}

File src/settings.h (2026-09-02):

#pragma once

#include <EEPROM.h>

/* Boot CPU clock for the ESP32 targets. 80 MHz is both the default and the floor --
 * the reasoning, and what breaks below it, is in main_esp32.cpp next to the call.
 * Declared here so the console's `cpufreq` command can report what a reboot returns
 * to. Override per env with -D CPU_FREQ_MHZ=160. */
#ifndef CPU_FREQ_MHZ
#define CPU_FREQ_MHZ 80
#endif

/* Calibration slot map, shared by both targets. Slot n occupies bytes
 * 16 + n*8 .. +7 of a 256-byte image.
 *
 * 16 was the cap because slot 16 ends at byte 151 and byte 152 begins the aux
 * switch state (aux_switch.h), with the board prefix behind it at 154..162 --
 * so slots 17 and 18 would overwrite them and are PERMANENTLY UNUSABLE, not
 * merely unallocated. Slot 19 starts at 168, clear of the prefix; slot 29 ends
 * at 255, the last that fits. */
static constexpr uint8_t CALIB_SLOT_MAX = 29;
static constexpr uint8_t CALIB_SLOT_FIRST_HIGH = 19;

#ifdef TARGET_STM32H5
#include "esp_compat.h"
#include <cassert>

struct settings_t {
    int8_t Pin_I2C_SDA = PB_4;
    int8_t Pin_I2C_SCL = PB_5;
    uint8_t Pin_INA22x_ALERT = PA10;
    uint8_t Pin_INA22x_ALERT2 = PC7;
    uint8_t Pin_INA22x_ALERT3 = PC6;
    uint8_t Pin_INA22x_ALERT4 = 255;
    uint8_t Pin_Mux_S1 = PC9;
    uint8_t Pin_Mux_S2 = PC8;
    uint8_t Pin_Mux_Zero = PB10;

    uint8_t Pin_ADS1220_CS = 0;
    uint8_t Pin_ADS1220_DRDY = 0;
    uint8_t Pin_ADS1262_START = 0;
    uint8_t Pin_ADS1262_PWDN = 0;
    uint8_t Pin_ADS131_Clk = 0;
    uint8_t Pin_ADS131_Miso = 0;
    uint8_t Pin_ADS131_Mosi = 0;
    uint8_t Pin_ADS131_Cs = 0;
    uint8_t Pin_ADS131_CsClk = 0;
    uint8_t Pin_ADS131_Drdy = 0;
    uint8_t Pin_ADS131_Rst = 0;
};

static settings_t settings;

static bool readCalibrationFactors(size_t ecIndex, float &u, float &i);

static void storeCalibrationFactors(uint8_t ecIndex, float u, float i) {
    assert(ecIndex <= CALIB_SLOT_MAX);
    assert(ecIndex <= 16 || ecIndex >= CALIB_SLOT_FIRST_HIGH); // 17/18 hit aux state + board prefix
    EEPROM.put(16 + ecIndex * 4 * 2 + 0, u);
    EEPROM.put(16 + ecIndex * 4 * 2 + 4, i);
}

static bool checkCalibrationFactorBounds(float f) {
    if (!std::isnormal(f))
        return false;
    if (std::abs(f) < (1 / 10e4)) {
        return false;
    }
    return f > -10e3 and f < 10e3;
}

static bool readCalibrationFactors(size_t ecIndex, float &u, float &i) {
    assert(ecIndex <= CALIB_SLOT_MAX);
    assert(ecIndex <= 16 || ecIndex >= CALIB_SLOT_FIRST_HIGH); // 17/18 hit aux state + board prefix
    EEPROM.get(16 + ecIndex * 4 * 2 + 0, u);
    EEPROM.get(16 + ecIndex * 4 * 2 + 4, i);
    return checkCalibrationFactorBounds(u) and checkCalibrationFactorBounds(i);
}

#else

#define XIAO_ESP32S3 1
#define WAVESHARE_MINI 0
#define GREEN_DAQ_BREAD_BOARD 0
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

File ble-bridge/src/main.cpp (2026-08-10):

#include <Arduino.h>

#include <esp_log.h>
#include <NimBLEDevice.h>

#include "ble_protocol.h"

#define SERVICE_UUID        "e8308d3d-c3b4-45ff-ba58-9c0fb99d0ecb"
#define CHARACTERISTIC_UUID "df51a73d-0b60-43a5-bc86-a043f3841152"
#define AUX_CHAR_UUID       "b952dad5-9541-4852-bab6-96b9cbc9131a"

#define UART_BAUD 115200
#define UART_RX_BUF 1024

static NimBLEServer *pServer = nullptr;
static NimBLECharacteristic *pTelemetryChar = nullptr;
static NimBLECharacteristic *pAuxChar = nullptr;

static volatile bool bleConnected = false;
static volatile bool bleSubscribed = false;

#define MAX_FRAME_PAYLOAD 255
static uint8_t rxBuf[MAX_FRAME_PAYLOAD + 16];
static size_t rxLen = 0;

enum class RxState : uint8_t { WAIT_SOF0, WAIT_SOF1, WAIT_TYPE, WAIT_LEN_HI, WAIT_LEN_LO, WAIT_PAYLOAD, WAIT_CRC_HI, WAIT_CRC_LO };
static RxState rxState = RxState::WAIT_SOF0;
static uint8_t rxType = 0;
static uint16_t rxPayloadLen = 0;
static uint16_t rxCrc = 0;

static void ble_crc16_update(uint16_t &crc, uint8_t b) {
    crc ^= (uint16_t)b;
    for (int j = 0; j < 8; j++) {
        if (crc & 1) { crc >>= 1; crc ^= 0xA001; }
        else { crc >>= 1; }
    }
}

static void sendFrameToSTM32(uint8_t type, const uint8_t *data, uint16_t len) {
    uint8_t txBuf[256];
    size_t pos = 0;
    txBuf[pos++] = BLE_PROTO_FRAME_SOF0;
    txBuf[pos++] = BLE_PROTO_FRAME_SOF1;
    txBuf[pos++] = type;
    txBuf[pos++] = (uint8_t)(len >> 8);
    txBuf[pos++] = (uint8_t)(len & 0xFF);

    uint16_t crc = 0xFFFF;
    ble_crc16_update(crc, type);
    ble_crc16_update(crc, (uint8_t)(len >> 8));
    ble_crc16_update(crc, (uint8_t)(len & 0xFF));
    for (uint16_t i = 0; i < len; i++) {
        txBuf[pos++] = data[i];
        ble_crc16_update(crc, data[i]);
    }
    txBuf[pos++] = (uint8_t)(crc >> 8);
    txBuf[pos++] = (uint8_t)(crc & 0xFF);
    Serial1.write(txBuf, pos);
}

static bool parseAuxCommand(const uint8_t *data, size_t len, uint8_t &out) {
    if (!data || !len) return false;
    if (len == 1 && (data[0] == 0 || data[0] == 1)) { out = data[0]; return true; }

    String s;
    for (size_t i = 0; i < len; ++i) s += (char)data[i];
    s.trim();
    s.toLowerCase();

    if (s == "1" || s == "on" || s == "true") { out = 1; return true; }
    if (s == "0" || s == "off" || s == "false") { out = 0; return true; }
    if (s == "toggle") { out = 0xFF; return true; }
    return false;
}

static void processFrame(uint8_t type, const uint8_t *payload, uint16_t len) {
    switch (type) {
        case BLE_MSG_TELEMETRY:
            if (pTelemetryChar && bleSubscribed) {
                pTelemetryChar->setValue((uint8_t *)payload, len);
                pTelemetryChar->indicate();
            }
            break;
        case BLE_MSG_AUX_STATE:
            if (pAuxChar) {
                if (len >= 1) {
                    uint8_t v = payload[0] ? '1' : '0';
                    pAuxChar->setValue(&v, 1);
                    if (bleConnected) pAuxChar->notify(&v, 1);
                }
            }
            break;
        default:
            break;
    }
}

static void processUartRx() {
    while (Serial1.available()) {
        uint8_t b = Serial1.read();

        switch (rxState) {
            case RxState::WAIT_SOF0:
                if (b == BLE_PROTO_FRAME_SOF0) rxState = RxState::WAIT_SOF1;
                break;
            case RxState::WAIT_SOF1:
                if (b == BLE_PROTO_FRAME_SOF1) rxState = RxState::WAIT_TYPE;
                else if (b == BLE_PROTO_FRAME_SOF0) { }
                else rxState = RxState::WAIT_SOF0;
                break;
            case RxState::WAIT_TYPE:
                rxType = b;
                rxState = RxState::WAIT_LEN_HI;
                break;
            case RxState::WAIT_LEN_HI:
                rxPayloadLen = (uint16_t)b << 8;
                rxState = RxState::WAIT_LEN_LO;
                break;
            case RxState::WAIT_LEN_LO:
                rxPayloadLen |= b;
                if (rxPayloadLen > MAX_FRAME_PAYLOAD) {
                    rxState = RxState::WAIT_SOF0;
                } else if (rxPayloadLen == 0) {
                    rxState = RxState::WAIT_CRC_HI;
                } else {
                    rxLen = 0;
                    rxState = RxState::WAIT_PAYLOAD;
                }
                break;
            case RxState::WAIT_PAYLOAD:
                rxBuf[rxLen++] = b;
                if (rxLen >= rxPayloadLen) rxState = RxState::WAIT_CRC_HI;
                break;
            case RxState::WAIT_CRC_HI:
                rxCrc = (uint16_t)b << 8;
                rxState = RxState::WAIT_CRC_LO;
                break;
            case RxState::WAIT_CRC_LO: {
                rxCrc |= b;
                uint16_t calc = 0xFFFF;
                ble_crc16_update(calc, rxType);
                ble_crc16_update(calc, (uint8_t)(rxPayloadLen >> 8));
                ble_crc16_update(calc, (uint8_t)(rxPayloadLen & 0xFF));
                for (uint16_t i = 0; i < rxPayloadLen; i++)
                    ble_crc16_update(calc, rxBuf[i]);
                if (calc == rxCrc) {
                    processFrame(rxType, rxBuf, rxPayloadLen);
                } else {
                    ESP_LOGW("bridge", "CRC mismatch: got 0x%04X, expected 0x%04X", rxCrc, calc);
                }
                rxState = RxState::WAIT_SOF0;
                break;
            }
        }
    }
}

class ServerCallbacks : public NimBLEServerCallbacks {
    void onConnect(NimBLEServer *server, NimBLEConnInfo &connInfo) override {
        bleConnected = true;
    }
    void onDisconnect(NimBLEServer *server, NimBLEConnInfo &connInfo, int reason) override {
        bleConnected = false;
        bleSubscribed = false;
        sendFrameToSTM32(BLE_MSG_LINK_STATUS, (uint8_t[]){0}, 1);
        NimBLEDevice::startAdvertising();
    }
};

class TelemetryCallbacks : public NimBLECharacteristicCallbacks {
    void onSubscribe(NimBLECharacteristic *chr, NimBLEConnInfo &connInfo, uint16_t subValue) override {
        if (subValue >= 2) {
            bleSubscribed = true;
            sendFrameToSTM32(BLE_MSG_LINK_STATUS, (uint8_t[]){1}, 1);
        } else if (subValue == 0) {
            bleSubscribed = false;
            sendFrameToSTM32(BLE_MSG_LINK_STATUS, (uint8_t[]){0}, 1);
        }
    }
};

class AuxCallbacks : public NimBLECharacteristicCallbacks {
    void onWrite(NimBLECharacteristic *chr, NimBLEConnInfo &connInfo) override {
        std::string val = chr->getValue();
        uint8_t cmd;
        if (parseAuxCommand((const uint8_t *)val.data(), val.length(), cmd)) {
            sendFrameToSTM32(BLE_MSG_AUX_SET, &cmd, 1);
        }
    }
};

static ServerCallbacks serverCallbacks;
static TelemetryCallbacks telemetryCallbacks;
static AuxCallbacks auxCallbacks;
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

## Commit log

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2026-08-05 rename src/math.h, it was shadowing the C++ <math.h>
    src/ is on the include path, so #include <math.h> from inside <cmath> resolved
    to this project's 6-line MeanWindow header instead of the toolchain's. Every
    std:: math declaration then vanished, and the build died in <cmath> itself
    ("'acos' has not been declared in '::'", then an ambiguous sqrt overload in
    __hypot3) -- a hundred lines of errors pointing at library code with nothing
    wrong with it. One include site, so this is a rename and a one-line edit.
    [energy_counter.h]
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2026-08-05 bench config: green DAQ breadboard pinout, slower upload
    I2C on 42/38 with ALERT on 40, selected by a new GREEN_DAQ_BREAD_BOARD branch.
    upload_speed back to 115200 and the port globs widened to /dev/cu.usb* -- the
    board enumerates as usbserial, not usbmodem.
    Note ALERT2/ALERT3 are both 0 here, so the two INA228s in use (0x41, 0x42) ask
    attachInterrupt() for the same GPIO and the second binding silently replaces the
    first. One of them therefore never gets a conversion-ready interrupt and falls
    back to the 50 ms poll in hasData(). It still works, just slower, and nothing
    says so. GPIO 0 is also the strapping pin.
    [settings.h]
2026-08-05 build: pin the platform, fix the errors that had accumulated
    This project no longer built at all, for four reasons that had nothing to do
    with each other and everything to do with an unpinned toolchain.
    `platform = espressif32` floated to the newest release, whose arduino-esp32 3.x
    ships the NimBLE host inside libbt.a. NimBLE-Arduino compiles the same stack
    from its own sources, so the link died on `multiple definition of
    ble_sm_alg_gen_dhkey' -- the build broke with no change to this repo. Pinned to
    6.11.0 (arduino-esp32 2.0.17), where libbt.a is Bluedroid-only.
    Then the compile errors the newer headers had been hiding: uartInit() passed an
    int where uart_port_t was wanted, and main.cpp u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
    [main.cpp]
2026-08-05 i2c: one driver stack behind one lock, and stop aborting on a failed write
    i2c.h drove I2C_NUM_0 through the raw IDF driver while adc/ina228.h drove the
    SAME port through Arduino Wire -- from a different task, on a different core,
    with nothing serialising them. i2c_write_short() is reachable at runtime from
    the serial console (`calibrate`, `ina22x-resistor-range` -> setResistorRange),
    handled in nonRealTimeTask on core 0, while realTimeTask reads the INA228s
    continuously on core 1. Interleaving a raw transaction into Wire's in-flight
    state can corrupt the transfer or wedge the bus, and there is no bus-recovery
    routine anywhere in this firmware, so a wedge means a power cycle.
    So i2c.h is no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
    [i2c.h, ina228.h]
2026-08-05 ec: stall detection that survives a micros() rollover, without blocking
    Two bugs in the same six lines.
    if (nowTime > lt && (nowTime - lt) > 4e6 && nowTime > 10e6)
    The unsigned subtraction in the middle is the correct rollover-safe idiom. The
    `nowTime > lt` in front of it destroyed that. micros() wraps every 71.6 min, so
    a stall beginning shortly before a wrap leaves nowTime numerically below a stale
    lt for up to another 71 minutes -- the recovery path switches itself off for
    that whole window, i.e. exactly when a sensor has just died. The `nowTime > 10e6`
    boot grace re-armed itself on every wrap for the same reason. Both now run on
    the 64-bit esp_timer clock, which does not wrap.
    The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
    [energy_counter.h]
2026-08-05 ble: stop buffering samples nobody can receive
    Running unconnected, bleBuf filled within seconds and then every single sample
    logged "ble buf overflow, dropping sample" -- forever, once per sample. The
    noise is not the real problem: it is the SAME message a genuine overflow with a
    peer attached produces, so the one warning that matters was buried under
    thousands that did not. send() now discards immediately when nothing is
    subscribed, counts what it dropped, and says how many were lost once a
    subscriber does attach. A real backlog drop gets its own distinct message.
    Nothing was reset on disconnect either, so a stale bleBufPos and a stale
    waitingForAck carried into the next connection, where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
    [ble.h]
2026-08-05 secrets: move the wifi credentials out of the tracked source
    connect_wifi_async() had three SSID/password pairs as string literals, and this
    remote is a public repository. They now come from src/secrets.h, which is
    gitignored, with secrets.h.example as the template. A missing secrets.h is a
    hard compile error, not a silent build without wifi.
    Note this does not undo the existing exposure: "modellbau" is already reachable
    in the pushed history (c7626d1, e254879, 9e16c75). Rotating that PSK, or
    scrubbing history, is a separate decision.
    [util.cpp]
2026-08-05 settings: the bench board is the waveshare mini, not the green DAQ
    I2C on 3/2 with ALERT on 1/4/5. Supersedes the GREEN_DAQ_BREAD_BOARD selection
    in a5549dc: on 42/38 nothing acknowledged on the bus at all -- all three INA228s
    read Manufacturer ID 0x0000 and failed to initialize, leaving only the dummy
    sampler. On 3/2 they enumerate correctly (0x5449 / 0x2281) and sample.
    [settings.h]
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2026-08-05 calib: stop applying the firmware voltage gain factor
    calibFactorU multiplied every published voltage sample before it left the
    device, so recorded data depended on hidden EEPROM state. The factor is keyed
    to the INA228's I2C address (storageId = 2 + i2c_addr - I2C_A0), not to the
    chip, so it survives a chip swap and a reflash -- a factor left over from an
    earlier campaign reads back as a gain shift of the sensor itself. That is a
    plausible cause of the ~100 ppm non-monotonic gain steps seen on INA228_2
    between the 2025-02, 2025-10 and 2026-08 linearity campaigns.
    Voltage calibration lives host-side now (calibration/polynom.py in
    pwr-metering), where it is versioned and visible in the fit.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
    [energy_counter.h, main.cpp]
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2026-08-07 idle-sleep: only power channels get a vote
    looksActive() reads a non-finite mean power as "cannot judge -> stay awake",
    which is right for a power channel: NaN there means a disabled channel or a
    failed read. It is wrong for a temperature-only sampler, whose mean power is
    NaN by construction, forever. Since the vote was OR'd over all counters,
    registering the TMP117 pinned the whole board awake permanently.
    So PowerSampler gains measuresPower(), defaulting to true -- a sampler must opt
    OUT deliberately, because a wrong answer here should fail toward "stays awake",
    never toward "sleeps while there is data" -- and TMP117 overrides it to false.
    The vote is now tallied across the window instea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
    [main.cpp, tmp117.h]
2026-08-07 tmp117: give each part its own EEPROM calibration slot
    getStorageId() returned a hardcoded 5, so every TMP117 instance claimed the same
    EEPROM calibration slot (main.cpp passes it as EnergyCounter's eePromIndex) and
    they overwrote each other silently. PowerSampler_INA228 already derives its slot
    from the address -- 2 + addr - 0x40, giving 2..4 for 0x40..0x42 -- so do the same
    here: 5 + addr - 0x48, giving 5..8.
    The damage was bounded today, since those factors are U/I gains and a temperature
    -only sampler never meaningfully applies them (APPLY_U_GAIN_CAL=0 and i is NaN),
    but it is silent aliasing and it becomes real the moment anything else keys off
    storageId.
    PowerSampler_Dummy also retur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
    [main.cpp, tmp117.cpp, tmp117.h]
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2026-08-09 ble: let the module announce its own rejections
    It now emits OTAB FAIL on the status channel for a malformed command, so
    appending a second line here would just duplicate it.
    [ble.h]
2026-08-09 ble: drop undelivered OTA status on disconnect
    It belongs to the session that ended; carrying it over hands the next
    client the previous one's READY/FAIL lines and desynchronises its line
    parser. Same reason the telemetry buffer clears on sessionChanged.
    [ble.h]
2026-08-09 aux: a switched GPIO output, driven over BLE
    GPIO 10, active-high. New characteristic on the existing service (READ |
    WRITE | NOTIFY, value is a single ASCII '0'/'1'), plus an 'aux
    [on|off|toggle]' console command for when no client is attached.
    The write callback only latches: applying the switch persists to NVS, and
    an NVS commit is a flash write, which must never run on the NimBLE host
    task. Same split the OTA path already uses.
    State survives resets, which needs two things that are easy to miss:
    - A magic byte in NVS separates 'never written' from 'written off'. A
    virgin blob reads back as zeros, so without it a blank device would be
    indistinguishable from one commanded on -- and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
    [aux_switch.h, ble.h, main.cpp]
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2026-08-10 port: Phase 3 — 64-bit timer, Stop mode, review fixes
    Phase 2 review fixes (9 bugs):
    - taskYIELD() → vTaskDelay(1) in realTimeTask (was starving NRT task)
    - Wire.setSDA/setSCL before Wire.begin() (I2C pins were never applied)
    - Energy integration uses micros() not millis()*1000 (1us vs 1ms resolution)
    - Aux toggle (0xFF) handled in ble_bridge, publishAux after auxSet
    - pinsAreShorted(7,8) guarded out for STM32 (used ESP32 pin numbers)
    - Serial.setTimeout(10) before readString (was blocking 1s)
    - Pin_Mux_S2/Pin_INA22x_ALERT3 conflict resolved (ALERT3 → PC7)
    - ble-bridge: NimBLE 2.5.1 callback signatures fixed
    - ble-bridge: aux parsing uses full string parser (off/false no longer → ON)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
    [energy_counter.h, ina228.h, main.cpp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]
2026-08-10 port: Phase 3 review fixes
    - inline (not static inline) for esp_timer_get_time: shared overflow counter across TUs
    - Stop mode deferred: no RTC handle available in STM32duino, logging instead of one-way trip
    - ble-bridge: NIMBLE_SUBSCRIBE_INDICATING → subValue >= 2 (constant doesn't exist)
    - ble-bridge: handle unsubscription (subValue == 0) in onSubscribe
    - ble-bridge: send LINK_STATUS(0) on disconnect
    - ble-bridge: merge duplicate build_flags in platformio.ini
    [main.cpp]
2026-08-10 board: add XIAO ESP32S3 pin config, AUX on GPIO9
    XIAO ESP32S3 has the same GPIO1-6 pinout as the Waveshare ESP32-S3-Zero,
    but GPIO10 (the old AUX pin) is not broken out. Move AUX to GPIO9.
    [aux_switch.h, settings.h]
2026-08-10 port: flash + runtime fixes
    Fixes discovered during flashing and runtime testing:
    - std::map<std::string,...> crashes at static init on STM32H5 (heap
    not ready): replaced with plain C array of structs
    - Wire.setSDA/setSCL crashes (I2C instance mismatch): use -D PIN_WIRE_SDA/PIN_WIRE_SCL
    build flags to override variant defaults (PB7/PB8 for I2C1)
    - HardwareSerial BleSerial(PB15,PB14) global constructor hangs (pins on
    different UART instances): replaced with StubBleBridge for now
    - Remove #include <map> from STM32 section
    Firmware boots, I2C bus initialized on PB7/PB8, no devices found
    (expected — sensor board not yet wired). Serial console works via
    STLINK VCP at 115200 baud.
    [main.cpp, settings.h]
2026-08-10 refactor: abstraction layers + split main.cpp
    Extract shared logic into platform-independent abstractions so both
    ESP32-S3 and STM32H5 targets share one codebase:
    - platform.h: timer, EEPROM, restart, GPIO hold, task creation
    - ble_transport.h: virtual BleTransport interface (send/tick/flush/
    isConnected/publishAux), implemented by BleSrv (ESP32 NimBLE) and
    BleBridge (STM32 UART), with StubBleTransport for testing
    - sampler_registry.h: fixed-size registry replacing std::map (which
    crashed on STM32 static init), shared by both targets
    - console.h: shared command handler (calibrate, aux, reset, help)
    - telemetry.h: shared telemetry output + idle-sleep vote logic,
    virtual onIdleSleep()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
    [ble.h, console.h, energy_counter.h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]
2026-08-10 fix: 9 code review findings
    1. BUG: OTA sleep race — update(false) + checkIdleSleep() after OTA check
    2. REGRESSION: ESP32 WiFi/Influx — onSummary/onTelemetryFlush hooks in EspTelemetry
    3. REGRESSION: ESP32 raw UART console — processConsole() override with uart_read_bytes
    4. BUG: STM32 vTaskStartScheduler() — added after task creation
    5. RISK: STM32 stack 2048→1024 words, xTaskCreate return checked, Telemetry static
    6. REGRESSION: bootinfo command restored (ESP32), watchdog failure ESP_LOGE restored
    7. RISK: publishAux(bool) unified — argument is state, not notify flag
    8. RISK: esp32 legacy env — build_src_filter added
    9. RISK: telemetry.h — forward-declare handleConsoleInput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
    [ble.h, console.h, main_esp32.cpp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]
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2026-08-10 fix: 4 remaining review findings
    1. wifi on/off console commands restored (ESP32-only, with WiFi.h include)
    2. OTA confirmation failure now logs ESP_LOGE on mark_app_valid failure
    3. Duplicate AUX notification: removed from BleSrv::tick(), Telemetry::update()
    is now the single source of truth for aux state-change notifications
    4. STM32 heap validation: log free heap + low-heap warning before scheduler start
    [ble.h, console.h, main_esp32.cpp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]
2026-08-10 fix: 3 remaining reviewer findings
    1. wifi on: added wait_for_wifi() after connect_wifi_async() so it actually connects
    2. BleSrv::tick(): restore reconnect AUX publish (auxPublished == -1 guard),
    so new clients get initial aux state without duplicating change notifications
    3. STM32 heap log: removed misleading uxTaskGetStackHighWaterMark(NULL) call
    (reports wrong task before scheduler start); just log free heap
    [ble.h, console.h, main_stm32.cpp]
2026-08-10 fix: wifi on no longer blocks app task
    wifi on sets flags + calls connect_wifi_async() (adds APs) but does NOT
    call wait_for_wifi() (which has an unbounded loop). Instead, wifi_poll()
    drives wifiMulti.run() from the app task loop on each pass when WiFi is
    enabled. This prevents the app task from wedging if no AP is reachable.
    [console.h, main_esp32.cpp, util.cpp]
2026-08-10 fix: wifi_tick() replaces wifi_poll() — no blocking call in app task
    wifi_tick() is a non-blocking state machine:
    - If disabled: disconnect and return
    - If connected: return
    - If idle: call connect_wifi_async() (adds APs, does not block) and start retry timer
    - If connecting: check 10s retry interval, then reset to idle
    No wifiMulti.run() or WiFi.scanNetworks() is called from appTask.
    connect_wifi_async() only calls wifiMulti.addAP() which is non-blocking.
    The actual WiFi connection attempt is left to the ESP-IDF WiFi stack.
    [main_esp32.cpp, util.cpp]
2026-08-10 fix: WiFi moved to dedicated low-priority task, no appTask blocking
    wifiTask (priority 0, core 0, 4KB stack) calls wifiMulti.run() in a loop.
    This is the only place wifiMulti.run() is called — it can block for scan
    duration without affecting appTask (priority 1) or realTimeTask (priority 20).
    wifi_tick() in appTask is now a no-op. wifi on/off just toggles disableWifi;
    the wifiTask sees the flag on its next pass and connects/disconnects.
    [main_esp32.cpp, util.cpp]
2026-08-10 fix: WiFi concurrency — console flag-only, wifiTask owns all WiFi calls
    Console wifi on/off now only sets g_wifiRequest (volatile int) — no direct
    connect_wifi_async(), WiFi.disconnect(), or WiFiMulti mutation from console.
    wifiTask exclusively owns connect_wifi_async(), wifiMulti.run(), and
    WiFi.disconnect(). Uses apsAdded flag so addAP() is called once per connect
    cycle, not while run() iterates APlist. xTaskCreatePinnedToCore return
    checked for wifiTask.
    [console.h, main_esp32.cpp, util.cpp]
2026-08-10 fix: WiFi state bugs — unconditional disconnect+radio off, no AP re-add
    1. wifi off: WiFi.disconnect(true, true) + WiFi.mode(WIFI_OFF) unconditionally
    on enabled→disabled transition (was only if WL_CONNECTED, leaving radio on
    after failed attempts). Guarded by wasEnabled flag so it fires exactly once.
    2. AP list: connect_wifi_async() called once per enable cycle via apsAdded flag,
    never re-adds duplicates. WiFiMulti APlist persists for task lifetime.
    3. Boot init: g_wifiRequest set consistently — 0 if wifiTimeSyncOnly disconnects,
    1 if WiFi stays enabled after boot setup.
    [main_esp32.cpp, util.cpp]
2026-08-10 fix: AP list populated once for task lifetime, not re-added on re-enable
    Remove apsAdded=false from the disable branch. APs are added once when
    wifiTask first sees a connect request and never re-added, so WiFiMulti
    APlist never grows with duplicate entries across off/on cycles.
    [util.cpp]
2026-08-10 fix: AP list idempotent — connect_wifi_async_once() shared guard
    connect_wifi_async_once() uses a shared static bool (wifiApsAdded) so APs
    are added exactly once regardless of whether setup() or wifiTask calls it.
    Boot path and wifiTask both use the idempotent wrapper. No duplicate AP
    entries possible across any boot/off/on sequence.
    [main_esp32.cpp, util.cpp]
2026-08-10 fix: WireSample energy field + remove broken [env:esp32]
    summary() never set ws.data.e, so BLE telemetry and InfluxDB
    reported E=0 for every sample. Add s.e = (float)energy alongside
    the other wire-sample field assignments.
    Remove the legacy [env:esp32] environment — it was broken (wrong
    settings struct, no NimBLE dep, compiled both mains) and ESP32-S3
    is the active target. Update README board selection accordingly.
    [energy_counter.h]
2026-08-10 fix: XIAO ESP32S3 GPIO4 conflict — move Mux_S1 to GPIO6
    GPIO4 was double-assigned to Pin_INA22x_ALERT2 (interrupt input)
    and Pin_Mux_S1 (mux select output). Both are used by
    INA228MuxBackend::init() — the pin was configured as INPUT_PULLUP
    then overwritten to OUTPUT, breaking both the alert interrupt and
    mux channel selection.
    GPIO6 is the only free non-strapping pin on the XIAO header. It
    was assigned to dormant ADS1220_DRDY (never registered/initialized).
    [settings.h]
2026-08-14 ADS1262: vendor TI driver, add shunt-adc sampler and bench bring-up
    Vendored TI's official ADS1262/ADS1263 example driver and reworked the
    sampler for the pwr-metering shunt-adc board (revB), replacing the
    ProtoCentral-based version.
    lib/ti_ads126x/
    ads1263.c/.h are upstream, byte-identical (TexasInstruments/
    precision-adc-examples @ fb4a86a, devices/ads1262). Only the HAL is
    ours: upstream's targets an MSP432E401Y with driverlib. TI's original
    hal.c/hal.h are kept under upstream/ for reference. One upstream bug
    worked around without touching the file: ads1263.c uses NULL without
    including <stddef.h> -- xtensa-gcc pulls it in transitively, arm-none-
    eabi-gcc does not.
    The boa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
    [ads1262.cpp, ads1262.h]
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2026-08-14 ADS1262: run the bench checks at init so failures name their own cause
    The bench probe could tell a user what was wrong, but only if they went
    looking. These move the same checks into init(), so a board that cannot
    measure correctly refuses to start and says why.
    checkClock() -- times real conversions and infers fCLK from
    measured_rate / nominal_rate. This is the check the whole session turned
    on: EXTCLK=1 means an external clock was DETECTED, never that it is
    USABLE. A floating XTAL1 picking up ~30 kHz of noise reads EXTCLK=1 and
    produces well-formed conversions at 1/240 the expected rate, and nothing
    in the STATUS byte says so. Fails outside the 1..8 MHz the part accepts
    (sec.7.3), warns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
    [ads1262.h]
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2026-08-14 ADS1262: enable chop, and measure what it costs
    Chop measured on this board with the internal shorted input at G=32, over
    two runs:
    mode mean(uV) sigma(uV) rate(SPS)
    chop off +7.1248 0.0358 20.00
    chop on +0.0000 0.0243 19.15
    7.13 uV of input-referred offset is 204 ppm of a 35 mV shunt signal, so
    without chop the offset term alone misses a 10 ppm budget by 20x. Chop
    removes it. Noise improves 1.48x, matching the datasheet's stated 1.4x.
    The cost is NOT the halved throughput I first assumed. Two different
    equations apply to two different things, and only one of them bites:
    - steady-state throughput, Eq.21 = 1/td(STDR): 19.15 vs 20.00 SPS, 4%
    - FIRS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
    [ads1262.h]
2026-08-14 ADS1262: register the shunt-adc through SamplerRegistry, hold one config
    Replaces the standalone bench main with the repo's real sampler pipeline.
    main_shuntadc.cpp hand-built WireSamples and drove BleSrv directly, and it
    called send() without flush() -- so nothing ever shipped and the bridge
    reconnected every 15 s. Registering PowerSampler_ShuntAdcZero via
    SamplerRegistry::add() gets the EnergyCounter averaging, the EEPROM
    calibration slot and the working transport for free.
    Zero path: enterZeroMode() is now idempotent on the programmed chop bits, so
    consecutive samples touch no registers at all. Reconfiguring per sample walked
    the part through chop OFF->ON->OFF and gain 32->1->32 between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
    [ads1262.h, energy_counter.h, main_esp32.cpp]
2026-08-14 ADS1262: sinc4 @ 10 SPS for the zero channel, SI-prefixed console
    Zero-drift channel
    ------------------
    Switch PowerSampler_ShuntAdcZero from the production FIR @ 20 SPS to
    sinc4 @ 10 SPS (ZERO_MODE1_VALUE / ZERO_DATA_RATE_CODE). Measured on the
    Feather and confirmed in InfluxDB: noise floor drops from 3.5e-8 V to
    1.4e-8 V, against SBAS661C Table 8-1's 0.013 uVRMS for sinc4/10 SPS/G=32.
    The rate matters as much as the order. Sinc notches sit at multiples of
    the data rate, so the rate must divide the line frequency: 10 divides 50,
    20 does not, which is why sinc4 @ 20 SPS collapses to -72 dB at 50 Hz
    (Table 9-6) where 10 SPS gives -136 dB.
    The production mux scan deliberately stays on FIR.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
    [ads1262.h, energy_counter.h, main_esp32.cpp]
2026-08-14 ADS1262: zero channel 0.63 -> 2.45 SPS, from measurement not guesswork
    Three constants, each now carrying the bench number that justifies it.
    avgN 16 -> 4 (main_esp32.cpp). This was the whole shortfall: 16 conversions
    at ZERO_DATA_RATE_CODE's 10 SPS is 1.600 s per published sample = 0.625 SPS,
    and the bench measured 0.63. Four conversions is 400 ms, i.e. the 2.5 SPS
    target. Averaging deeper here also duplicates what EnergyCounter/MeanWindow
    already do downstream; what the device-level average buys is a sigma estimate
    over conversions taken in ONE undisturbed configuration. The mean's
    uncertainty goes from sd/4 to sd/2 -- 3 nV to 7 nV at the measured 13 nV
    per-conversion sigma, against a bud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
    [ads1262.h, main_esp32.cpp]
2026-08-15 ADS1262: chop ON for the zero channel, and two timeouts it broke
    Chop
    ----
    zeroDriftSample() now measures with MODE0_CHOP_ON. The chop-off run had
    answered its question: the offset took ~2 h to settle onto 7.2525 uV,
    rising 104 nV, and die temperature could not explain it -- the same 0.6 C
    change produced 104 nV during the transient and 2.4 nV after it (measured
    2026-08-15, 15-min buckets, n~2150 each, standard error 0.23 nV). 104 nV
    is ~3 ppm of a 35 mV full scale, a third of the 10 ppm budget spent before
    the first reading.
    Measured with chop on, immediately: offset -1.0 to +2.3 nV against the
    +-0.1/G uV typ spec (+-3.1 nV at G=32), a ~7000x reduction, and the noise
    floor improved from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
    [ads1262.h]
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
